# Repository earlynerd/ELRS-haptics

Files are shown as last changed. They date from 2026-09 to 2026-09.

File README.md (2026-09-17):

# Haptic bracelet

Battery-powered attitude feedback for FPV flying, with eight haptic actuators around each wrist. An ESP32-C6 receives telemetry over ESP-NOW and controls eight M2003FC1AE/DRV2625 pods using the music robot's UART ring architecture. Each wrist uses a seven-cell parallel battery group: protected cells in pods 1-7, with no cell in the stacked controller pod. Seven 90 mAh cells give 630 mAh; 301730/160 mAh cells are an alternative candidate pending selection and fit checks.

## Open the two KiCad projects

| PCBA | Editable project | Quantity per wrist |
| --- | --- | --- |
| Controller daughterboard | [hardware/main/main.kicad_pro](hardware/main/main.kicad_pro) | 1 |
| Universal pod | [hardware/satellite/satellite.kicad_pro](hardware/satellite/satellite.kicad_pro) | 8 |

Each project has its own schematic and PCB. Shared custom libraries live under `hardware/`. Use KiCad 10; native files are the editable source of truth.

**JP1 defaults to 1-2 NORMAL. On the last satellite, cut the 1-2 copper bridge and solder 2-3 END.** Its centre pad feeds the upstream return, selecting downstream return or local TX. Never bridge all three. See [project structure and jumper configuration](docs/pcba-projects.md).

The former eight-island project is retained under `hardware/archive/combined-project/`, with the untouched starting snapshot and hashes under `hardware/backups/before-two-projects/`. Close any editor still showing the former root project and open the new projects above for further work.

## Schematics and layout

The main project has five sheets: the user's redrawn controller/power-switch top sheet, stacked universal-pod interface, charger/regulator, USB, and controller support. The satellite has one sheet. Support components are wired around their ICs; labels serve power rails and circuit/sheet interfaces.

[Main schematic PDF](hardware/verification/project-split/main.pdf) · [Satellite schematic PDF](hardware/verification/project-split/satellite.pdf) · [Satellite layers](hardware/verification/project-split/layers.png)

The redraw audit found no deleted components, changed values or changed footprint assignments. The new `+3V3` and `+3V3_POD` power symbols had split the old `3V3` and `POD_3V3` nets; those names are now consistent. An obsolete dangling QOD wire/label was removed. Fresh connectivity checks preserve the verified circuit apart from the documented selector, five-pad harness, reset removal and USB simplification.

Both boards now use the pod's full **20 × 46 mm, R2.5** outside contour. The universal skin-facing board has four M1.6 SMT standoff lands and no actuator cutout; the controller plate has matching 1.8 mm screw-clearance holes. The VLV041235L retains its factory adhesive. Drawing layers mark the TPU contact band and placement margin. See [PCB sandwich construction](docs/pcb-sandwich.md).

All existing electrical positions and routes are preserved, including the user's latest main placement. Both projects have zero ERC and schematic/PCB parity issues. The universal board retains 201 segments, 42 vias, zero DRC violations and zero opens. The controller has 146 opens and 21 DRC findings during placement, including clashes around the new mounts. Both active stackups remain four-layer, 0.8 mm; standoff height and thinner skin-plate trials are open. See [current architecture](docs/pcba-projects.md).

## System decisions

- Five wires run through seven gaps: switched supply, GND, forwarded UART data, protected VBAT and serial return. The compact five-pad banks use pin 4 for VBAT and pin 5 for return. The eighth gap has no conductor; the current housing uses paired planar U-flexures at all eight gaps and closes the flat strip at a seam inside the main shell.
- Each pod contains an M2003FC1AE, DRV2625YFFR and VLV041235L. PF0/PF1 preserve the loader UART/ICE pins. Driver NRST follows VDD; hard recovery cycles pod power.
- USB-C uses two 5.1k CC pull-downs and connects to ESP32-C6 native Serial/JTAG on GPIO12/13. VBUS directly feeds the charger; its internal limit replaces external USB current-switch circuitry. BQ25186 charges the protected pack, TPS63802 supplies 3.3 V, and TPS22918 switches all pod electronics.
- Every pod has local bulk capacitance, removable UART links, ICE pads and an optional cell thermistor interface. Each protected battery feeds VBAT through its local branch fuse; factory PCMs stay fitted.
- Main SW3 is the wake/ship button; D1 is the RGB status LED. Firmware must manage charging and UART pin states around power changes.

See [ring and power sequencing](docs/ring-pods.md), [power architecture](docs/power-architecture.md), [USB implementation](docs/usb-power-implementation.md), and [DECISIONS.md](DECISIONS.md).

## Firmware

The initial [bracelet firmware](firmware/README.md) now includes an ESP32-C6 controller, an M2003 haptic-pod application, the borrowed music-robot LDROM build, and portable protocol tests. The controller decodes MSPv2-wrapped CRSF attitude telemetry from a configured ExpressLRS Backpack sender, requires exactly eight enumerated pods, and drives a configurable absolute-attitude map at 50 Hz. The M2003 application controls one DRV2625 over local I2C and keeps the robot ring framing, enumeration, loader mailbox, image layout, and update packager.

The stacked hardware retains eight nodes but requires cell-temperature supervision on pods 1-7 only; that firmware policy and seven-cell charging limits remain to be implemented.

The first build defaults are deliberately inert until a Backpack source MAC is configured. Charging remains disabled. This code has been compiled, but it has not been flashed or exercised on bracelet hardware; see [firmware interfaces and open qualifications](firmware/protocol.md).

For staged hardware work, the controller now has a native USB [bring-up console](firmware/BRINGUP.md). It supports partial-ring enumeration, per-pod status and bounded single-actuator pulses without relaxing the eight-pod requirement for normal telemetry-driven output.

## Next work and manufacturing

Next establish the stacked daughterboard envelope, contact arrangement and placement before routing. JLCPCB is preferred; a later **derived panel** may combine one controller and eight identical universal pods. [hardware/panel](hardware/panel/README.md) is reserved for that output. No manufacturing panel or fabrication release has been created.

The exact production stack, USB geometry, enclosure supports/links, physical fit, battery sharing, power sequencing and haptic behavior remain to validate. Firmware is implemented as an initial buildable slice but has not been flashed. Loader compatibility is now build-verified against the inspected robot sources, not yet demonstrated on the bracelet ring.

`tools/verify_split_projects.ps1` refreshes both netlists, ERC/DRC reports and preservation checks. Current evidence is in `hardware/verification/project-split/`. Older construction scripts and routing directories document earlier revisions; do not use them to regenerate the active designs.

## References

- [Nuvoton M2003 datasheet](https://www.nuvoton.com/export/resource-files/en-us--DS_M2003_Series_EN_Rev1.00.pdf).
- [TI DRV2625 datasheet](https://www.ti.com/lit/ds/symlink/drv2625.pdf).
- [TI TPS22918 datasheet](https://www.ti.com/lit/ds/symlink/tps22918.pdf).
- [ESP32-C6-MINI-1 datasheet](https://www.espressif.com/sites/default/files/documentation/esp32-c6-mini-1_mini-1u_datasheet_en.pdf).
- [ExpressLRS backpack telemetry](https://www.expresslrs.org/software/backpack-telemetry/).

Power/USB source details and loader provenance are linked from the implementation documents.

The proposed [VLV041235L actuator and draft flex contact footprint](docs/lra-candidate.md) are documented separately; the actuator is assigned to main M1 and satellite M1.

The [dimensional pod study](mechanical/pod-study/README.md) uses the measured 195 mm wrist. Revision D proposes 20 x 38 x 10.5 mm regular shells and a 24 x 64 x 10.5 mm main shell, with one protected 3 x 12 x 32 mm battery bonded inside every lid. The main battery is allocated away from the antenna and USB/button/RGB end. Width around the wrist stays unchanged. These are nominal shell envelopes; revision 0.6 implements PCB outlines and fit coupons but has no physical fit evidence.

The current [Myo-inspired flat housing v0.11](mechanical/myo-flat-v0.11/README.md) supports the main-pod TPU against its sidewalls down to the satellite ends, so all sixteen free U-folds use the same geometry. Its main clamshell is cut from one rounded rectangular envelope, with integrated end walls and recessed M2 x 8 mm screws. Satellite shells, lids and joint geometry are preserved. The approximately 239 x 72 mm strip targets PET-GF15/TPU on the H2D; local support remains necessary under the terminal roof and wall feet. STL/3MF, STEP and main-transition/closure coupons are included. CAD, mesh and preservation checks pass; the user's slicer screenshot is v0.10 evidence, while v0.11 slicing, fit and flexure testing remain open. Earlier releases are preserved.

SW3 is the accessible wake/off button. D1 is a discrete common-anode RGB status LED on GPIO4/5/15, with individual resistors; the placement selects LTST-C19HE1WT and EVQPUJ02K, respectively. See [standby and controls](docs/standby-and-controls.md). Initial firmware uses blue for waiting, green for fresh telemetry/output, and red for a ring fault; final indication and button behavior remain open.

The [YDL301230-class battery baseline](docs/cell-candidate-301230.md) provides 630 mAh and 315 mA continuous aggregate current with seven equally sharing cells. Factory PCMs stay intact. New 22 uF pod capacitors and C42=4.7 nF ramp control are documented in [ring power](docs/ring-pods.md).

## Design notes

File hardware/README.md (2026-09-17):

# Hardware sources

Open `main/main.kicad_pro` and `satellite/satellite.kicad_pro` in KiCad 10.

- `main/`: one controller daughterboard PCBA; its haptic pod is a separate universal board.
- `satellite/`: one universal PCBA, built eight times per wrist. JP1 selects normal or end-of-chain operation.
- `HapticBracelet.kicad_sym`, `HapticBracelet.pretty/`: shared libraries referenced by both projects.
- `panel/`: future derived manufacturing panel, never the source for board edits.
- `verification/project-split/`: current schematic PDFs, previews and check reports.
- `archive/combined-project/`: superseded eight-island project, preserved intact.
- `backups/`: historical snapshots, including the saved user redraw before migration.

Both boards now use the regular pod's full 20 × 46 mm, R2.5 outside contour. Four M1.6 standoff lands on the universal lower board match four 1.8 mm clearance holes on the controller plate. Neither board has an actuator opening. Cmts.User marks the 1.2 mm TPU contact band; Dwgs.User marks a 1.5 mm placement inset. Existing electrical positions and routes are preserved. See [PCB sandwich construction](../docs/pcb-sandwich.md) for mounting height and placement status. Schematics and boards are edited natively; construction scripts are migration provenance.

Current topology and checks: [stacked controller architecture](../docs/pcba-projects.md). Pod 0 has no cell or external NTC; pods 1-7 have both.

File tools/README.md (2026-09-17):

# Hardware scripts

The active designs are native KiCad projects under `hardware/main/` and `hardware/satellite/`.

## Placement measurements

Save the PCB, then run from the project root:

```powershell
./tools/evaluate_placement.ps1
./tools/evaluate_placement.ps1 -ExcludeNet '^GND$'
./tools/evaluate_placement.ps1 -Compare 'hardware/verification/placement-score/PREVIOUS/placement.json'
```

Each invocation creates a timestamped report directory and leaves the PCB untouched. `placement.md` is the readable report; `placement.json` contains every measured connection, per-net and incident-component totals, source hash and KiCad version. `drc.json` and `drc.log` retain the native checks. `-Board` selects another PCB; `-Out` selects an explicit output directory. Comparison requires matching pad/net topology and filters. Unsaved editor placement is not visible to this tool.

Two distinct measures are reported: fresh KiCad DRC unconnected endpoint spans (remaining airwires), and a Euclidean minimum spanning tree over each net's copper pad centres (routing-independent placement proxy). Reported statistics are count, total, mean, median, nearest-rank P95 and maximum, in mm. Every copper pad is included, including same-footprint/duplicate-number pads; coincident pads contribute zero-length edges. The latter can change the mean relative to KiCad's ratsnest even when totals agree. No nets are excluded by default. Ground-only filtering is useful but does not imply all other nets are signals.

The remaining-airwire measurement is an estimate reconstructed from native unconnected item pairs and nearest pad-centre/track-end/via anchors, rather than direct access to the editor's displayed ratsnest. DRC track positions identify a track's start, so the tool resolves the nearer endpoint. Unsupported endpoints such as zone objects cause an explicit error rather than an invented distance. This is tested on unrouted, partially routed and fully routed fixtures.

Use total length to compare placements of the same circuit. Existing routing, planes, layer transitions, obstacles, trace width and electrical priority are not modeled by the placement tree. Native DRC uses saved zone fills without modifying/refilling them. Short circuits can also affect native connectivity, so inspect DRC alongside the metrics. A lower score is not a fabrication or placement acceptance gate. Critical power loops, decoupling, RF/USB, enclosure constraints and courtyard clearance remain separate checks.

Tests (KiCad Python):

```powershell
& 'C:/Program Files/KiCad/10.0/bin/python.exe' tools/test_evaluate_placement.py
```

Run `verify_split_projects.ps1` to export current netlists, run ERC/DRC and verify preservation of the accepted circuit/placement. It does not regenerate schematics or PCBs. The comparison baseline must be deliberately updated when future circuit or placement changes are accepted.

`redraw_projects.py`, `readable_schematic.py`, `split_pcb_projects.py`, `route_satellite_selector.py` and `render_split_projects.cjs` record the two-project migration. Mutation entry points require explicit migration flags and are not incremental editors. In particular, repeating the selector router would duplicate tracks.

Earlier scripts target the archived eight-island architecture. Their reports remain in historical verification directories; they are not the active validation or generation workflow. Do not run an old generator against the new project structure.

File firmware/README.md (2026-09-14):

# Bracelet firmware

This directory contains the first firmware slice for one wrist:

- `common/` is portable C for ring framing, MSPv2/CRSF attitude decoding, and the configurable eight-pod attitude map.
- `controller/` is the ESP32-C6 ESP-IDF application. It receives ExpressLRS Backpack CRSF telemetry over ESP-NOW and masters the 250 kbaud pod ring.
- `pod/` is the M2003FC1AE application plus a build wrapper around the proven music-robot LDROM and support sources.
- `tests/` exercises the portable protocol core without hardware.

The checked-in defaults are intentionally safe. The charger enable remains low. Pod power starts off. Haptics are sent only after exactly eight applications enumerate and a configured Backpack sender supplies a fresh, valid attitude frame. Loss of telemetry or ring echo requests an all-stop.

The ESP32-C6 also exposes a native USB Serial/JTAG bring-up console. It can enumerate a partial ring, inspect DRV2625 calibration/status, exercise one actuator with a bounded pulse, display the most recent attitude frame, stop output, and power-cycle the pod rail. Bus and actuator diagnostics latch manual mode; normal telemetry control resumes only after an explicit `hb flight` command and only with eight enumerated pods. See [BRINGUP.md](BRINGUP.md).

This is build evidence, not flashed-hardware evidence. Rail timing, UART signal integrity, loader interception, DRV2625/LRA tuning, temperature conversion, charging policy, and the final wrist-direction map remain bench work.

## Build

Controller (PlatformIO, ESP-IDF):

```powershell
pio run --project-dir firmware/controller
```

Portable tests (CMake plus any desktop C compiler):

```powershell
cmake -S firmware/tests -B firmware/tests/build
cmake --build firmware/tests/build
ctest --test-dir firmware/tests/build --output-on-failure
```

Pod application and unchanged borrowed LDROM:

```powershell
make -C firmware/pod ROBOT_ROOT=C:/Users/mmsyl/Documents/bl4818-servo-M23_2 images
```

The M2003 build fails early if `ROBOT_ROOT` does not contain the expected support tree. This makes the current provenance visible rather than silently copying a second vendor BSP. Pin and image-layout details are in [protocol.md](protocol.md).

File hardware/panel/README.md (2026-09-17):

# Future manufacturing panel

Panelization is deferred until both individual PCB designs are complete.

The intended starting quantity is one controller daughterboard plus eight identical universal pods per wrist. Both designs are four-layer, nominally 0.8 mm. All satellites use the same Gerbers and assembly configuration; the final satellite's JP1 is changed by cutting 1–2 and soldering 2–3.

Create a future panel here as a derived output from `../main/main.kicad_pcb` and `../satellite/satellite.kicad_pcb`, recording source hashes and the selected JLCPCB stack and panel rules. Keep BOM/reference namespaces unambiguous between PCBAs. Rails, tabs, breakaways, fiducials, tooling and assembly outputs will be chosen at that stage.

Do not edit individual circuits in the panel. No panel PCB or fabrication exports have been created here.

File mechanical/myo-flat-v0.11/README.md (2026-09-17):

# Main-pod refinement — v0.11

This revision addresses the user's v0.10 slicer screenshot. The long TPU sections beside the main pod now contact its outside walls down to the satellite end positions (local Y=±22 mm). All sixteen free U-folds use the same geometry, with a 1.2 × 9.5 mm ribbon cross-section. Matching free geometry removes the deliberately longer main free legs; actual joint stiffness still needs a printed trial.

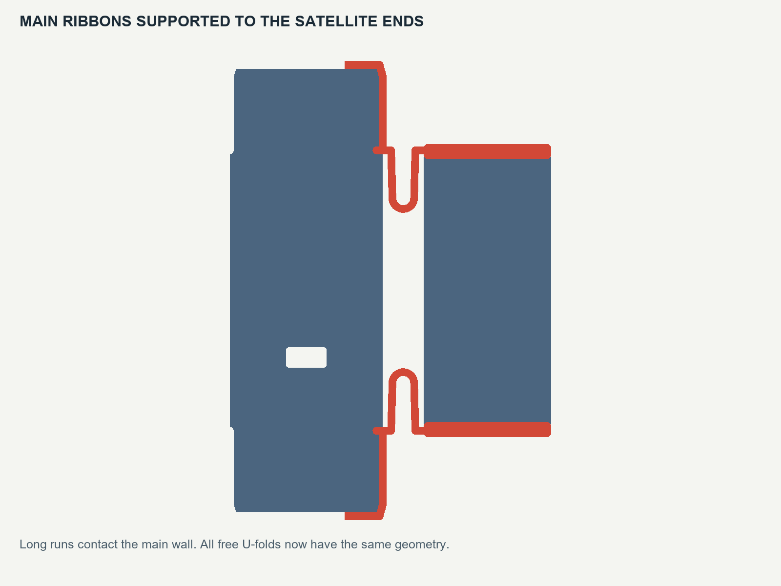
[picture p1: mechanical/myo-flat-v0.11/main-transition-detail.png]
Supported main transition


The main case is rebuilt by subtracting the cavity, access openings and mating cuts from one **24 × 72 × 11.5 mm rectangular envelope with rounded corners**. It closes into a continuous box exterior, with the service openings retained. Continuous internal end walls replace the isolated standoffs. Two cavity depths leave the PCB bearing ledges in the original solid. The wrist-facing floor and outward-facing roof still print at opposite strip ends.

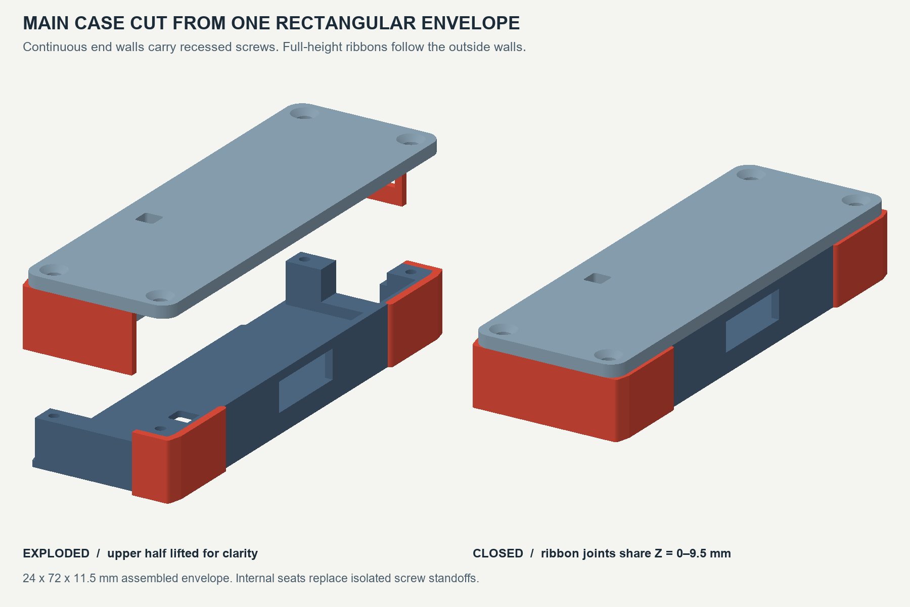
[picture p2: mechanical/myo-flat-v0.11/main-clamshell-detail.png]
Main case assembly

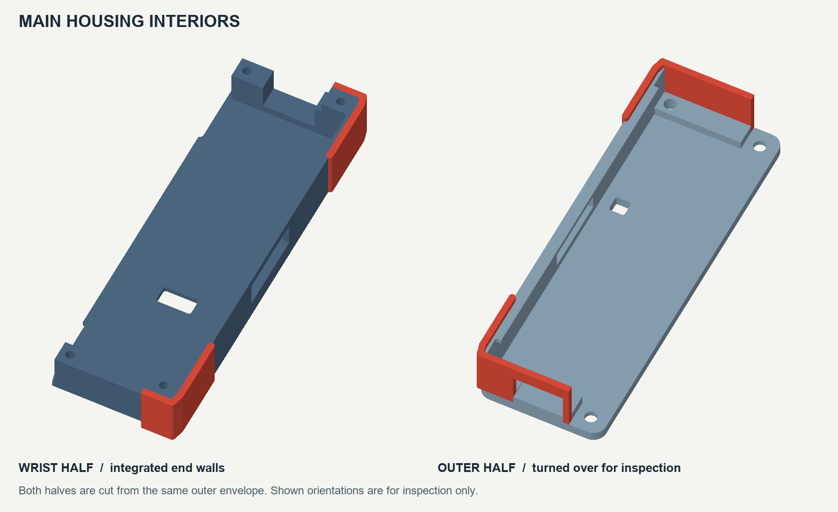
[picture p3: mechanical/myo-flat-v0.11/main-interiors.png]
Both interiors


The stepped seam keeps the ribbon ends at a common Z=0–9.5 mm. They butt together at the wall handoff when the case closes. Pockets in the lower half receive the upper half's TPU inlays. Main end ribbons are 1.2 mm wide; satellite embedded end rails remain 2.4 mm wide. The narrower main inlay leaves 1.2 mm of nominal rigid material between each end-wall pilot and the adjacent cavity/inlay boundary. A local USB cutout remains in the embedded rail, clear of the butt joints and free folds.

## Files and printing

| File | Purpose |
|---|---|
| [Full strip 3MF](print/myo-flat-band.3mf) | One dual-material strip, nine rigid pieces forming eight assembled pods |
| [Satellite lid](print/satellite-lid.stl) | Print seven; main roof is already in the strip |
| [Main transition coupon](print/main-transition-coupon.3mf) | New supported main-to-satellite joint |
| [Main fit parts](print/main-clamshell-fit-parts.stl) | Both main halves for a small fit trial |
| [Terminal closure coupon](print/closure-transition-coupon.3mf) | Upper main half and last satellite |
| [Satellite coupon](print/end-flexure-coupon.3mf) | Retained two-satellite joint |
| [Flat STEP](cad/flat-strip.step) | Full strip with separate rigid and soft bodies |
| [Assembled main STEP](cad/main-clamshell-assembled.step) | Both main halves at their closed datums |
| [CAD source](../../tools/build_myo_flat_v011.py) | Editable generator |
| [Overview](design-overview.png) | Actual flat meshes and illustrative oval pose |

The **239.2 × 72 × 11.5 mm** strip retains the H2D layout. Assign PET-GF15 and TPU to the aligned rigid/soft parts and retain their common coordinates. The generic 3MF contains material labels, not a printer process preset; bonding remains slicer-managed as requested. Support is still needed under the terminal main roof and wall feet. Do not independently drop the upper rigid half to the bed: its wall feet start at Z=1 mm while its attached TPU starts at Z=0. Satellite shells, lids and free joint geometry are retained.

**Main fasteners change to four M2 × 8 mm countersunk screws.** Modeled engagement is 4 mm in the two internal end walls and 6 mm on the opposite side, with 1 mm tip-to-pilot-bottom clearance. Satellite fasteners remain fourteen M2 × 5 mm countersunk screws. Seats assume 90-degree heads, 4.1 mm diameter, and 1.6 mm pilots. Check pilot fit and torque using the main fit parts in the chosen PET-GF15.

Print the new main transition coupon and clamshell fit parts first. Check sidewall bonding, equal/unequal fold motion, support removal, case closure and screw fit before the complete band. Keep the seven wired gaps and one unwired gap; populated component fit, board retention and harness strain relief remain physical development work.

## Evidence

`cad-checks.json` records valid CAD and STEP reimports, board/cell/USB clearance, all sixteen neighbor contacts, four main sidewall-contact gauges, full-height butt-joint gauges, and sampled closing motion including attached TPU. `revision-checks.json` compares retained satellite geometry against the frozen v0.10 STEP. `mesh-checks.json` checks the raw exported STLs, and `delivery-checks.json` verifies archive structure and previous-release/source preservation.

The user supplied a **v0.10 slicer view**. **v0.11 is CAD/mesh checked, but has not been sliced, printed or fit-confirmed.** Joint stiffness, fatigue, comfort and operating performance are not established by these checks. The oval pose is illustrative rather than a mechanics simulation.

Regenerate with build123d: `python tools/build_myo_flat_v011.py --wrist-mm 195 --wall-mm 1.2`. Rendering uses NumPy/trimesh/Pillow and `tools/render_myo_flat_v011.py`. The ZIP includes the generator, earlier helper modules, and read-only PCB/dimension inputs. Earlier revisions are preserved.

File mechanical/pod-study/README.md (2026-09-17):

# Historical packaging study D

The dimensions below established the envelopes. [Revision 0.6 placement](../../docs/pcb-placement.md) and [fit coupons](../fit-mockup/README.md) now implement the next step. The native cutout is shifted 1 mm left and its flex lands are near an end, so the centred actuator and mid-side flex drawings here are superseded. USB/button/RGB footprints are now selected. These study images remain historical references rather than the latest component placement.

# Pod packaging study D

User wrist circumference: **195 mm**, supplied on 2026-09-12. Axial width has not been specified; all other dimensions below are design proposals. View `pod-dimensions.svg` or `pod-dimensions.png`. Regenerate the SVG and parameter record with `python tools/sketch_pods.py` from the project root.

| Envelope | Around wrist | Along arm | Radial thickness |
| --- | ---: | ---: | ---: |
| Regular pod shell | 20 | 38 | 10.5 |
| ESP32/USB pod shell | 24 | 64 | 10.5 |
| Regular PCB | 17 | 35 | 0.8 |
| Main PCB before antenna relief | 21 | 61 | 0.8 |
| Central PCB opening | 7 | 15 | through |
| Battery body, each of eight pods | 12 | 32 | 3.0 |
| Lid battery allocation, excluding adhesive | 14 | 34 | 3.5 |

All dimensions are mm. These are nominal flat packaging envelopes, not fabrication geometry or a demonstrated component placement. The main pod grows primarily along the arm to retain circumferential room for eight actuators. Both drawings center the actuator and link positions on the same axial datum. Rounded end contours and link symbols are illustrative; exact retention details are open.

## Actuator and cell stack

The opening leaves nominal 0.8 mm clearance per side around a proposed 5.4 x 13.4 mm housing mounting seat. The actuator's 4 x 12 mm metal body leaves another 0.7 mm per side on the seat. Allowance for the flex tail, its bend and solder access is still to be resolved using a sample. The flex is drawn symbolically rather than as a production contour.

Radial coordinates start at the flat inner skin-contact datum: inner wall z=0..1, actuator adhesive z=1..1.5, LRA body z=1.5..5, and a conservative separate 0.35 mm foam allowance up to z=5.35. The battery allocation occupies z=5.8..9.3, leaving 0.45 mm nominal clearance above the actuator foam allowance. A proposed 0.2 mm adhesive layer occupies z=9.3..9.5 and bonds the cell directly to the lid, which ends at z=10.5. There is no shelf or separate cell compartment. The PCB occupies z=2..2.8 with regular-pod component tops allocated below z=4.8. Local component and solder heights must be checked during placement.

The [Vybronics A/2 drawing, page 10](https://www.vybronics.com/wp-content/uploads/datasheet-files/Vybronics-VLV041235L-datasheet.pdf) gives the body, 0.5 mm adhesive and a separate 0.35 mm foam callout. The study reserves these additively until the actual assembled sample resolves their installed stack. The 10.5 mm thickness does not yet include changes needed for a curved contact surface, closure details or shell deflection.

Bond one protected 3 x 12 x 32 mm battery inside every lid; keep its factory PCM. The 14 x 34 x 3.5 mm allocation gives 1 mm around the body in plan and 0.5 mm additional radial allowance, plus 0.2 mm lid adhesive. These are provisional clearances, not supplier-qualified expansion or wire-bend allowances. Plan soldered protected-output leads, with the external connector removed; no pocket is allocated for the stock PH2.0 plug. Leave lead slack to open the lid, and keep PCM/tabs insulated and strain relieved. There is no separate compartment or shelf.

## Controller pod

Revision D retains provisional side access for the existing SW3 wake/off button and a lid window for D1 RGB status. Both sit near the USB end, away from the antenna. Symbols indicate packaging allocations, not selected component outlines. BOOT and RESET remain internal recovery controls. The LED is discrete common-anode RGB; its package and the button actuator still need selection.

The ESP32-C6-MINI-1 body is 13.2 x 16.6 x 2.4 mm per the [Espressif module datasheet](https://www.espressif.com/sites/default/files/documentation/esp32-c6-mini-1_mini-1u_datasheet_en.pdf). Its antenna faces an axial end of the shell. The sketched relief indicates intent only; final copper, PCB and component clearances must follow the [ESP32-C6 layout guidance](https://docs.espressif.com/projects/esp-hardware-design-guidelines/en/latest/esp32c6/pcb-layout-design.html). Keep the antenna region clear of cells and metal covers. Body-loaded RF performance remains untested.

USB occupies a proposed 9 x 7 mm plan allocation at the opposite axial end, with opening and plug insertion room still dependent on the selected receptacle. MCU, driver and power blocks show area allocation only, not all 269 schematic components placed. Two-sided placement may be needed. No PCB outline has been changed.

## Circumference and flexible links

Seven regular widths plus one main width total 164 mm. Subtracting from the measured 195 mm leaves 31 mm, or 3.875 mm per gap. **That is a first flat-length budget, not a relaxed link dimension or a circular fit solution.** Wrist shape, chord/arc geometry, radial location of link anchors, tension and clearance change it. A circular equivalent of the measured circumference has radius about 31.0 mm, but a wrist is not circular and that radius is not specified as the final shell curvature.

Use paired Myo-inspired TPU U-flexures at all eight mechanical gaps and co-print them with the rigid pod shells as one claspless band. The electrical chain remains open: only seven gaps carry the current five-conductor harness, and no conductor crosses the eighth TPU seam. The old 31 mm remainder and 3.875 mm equal-gap value are flat-length estimates only. Revision 0.7 instead places the retained pod widths as tangent chords on a 195 mm circular skin reference and divides the remaining skin arc equally; wrist ovality, preload, wire slack, material stiffness and flexure fatigue remain physical checks.

## Verification scope

Checked the manufacturer actuator drawing and module body dimensions. Rendered the generated SVG and visually inspected it for dimension-label overlap and readable section details. This study has no assembled CAD, boolean fit checks, routing validation, antenna validation or printed fit evidence. Its purpose is to choose packaging envelopes before PCB outlines and cells are fixed.

## Revision D battery placement

Each regular shell grows 4 mm along the arm. The main shell grows 12 mm along the arm so its lid can carry the eighth battery between the antenna end and USB end. Circumferential widths stay 20/24 mm; radial height grows 0.5 mm for additional battery allowance.

Coordinates below use the shell's left/antenna-side end as x/y=0 in the plan drawing. Regular battery allocation: x=3..17, y=2..36; main allocation: x=5..19, y=22..56. The body fits centered inside each allocation. The main USB block starts at y=57; the antenna body ends at approximately y=6.6, leaving over 15 mm to the battery allocation. This is a conservative packaging separation, not an RF qualification. Module height outside the battery region is not constrained by the regular-pod 4.8 mm component ceiling. The eight LRAs/link anchors retain a common axial centerline when the pods are worn.

Dashed overlays in the plan show the lid-mounted batteries above the board, not PCB cutouts. The capacitor 0805 footprint fits the component height allocation in principle; full board placement, capacitor MPN, lid closure, lead exit and wrist curvature remain unresolved. `dimensions.json` records these allocations and eight-cell intent; no fabrication PCB outlines have been generated.

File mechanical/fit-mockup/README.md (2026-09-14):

# First fit mockup — revision 0.6

Print **seven satellite shells/lids and one main shell/lid** from `print/`, in millimetres. These are simple flat fit coupons: 20 × 38 × 10.5 mm regular, 24 × 64 × 10.5 mm main when closed. Shells print floor down; lids print flat. The 14 mm wire mouths have a 2.4 mm-high opening and need a short bridge in an upright shell print; inspect the sliced bridge. Use temporary tape to retain the lids and an external elastic wrap for a wrist size trial. There are no clips, final TPU links or clasp yet.

The `reference-only/` meshes are rigid **nonfunctional gauges**, kept separate from printable housing parts. The cell gauge represents only the nominal 12 × 32 × 3 mm protected battery body, not leads, expansion or tolerance. The LRA gauge excludes its adhesive, foam and flex tail. PCB gauges simplify the native board chamfers into square corners; use native PCB outlines for the eventual manufactured boards.

Cells bond to the lid inner surface; there is no compartment or shelf. The flat 1 mm shell floor is the LRA bonding surface. The PCB datum is 2 mm above the shell's wrist face. These first coupons do not include PCB retention/support ledges: use removable 1 mm spacers above the 1 mm floor for a bench fit trial. Do not populate cells during an unsupported PCB fit test. Final supports must avoid components and wire terminations.

Main shell openings follow the current USB and side-button placement; the LED has a 2.4 mm square lid window. No light pipe/button extender is modeled. The main cell allocation remains x=5..19, y=22..56 mm; regular allocation x=3..17, y=2..36 mm. Battery allocation z=5.8..9.3 mm, adhesive z=9.3..9.5 mm. Check a physical sample with its factory PCM and lead bend. LRA lands are 1 mm offset from the old centred-opening study to accommodate the tail.

`mesh-checks.json` records successful post-export watertightness, winding, single connected mesh, positive volume and dimensions for each STL. These checks establish mesh integrity only. The 195 mm wrist fit, curved contact pressure, material flexibility, cable strain, actual component heights, tail folding, lid removal, and RF performance remain physical design work.

Regenerate with the bundled dependency Python and `tools/build_fit_mockup.py`. Source geometry is the editable Python plus the native placement JSON. These STL coupons are not a finished wearable enclosure or STEP solids.

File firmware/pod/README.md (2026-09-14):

# M2003 haptic pod

This application preserves the music robot's M2003 startup, UART ring transport conventions, application-to-loader mailbox, flash layout, image packager, and LDROM sources. The local application replaces all motor behavior with one local DRV2625 and an LRA.

`ROBOT_ROOT` is an explicit build input. The default points at the adjacent `bl4818-servo-M23_2` checkout used during development. A reproducible release should pin or vendor a reviewed revision before manufacturing.

The current DRV2625 values are conservative first-pass settings for the proposed VLV041235L (240 Hz, 1.8 Vrms rated, 1.85 Vrms operating maximum). Every actuator is auto-calibrated after power-up. The calibration values, thermal behavior, perceived mapping, and drive limit need bench validation before wear testing.

PB2 temperature conversion is not claimed in this first slice. Status reports mark temperature unavailable, and the ESP32 controller never enables charging.

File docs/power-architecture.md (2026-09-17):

> **2026-09-14 architecture:** one controller daughterboard, eight universal haptic pods, seven protected cells and required cell NTCs on pods 1-7. Pod 0 has neither external connection. The 301730/160 mAh suggestion is a candidate pending exact part and protected-pack fit/rating checks; seven would give 1,120 mAh. Firmware charge/load settings must follow the selected seven-cell pack.

# Bracelet power architecture

> Project update (2026-09-13): active sources are `hardware/main/` and `hardware/satellite/`. Main references are unchanged; historical satellite references map to the one universal design in [PCBA projects](pcba-projects.md). Any combined-board placement/count or verification statements below describe the earlier checkpoint; [current routing status](pcb-routing.md) supersedes them.

Status: seven protected 90 mAh batteries, one in each of pods 1-7, connected as **1S7P per wrist**. Native revision 0.5 removes the central protector and adds local bulk capacitance. The YDL301230 protected assembly establishes a 3 x 12 x 32 mm body envelope. Capacity is 630 mAh nominal; runtime and physical load qualification remain open.

## Electrical arrangement

Use one permanently assembled group of seven identical protected pouch batteries per wrist. Keep the factory PCM intact on every battery. Connect PACK+ through its local positive-branch fuse to VBAT; connect PACK- to system GND. Raw cell terminals do not connect directly to the bracelet PCB. There is no central ABLIC protector, shunt or protection FET pair.

```text
Battery 1 (factory PCM) PACK+ -- fuse --+
Battery 2 (factory PCM) PACK+ -- fuse --+-- VBAT <--> BQ25186 BAT
...                                    |
Battery 7 (factory PCM) PACK+ -- fuse --+
All protected PACK- leads ---------------- GND

USB-C --> power-path charger SYS --> buck-boost --> 3V3 (ESP32/control)
                                                   +-- TPS22918 --> POD_3V3
                                                       eight MCU/driver pods
                                                       +22 uF bulk per pod
```

VBAT is harness pin 4, the combined protected battery-output bus. It connects directly to U11 BAT and C36. It remains live when POD_3V3 is off or the charger is in ship mode. J4/F1 on pods 1-7 carry their protected battery outputs. Pod 0 J4 is unwired. The daughterboard has no battery branch; its J101 pin 4 receives VBAT. See [protection implementation](pack-protection-implementation.md).

Each factory PCM monitors its own cell and can disconnect independently. The remaining branches then share the load and charging current. Individual PCMs are not equivalent to the removed aggregate current cutoff; final fuse ratings and charge/load policy must account for branch loss, unequal sharing and actual PCM recovery behavior. PCB connectivity checks cannot verify those external protection functions.

While their PCMs conduct, cells in the permanently connected group share approximately the same voltage, so series-cell balancing is not required. Use the same cell model/chemistry and suitably matched condition; equalize voltage with controlled current before assembling the permanent parallel connections. Do not make independently removable/hot-swappable cells part of this baseline: reconnection would need an additional controlled-current/isolation design.

Plan for 4.20 V-charge, nominal 3.7 V batteries matching the YDL example. Its ratings give 45 mA maximum continuous discharge per cell, **315 mA total with seven equally sharing branches**, or 1.1655 W at nominal voltage. Standard charge is 18 mA per cell (126 mA aggregate), maximum 45 mA (315 mA aggregate). These aggregate values are not safe defaults when branches have disconnected; final charger settings and recovery policy remain firmware work.

## Charger: BQ25186

The TI BQ25186 provides 1S CC/CV charging, power-path load sharing, 5 mA to 1 A programmable fast-charge current, thermistor monitoring, ship mode and button wake. It can sit on the main-board I2C bus at 0x6A with the former TUSB320 CC controller removed. Each pod controls its own DRV2625 at 0x5A on local I2C.

USB supplies SYS when connected, and the battery supplies SYS when unplugged. The power path separates system load from battery charging so continued device operation does not inherently prevent proper charge termination. Available input current is shared with the load; charging can slow or pause when the load consumes the source budget.

For this design retain a 4.5 V SYS regulation setting while externally powered (the register default); battery-only SYS follows the battery through the battery FET. Do not select 5.5 V or pass-through modes with a TPS63802 downstream without rechecking its maximum input voltage, tolerance and transients.

Use a charge-disable hardware state until the cell-specific settings and temperature conditions are valid. Check cold start, watchdog/register reset and depleted-pack recovery as part of implementation. BQ25186 is a linear charger: the first-order charging loss is (Vin - Vbat) * Icharge, with additional loss from the system power path. As an illustration, 5 V input, 3.7 V battery and 200 mA charging dissipate about 0.26 W from charging alone; 200 mA is not a selected charge setting.

USB-C 5 V is the selected charging interface, with D-/D+ also connected to native ESP32-C6 Serial/JTAG. Two 5.1k CC pull-downs provide sink termination; no CC controller is fitted. USB Power Delivery is not required for this 5 V design. Do not infer permission to draw 1 A from the charger IC rating alone.

## Regulator: TPS63802 at 3.3 V

A buck-boost supplies 3.3 V as the source moves above and below that voltage. It also accepts the charger's higher SYS voltage when externally powered. TI specifies 2 A output at 3.3 V for input >= 2.3 V. This is component capability, not a proven bracelet current budget; inductor, effective capacitance, layout, temperature, battery impedance and protection must all support the intended load.

The regulated 3V3 rail supplies the ESP32 and main-board control. A TPS22918 switches all eight pod MCUs and drivers onto POD_3V3, with local decoupling. Firmware prevents UART back-powering by driving TX low and disabling the RX pull-up before shutdown. See [ring pods](ring-pods.md) for the reset circuit, interconnect and power sequence. Actuator headroom and simultaneous-current budget remain to be checked after LRA selection.

The charger/regulator and supporting circuit are in the native schematic. The former protection child sheet is archived under `hardware/backups/before-protected-cells/`; the active main project has five sheets and the satellite project one. The former charger thermistor connector is removed; controller J3 now denotes ESP recovery pads. Universal pod J5 connects each cell thermistor to its local M2003 ADC; it is unwired on pod 0. R62 (10k) terminates charger TS/MR to GND, with SW3 in parallel; temperature supervision is performed by firmware. Universal J4/F1 provide the protected battery branches on pods 1-7 only. Five-pad harness interfaces and Littelfuse 0467.250NR 250 mA branch fuses are assigned.

## Distributed mechanics and temperature

Treat each pouch location as a supported segment, with flex occurring in the strap/interconnect between segments. Preserve the cell supplier's clearance/expansion allowances, insulate tabs, and provide strain relief so strap motion does not load the cell tabs. Keep actuator forces and sharp PCB edges away from pouch faces. Use short, low-resistance branch wiring; account for branch resistance when evaluating current sharing.

Plan temperature sensing at each separated pouch location. There is no independent charger thermistor. All eight universal pod boards retain their M2003 ADC/NTC input circuitry; pod 0 has no external NTC connected. Firmware must inhibit charging if any required cell reading is missing, stale or outside its specified temperature range. Sensor selection, required-cell configuration and firmware remain open. Charging must be disabled before ring power-off or loader entry when it relies on those readings.

## Sizing method

For N identical cells, nominal pack capacity is N * Ccell; voltage remains one-cell voltage. First estimate runtime from energy:

    runtime_hours ~= N * Ccell_Ah * Vnom * conversion_efficiency / average_load_W

Eight 90 mAh, 3.7 V cells contain 2.664 Wh nominally. With an illustrative 85% usable-energy/conversion factor, this gives about 2.26 hours at 1 W or 4.53 hours at 0.5 W. These are energy scenarios, not runtime predictions; continuous-current limits also apply. Cutoff, aging, rate and temperature affect usable energy.

Check peak current separately: the pack must support coincident ESP32 radio activity and the allowed simultaneous haptic outputs, including at low state of charge. Firmware mapping duty cycle determines average actuator energy. Charge settings and allowed haptic load should follow those measurements and the battery ratings; the planned cell count is seven.

## Sources inspected

- [TI BQ25186 datasheet](https://www.ti.com/lit/ds/symlink/bq25186.pdf): power path, charging, thermistor, modes, address and SYS register.
- [TI TPS63802](https://www.ti.com/product/TPS63802) and [datasheet](https://www.ti.com/lit/ds/symlink/tps63802.pdf): input/output range and specified current capability.
- [TI DRV2625 datasheet](https://www.ti.com/lit/ds/symlink/drv2625.pdf): supply range and I2C pin voltage constraint.
- [TI battery protector overview](https://www.ti.com/product-category/battery-management-ics/battery-protectors/overview.html): voltage, current and short-circuit protection functions.

Pack/interconnect arrangements above are engineering proposals for this device. None of these IC datasheets qualifies the as-yet-unselected distributed pouch pack.

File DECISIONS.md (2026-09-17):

# Decision Log

Forward-facing, append-only record of architectural and behavioral decisions for this project. Search this file when structural history can affect the task; newer applicable decisions supersede conflicting older statements.

When a decision is reversed or superseded, append a new entry rather than rewriting the old one.

## 2026-09-11 - Eight-channel attitude-feedback wrist unit

- **Decision:** Start one reusable KiCad design for each wrist: ESP32-C6, an eight-channel I2C mux, and eight DRV2625-controlled actuators; receive craft telemetry through the ELRS ESP-NOW backpack path.
- **Why:** The user wants a spatial mechanosensory attitude cue and has selected the mux architecture. Assembly difficulty is not a design constraint. Do not substitute thrust or angular-rate feedback for the user's attitude-feedback goal.
- **Supersedes:** (initial)
- **Affects:** hardware/haptic-bracelet.kicad_sch, hardware/haptics.kicad_sch, README.md.

## 2026-09-11 - Initial schematic implementation choices

- **Decision:** Provisionally use an ESP32-C6-MINI-1, TCA9548APWR at 0x70, and DRV2625 YFF pin maps with no driver footprint assigned. GPIO6/7 provide SDA/SCL; GPIO18 resets the mux; GPIO19 releases the shared driver reset. A common 3V3 rail is assumed pending actuator/power selection.
- **Why:** Establish an editable, connected schematic while keeping package, supply, actuator and mechanical decisions explicit. Module choice and GPIO assignments are starting proposals. TI sources currently inspected identify the YFF pinout only.
- **Supersedes:** (initial implementation)
- **Affects:** hardware/, README.md. The battery/power sheet is reserved; the PCB is initialized without layout.

## 2026-09-11 - Distributed 1S parallel battery pack

- **Decision:** Each wrist uses one series cell group with an open number of parallel pouch cells (1S-NP). Leave capacity, cell dimensions and runtime target open. Cells may occupy separate bracelet segments.
- **Why:** The user explicitly capped the series count at 1S and requested flexibility in the number of parallel cells.
- **Supersedes:** Previously unspecified series/parallel battery topology.
- **Affects:** README.md and docs/power-architecture.md. The proposed charger, buck-boost regulator and protection implementation remain design candidates pending circuit work and cell selection.

## 2026-09-11 - USB-C power and native ESP32-C6 Serial/JTAG

- **Decision:** Use USB-C 5 V input and route USB2 D-/D+ to GPIO12/GPIO13. Implement BQ25186 charging and TPS63802 regulation. TUSB320LAI provides sink-only CC/current detection at 0x47. Add hardware startup current limiting and default-disabled charging; higher input current requires source permission.
- **Why:** The user accepted the power plan and requested native USB data on the charging connector. BQ25186's 500 mA input-limit default alone does not address preconfiguration USB operation. The native C6 interface supplies flashing, console and JTAG.
- **Supersedes:** Candidate-only power implementation and UART-only wired programming.
- **Affects:** hardware/usb.kicad_sch, hardware/power.kicad_sch, controller GPIOs, docs/usb-power-implementation.md. Protected 1S pack construction, cell limits, final footprints, firmware and physical validation remain open.

## 2026-09-11 - M2003 UART ring pods with shared reset

- **Decision:** Use eight M2003FC1AE/DRV2625/LRA pods per wrist, with the ESP32 as master of the music robot's 250 kbaud UART ring. Retain its enumeration, LDROM update protocol, and flash layout. Add a shared active-low M2003 reset; keep each driver's I2C local to its pod. One pod also houses the ESP32 and power electronics. Design pin assignments around the loader's existing startup outputs to minimize loader changes.
- **Why:** The user has these MCUs on hand and reports excellent ring operation and fast, reliable updates on the music robot. Reuse removes interface ICs and reduces each ordinary inter-pod link to power, ground, forwarded data, and reset; battery wiring is additional.
- **Supersedes:** Central I2C fanout in the first two entries; subsequent local-mux, translator, and I2C-loader proposals.
- **Affects:** Pod hardware, ESP32 host, pod application, and update tooling. Native schematics and README still describe the earlier mux circuit; migration and bracelet validation remain pending.

## 2026-09-12 - Switched pod power with firmware-managed UART states

- **Decision:** Switch all eight M2003/DRV2625 pods from 3V3 through TPS22918; leave ESP32 and charging control powered. GPIO3 enables power with a default-off pulldown. GPIO18 asserts shared reset through an NMOS with its reset pull-up on POD_3V3. Use GPIO19 TX and GPIO2 RX directly: assert pod reset, detach UART, drive TX low and disable the RX pull-up before power-off. Preserve PF0/PF1 loader UART pins and use PB13 for local driver reset. Disable charging before losing required pod temperature reports.
- **Why:** The user requested ring power shutdown and proposed GPIO states to avoid unnecessary signal isolators. The loader already drives PB13 low.
- **Supersedes:** Always-powered pod assumption; proposed UART isolation buffers. Implements the earlier M2003 UART ring decision in native schematics.
- **Affects:** Controller and pod schematics, ring firmware contract, docs/ring-pods.md. Firmware and bench validation remain open.

## 2026-09-12 - Fifth conductor for distributed parallel cells

- **Decision:** Add VBAT_RAW as pin 5 on every IN/OUT interface, alongside switched 3V3, GND, DATA and shared reset. Each populated cell branch joins VBAT_RAW through a local positive fuse. Define a high-side bidirectional pack protector interface at the main power board, keeping raw and protected positive rails separate with common GND.
- **Why:** The user explicitly requested the battery conductor needed to parallel distributed cells. Positive-path protection permits one common ground without bypassing a low-side disconnect.
- **Supersedes:** Four-conductor descriptions that excluded battery wiring. The ordinary inter-pod harness now has five conductors.
- **Affects:** Pod interfaces, power sheet J4, docs/ring-pods.md and power architecture. Cell/fuse selection and the actual pack protection circuit remain open.

## 2026-09-12 - VLV041235L flex contact candidate

- **Decision:** Evaluate the user-proposed VLV041235L with direct flex-to-PCB solder pads. Add a contact-only draft footprint with 1.8 mm pitch and separate body retention; leave schematic actuator placeholders until selection and fit are confirmed.
- **Why:** Vybronics explicitly supports direct PCB attachment of the double-sided flex contacts. Body placement remains a mechanical choice.
- **Supersedes:** No actuator candidate or contact geometry.
- **Affects:** hardware/HapticBracelet.pretty and docs/lra-candidate.md. S-821AAAI protector sourcing remains unresolved; other suffixes are not threshold-equivalent substitutes.

## 2026-09-12 - Central actuator opening and flexible pod links

- **Decision:** Use the user's proposed central LRA and housing mounting seat projecting through an opening in each pod PCB as the working packaging concept. Reserve surrounding volume for electronics and optional thin pouch cells; use Myo-inspired flexible links between rigid pods. Dimensions and exact link construction remain open.
- **Why:** Nesting the actuator within the PCB plane can reduce stack height and keeps its mechanical attachment to the wrist-facing housing independent of the board. Cell selection must fit the remaining usable volume, including tabs and clearance.
- **Supersedes:** Previously unspecified PCB/body arrangement; does not select a compliant actuator suspension.
- **Affects:** Pod mechanical layout and eventual PCB outlines. No dimensional CAD or PCB cutout is implemented yet.

## 2026-09-12 - First pod dimensions for a 195 mm wrist

- **Decision:** Record the user's measured wrist circumference as 195 mm. Sketch provisional regular shells at 20 x 34 x 10.5 mm and a main shell at 24 x 52 x 10.5 mm (circumferential x axial x radial), with 7 x 15 mm central board openings. Explore an outer cell compartment supported above the actuator in regular pods; reserve the main pod for electronics.
- **Why:** Establish a concrete packaging study while leaving actual cells and link fit open. Grow the main pod mainly along the arm to preserve circumferential space for all eight actuators.
- **Supersedes:** Unspecified dimensions in the central actuator opening concept; these dimensions remain proposals, not user-approved fabrication geometry.
- **Affects:** mechanical/pod-study, docs/lra-candidate.md and future PCB outlines. No physical fit or component layout qualification is claimed.

## 2026-09-12 - Bond cells directly to pod lids

- **Decision:** Follow the user's direction to bond each optional pouch cell to the lid's inner surface, with no separate cell compartment or supporting shelf. Revise the provisional shell thickness to 10 mm, retaining clearance above the actuator and electronics.
- **Why:** The lid provides the required support without another printed structure. The revised sketch allocates 16 x 28 x 3 mm for the cell envelope plus 0.2 mm lid adhesive; actual cell, adhesive and tolerance allowances remain open.
- **Supersedes:** The supported cell compartment and 10.5 mm thickness in the first dimensional study.
- **Affects:** mechanical/pod-study, docs/lra-candidate.md and README.md. PCB outlines remain unchanged.

## 2026-09-12 - Release reset driver during steady pod power-off

- **Decision:** Assert Q5 during pod power-down, then drive RING_RESET_ASSERT low after POD_3V3 and the reset capacitor discharge. Keep it low throughout steady off and assert it again before enabling the pod rail. Preserve TX-low/RX-no-pull-up states.
- **Why:** The user rejected holding the reset driver high while pods are off. Releasing its gate eliminates about 33 uA through R7; the reset net's pull-up references the discharged pod rail.
- **Supersedes:** Holding reset asserted throughout the off interval in the switched pod power sequencing.
- **Affects:** docs/ring-pods.md and docs/standby-and-controls.md. No circuit change is required; firmware and discharge timing remain unimplemented/unqualified.

## 2026-09-12 - Accessible wake button and RGB status

- **Decision:** Expose existing SW3 as the user wake/off button and add a discrete common-anode RGB D1 on GPIO4/5/15 with separate 2.2k resistors and 100k default-off pullups. Add provisional main-shell side-button and lid-window positions. Keep BOOT/RESET internal.
- **Why:** The user wants a button and RGB indication including charge state. Direct GPIO drive adds no LED-controller standby load. GPIO15 is biased high for native USB JTAG; GPIO4/5 only affect unused SDIO timing straps.
- **Supersedes:** Unallocated user controls and the interim single-color LED addition. GPIO4/5 are no longer spare wake inputs.
- **Affects:** Native controller/support schematics, packaging study C and standby documentation. LED/button MPNs, footprints, brightness and firmware are pending; indication colors are an initial proposal.

## 2026-09-12 - Six-wire chain with passive serial return

- **Decision:** Add pin 6 RING_RETURN to both wiring interfaces on all eight pods. Join only the last pod's TX, after its existing 33-ohm resistor, to this return through R53 (0 ohm). Return runs passively through the intermediate boards to ESP GPIO2. Use seven wired links and a purely mechanical clasp between the end and main pods.
- **Why:** The user wants to open the bracelet without an electrical disconnect. This folds the logical UART ring into a physical chain while retaining its enumeration and loader protocol.
- **Supersedes:** Five-conductor wiring and a serial closing connection across the clasp.
- **Affects:** Pod interfaces, main RX, ring overview, connectivity checks and mechanical link planning. Pad footprints, harness signal quality and current capacity remain to be validated physically.

## 2026-09-12 - Select stocked S-821AAAC high-side protector

- **Decision:** Select ABLIC S-821AAAC-H8T7S, with nominal 4.590 V overcharge and 2.500 V overdischarge thresholds, as directed by the user. Preserve the six-wire harness and common ground.
- **Why:** It has the lowest overcharge threshold among the stocked high-side variants in the supplied DigiKey export. The user accepts this threshold while relying on the charger for normal regulation. This does not establish protection within a conventional 4.20 V cell's permitted voltage under charger failure; cell compatibility remains unverified.
- **Supersedes:** The unresolved S-821AAAI sourcing choice and rejection of stocked high-side variants solely on overcharge threshold.
- **Affects:** docs/protection-sourcing.md and subsequent central protection circuit implementation. FETs, sense resistor and native schematic implementation remain pending.

## 2026-09-12 - Implement central pack protector and prototype current cutoff

- **Decision:** Replace J4's placeholder with a protection child sheet: U27 S-821AAAC-H8T7S, common-drain CSD17318Q2 FETs Q6/Q7, a 3 mOhm shunt R54, and the ABLIC reference filter/input network. Keep the six-wire chain and common ground.
- **Why:** Complete the selected prototype circuit using stocked supporting parts. R54 establishes a nominal 1.93 A discharge cutoff; its rating remains adjustable once cells, wire and load are known. The fixed charge-overcurrent threshold is 6.67 A; normal charge current remains the charger's responsibility.
- **Supersedes:** J4's unimplemented protection boundary and pending circuit status in the preceding selection entry.
- **Affects:** Native power/protection sheets, ABLIC footprint, protection/connectivity checks and standby budget. U27 adds 6 uA typical during normal operation and charger ship mode; layout and physical fault/recovery tests remain pending.

## 2026-09-12 - Mark unused DRV2625 trigger pins no-connect

- **Decision:** Per user request, remove the eight A1 TRIG/INTZ ground stubs and place no-connect flags at U3 through U10. No ERC rule suppression.
- **Why:** These pins are unused in the I2C-controlled design; they have internal pull-downs. This is a prototype departure from TI's unused-pin grounding recommendation.
- **Supersedes:** Grounded TRIG/INTZ pins and eight unresolved ERC warnings introduced during this thread.
- **Affects:** Eight pod schematics, connectivity checks and firmware I2C-only control assumptions. ERC now reports zero violations.

## 2026-09-12 - Eight protected batteries and distributed bulk capacitance

- **Decision:** Use eight protected 90 mAh batteries, one per pod, with a 3 x 12 x 32 mm YDL301230-class body. Keep factory PCMs intact; remove U27/Q6/Q7/R54-R56/C44 and connect the fused protected outputs directly to VBAT/U11 BAT. Add 22 uF 10 V X5R 0805 per pod; increase TPS22918 C42 to 4.7 nF.
- **Why:** User chooses off-the-shelf battery protection and additional local energy storage. Slower startup accommodates the added capacitance. Retain branch fuses and six-wire interconnect.
- **Supersedes:** Central S-821AAAC selection/implementation and open battery count. Study D supersedes study C allocations with 20 x 38 x 10.5 regular and 24 x 64 x 10.5 main shells, batteries bonded inside every lid.
- **Affects:** Schematics, checks, power/standby documentation and packaging study. Exact fuse/capacitor parts, PCM behavior, current sharing, firmware and physical fit remain unqualified.

## 2026-09-12 - First native placement and fit coupons

- **Decision:** Populate the PCB with all 269 components on eight unrouted islands, 0.8 mm board thickness. Use 17 x 35 mm satellite boards and a 21 x 61 mm main envelope recessed 5.1 mm under the antenna. Offset each 7 x 15 mm actuator cutout 1 mm left for the flex tail. Keep existing shell and eight-cell allocations.
- **Parts:** DRV2625YFFR and VLV041235L; USB4105-GF-A, EVQPUJ02K, LTST-C19HE1WT, TL3305AF160QG service switches. Assign TI power-package footprints and a DFE201612E-R47M=P2 body/land proposal. Move C3's 10 uF allocation to 0805.
- **Why:** Establish actual board space and hand-wired pod interfaces before routing. New footprints use source drawings; fuse selection and inductor land sign-off remain open.
- **Affects:** Native schematics/PCB, local footprints, net checks and mechanical fit coupons. Prototype copper-edge allowance is 0.25 mm and DRV local copper clearance 0.15 mm; BGA escape/stackup is not yet solved. Coupons use temporary lid retention, with no final PCB supports, TPU links or clasp. No routing/fabrication or physical qualification is claimed.

## 2026-09-12 - Four-layer JLCPCB boards and supply-reset drivers

- **Decision:** Use four copper layers at 0.8 mm nominal thickness, with ordinary 0.20 mm drill / 0.45 mm diameter through vias. JLCPCB is the preferred fabricator. Reserve In1.Cu for ground; satellite In2.Cu carries POD_3V3. Exact production dielectric stack remains to confirm.
- **Reset:** Tie each DRV2625 B2 NRST directly to C2 VDD, remove the eight reset pull-downs, and mark M2003 PB13 no-connect. The ESP32 controls hard recovery through the existing switched pod supply. Stop playback before loader entry; MCU-only reset no longer resets the driver. Power cycling resets all eight pods together.
- **Parts:** Select Littelfuse 0467.250NR 250 mA 0603 branch fuses (DigiKey F1389CT-ND), and replace the proposed Murata inductor lands with the DFE201612E manufacturer land pattern. Factory battery PCMs remain fitted.
- **Why:** User explicitly chooses four layers and existing power control for recovery. Direct B2-C2 routing avoids centre-ball via-in-pad fabrication.
- **Affects:** Revision 0.7 schematics/PCB, reset firmware contract, local footprints and connectivity checks. The count becomes 261 components. Fuse coordination, discharge/restart timing and physical manufacture remain unqualified.

## 2026-09-12 - Satellite routing checkpoint

- **Decision:** Merge locally closed routing for pods 1-7 into the eight-island PCB. Keep In1.Cu free of signal tracks; use In2.Cu primarily for POD_3V3 with reset and end-bridge signal exceptions. A short B.Cu link reconnects pod 7's isolated pull-up supply section.
- **Evidence:** All seven isolated boards have zero native DRC violations and zero opens. After merging, no satellite-local opens reappear; schematic parity is zero, all 947 electrical pads match the netlist, and all 416 vias are ordinary 0.45/0.20 mm through vias without drilled holes overlapping SMD lands.
- **Remaining:** Main pod 0 has 277 local opens and six warnings; 42 additional combined-board ratsnest items cross externally wired islands. Main power/USB/RF routing, final stack selection and fabrication preparation remain pending.
- **Affects:** Native PCB, docs/pcb-routing.md and hardware/verification/routing/. Historical placement evidence remains under verification/placement; the old placement generator is guarded against overwriting revision 0.7.

## 2026-09-13 - User placement repeated across seven satellites

- **Decision:** Use the user's pod-6 functional placement and aligned wire pads for pods 1–7. Complete signals on F.Cu/B.Cu only; retain In1 ground and In2 POD_3V3 with a VBAT perimeter strip. This supersedes the revision-0.7 inner signal exceptions. Place pod 7's R53 bridge in the lower bay.
- **Rules:** Retain the user's current project constraints, including 0.1016 mm minimum track width and 0.50/0.20 mm minimum via diameter/drill. Use 0.60/0.30 mm ordinary through vias and 0.50/0.20 mm constrained escapes. New BGA tracks are 0.11 mm. Eight vias are in hand-soldered wire pads; none overlap component solder lands.
- **Evidence:** All seven isolated satellites pass DRC with zero violations/opens. Combined parity is zero, all 947 pads match the schematic, and no satellite-local opens remain. There are 325 satellite vias. The main-board footprints/tracks and project rules are preserved from the user's starting files.
- **Remaining:** Main routing has 277 local opens, six warnings and a 0.1000 mm driver tie below the current minimum width; 42 other connectivity items cross externally wired islands. Final production stack, fabrication and physical qualification remain pending.
- **Affects:** Native PCB, README, docs/pcb-routing.md and verification/routing-v08/. The user's saved starting files are backed up under hardware/backups/user-placement-20260913/.

## 2026-09-13 - Six-mil satellite template

- **Decision:** Clone the user's cleaned second pod-6 layout to all seven satellites. Require at least 6 mil track width, no drilled vias in solder pads, and horizontal/vertical/45-degree traces. Preserve the pod-7-only return bridge and the inner ground/power planes.
- **Why:** The user's placement and routing remove the need for the narrower escapes, wire-pad vias and arbitrary angles in the earlier automated pass.
- **Supersedes:** Revision-0.8 satellite routing geometry and its via-in-wire-pad allowance. Circuit architecture is unchanged.
- **Affects:** Native PCB, docs/pcb-routing.md and verification/routing-v09/. Main-board placement remains unchanged; docs/main-board-placement.md is a proposed functional allocation rather than an accepted placement.

## 2026-09-13 - Separate PCBA masters and wired schematics

- **Decision:** Maintain `hardware/main/` and `hardware/satellite/` as independent KiCad projects, each with one PCB. One wrist uses one main and seven copies of the same satellite. Any later JLCPCB panel is a derived output under `hardware/panel/`.
- **Selector:** Replace the end-only R53 variant with universal JP1: pad 2 feeds upstream return, pad 1 is downstream return, and pad 3 is local TX after its series resistor. Factory 1–2 is NORMAL; cut 1–2 and solder 2–3 on the last satellite. Never bridge all three. The six-wire chain and mechanical clasp remain unchanged.
- **Drawing convention:** Preserve the user's redrawn top sheet. Redraw child sheets with support parts wired in functional groups, using labels for power and circuit/sheet boundaries. Use canonical `+3V3` and `+3V3_POD` names.
- **Preservation:** No missing components, changed values or changed footprint assignments were found in the user's redraw. Repair its split power aliases and remove the obsolete dangling QOD wire/label. Archive the original combined project intact; retain its starting hashes. Main references and placement are preserved; satellite references are renumbered locally from the user's pod-6 template.
- **Evidence:** Both projects have zero ERC violations and zero schematic/PCB parity issues. The satellite has 223 segments, 45 through vias, zero DRC violations/opens, 6 mil minimum tracks, no via-in-pad and no inner-layer signals. Main retains 277 opens and six silk/library warnings; its existing narrow driver tie is widened to 6 mil. Native files are the editable sources; migration scripts are provenance.
- **Remaining:** Main placement/routing, final production stack and derived panel are pending. This does not establish physical fit, firmware operation or manufacturing qualification.

## 2026-09-13 - Five-wire harness and power-cycle recovery

- **Decision:** Remove the shared MCU reset conductor and ESP32 Q5/R6/R7/R44/C40 reset circuit. GPIO18 becomes spare. Each MCU retains local ICE reset with its internal pull-up; whole-chain recovery uses U26 power cycling. Retain harness numbering 1/2/3/5/6, marking pad 4 NC to preserve existing placement/routing.
- **Why:** The user wants every hand-soldered wire to earn its keep; power control already provides recovery. This removes fourteen solder joints per wrist. Remove redundant main J100 as discussed.
- **Supersedes:** Shared reset and six-wire harness provisions in earlier entries. Host sequencing must now accommodate individual POR timing and full rail discharge.
- **Affects:** Both PCBA schematics/PCBs, ring-pods.md, pinout and preservation checks. Placement is user-owned; the exploratory main placement candidate was not applied. Local internal-pull-up operation and loader timing remain bench checks.

## 2026-09-13 - Compact five-pad harness interfaces

- **Decision:** Use WirePads_5_P2mm for main J101 and satellite J1/J2, with pins 1 switched 3V3, 2 GND, 3 forward UART, 4 VBAT, 5 serial return. Keep 2 mm pitch, 1.4 x 1.6 mm lands and no paste.
- **Why:** User requests removal of the unused physical pad as well as the reset wire. Each bank becomes 2 mm shorter; the first three lands stay fixed. Adjust only VBAT/return connections and legends; other placement stays unchanged.
- **Supersedes:** Five-wire harness on six-position banks with NC pad 4. Old harness VBAT/return pins 5/6 are now 4/5; local ICE pad numbering is unchanged.
- **Affects:** Both schematics/PCBs, shared footprint, harness documentation and checks. Satellite remains fully routed with no new vias.

## 2026-09-13 - Passive USB-C sink and direct charger input

- **Decision:** Replace U13 with independent R60/R61 5.1k CC pull-downs. Remove U16/U17, Q2/Q3, R26-R33 and C31/C33; connect USB_VBUS directly to BQ25186 IN. Retain data/CC ESD, VBUS sensing, bypass capacitors and native USB data.
- **Why:** User accepts ordinary 5 V source compatibility tradeoffs for this prototype; external current-mode selection and CC detection do not justify their size/complexity. Charger input limiting replaces the external current selector, including its former low-current startup clamp.
- **Supersedes:** TUSB320 attachment/current-advertisement handling and the TPS2553/TS5A3159 current-limit architecture. GPIO0/14/22/23 are spare. Firmware uses charger registers and VBUS sensing; startup defaults remain part of the chosen source policy.
- **Affects:** Main schematics/PCB, USB and standby docs, circuit checks. Retained component placement and satellite files are unchanged.

## 2026-09-13 - Symmetric pod cell and thermistor interfaces

- **Decision:** Retain main J200/F100 and J103 as equivalents of satellite J4/F1 and J5. Remove main J3; fit R62 (10k) from charger TS/MR to ground, retaining SW3 in parallel. All eight cell thermistors feed their local M2003 ADCs.
- **Why:** One cell and temperature interface per pod preserves symmetry and removes duplicate main-pod connections. Firmware must gate charging on valid, fresh, in-range readings for every required cell, and disable charging before pod power-off or loader entry. The charger no longer has independent cell-temperature sensing.
- **Also:** Remove R48/R50/R52 LED pull-ups. GPIO4/5 SDIO straps are unused; GPIO15 JTAG selection is ignored with default JTAG_SEL_ENABLE, which we will not burn.
- **Supersedes:** Main J3 charger-thermistor provision and RGB default-off pull-ups.
- **Affects:** Main schematic/PCB, power and standby docs, circuit checks. Retained placement and satellite source files are preserved.

## 2026-09-13 - USB-only ESP service and charger input-status sensing

- **Decision:** Remove main J1 UART service bank without replacement test points. Remove Q4/R34/R35/R36 VBUS detector; leave GPIO1 and UART0 RX/TX NC. Native USB Serial/JTAG handles programming/debug, with SW1/SW2 retained for reset/ROM download.
- **Why:** The small main board benefits from fewer footprints and connections; existing USB and charger I2C cover these functions. Firmware reads charger VIN_PGOOD_STAT for usable input power, rather than a discrete VBUS GPIO.
- **Supersedes:** Main UART service connector and VBUS_nPRESENT firmware interface.
- **Affects:** Main schematic/PCB, USB and standby notes, connectivity checks. Retained placements, satellite design, and charge-enable gating are preserved.

## 2026-09-13 - First controller and pod firmware contract

- **Decision:** Start firmware as portable protocol code, an ESP32-C6 ESP-IDF controller, and an M2003 pod application. Borrow the music robot's 250 kbaud framing, store-forward enumeration, boot mailbox, flash geometry, packager, and unchanged LDROM sources by explicit path. Reserve new bracelet opcodes `0x11`/`0x12` for RTP/all-stop; do not reuse motor duty semantics.
- **Safety:** Require exactly eight pods and valid MSPv2-wrapped CRSF attitude from one configured ESP-NOW source. Send at 50 Hz, stop locally after 100 ms without haptic commands, and reject controller attitude older than 250 ms. Keep charging disabled. Use a provisional, documented absolute-attitude matrix.
- **Driver:** Auto-calibrate each DRV2625 for the proposed 240 Hz LRA, limit the first-pass clamp to its stated 1.85 Vrms operating ceiling, and require successful status before RTP.
- **Affects:** `firmware/`, README status, ring behavior, telemetry provisioning, and bench qualification. Builds do not establish flashing, timing, thermal, perceptual, or loader-ring evidence.

## 2026-09-13 - Latched manual USB bring-up console

- **Decision:** Add a native USB `hb` console that accepts partial-ring enumeration and addressed status checks, but latches manual mode before bus or actuator diagnostics. Limit single-pod RTP tests to amplitude 64 and 10-250 ms, refresh every 20 ms, then issue addressed stop and broadcast all-stop. Only explicit `hb flight` releases manual mode, and it still requires exactly eight pods and fresh telemetry for output.
- **Why:** First hardware should be testable one pod at a time without weakening normal-flight interlocks or requiring a complete bracelet to diagnose a single driver.
- **Supersedes:** The first firmware contract's exact-eight restriction for diagnostic enumeration only; its flight-output requirement remains unchanged.
- **Affects:** ESP32-C6 console selection, ring receive/locking, controller modes, `firmware/protocol.md`, and `firmware/BRINGUP.md`.

## 2026-09-13 - Main Tag-Connect and compact placement checkpoint

- **Decision:** Apply the requested placement pass to the main master, preserving U1/J2/J101/J200/J103/M1 positions. Use the user's TC2030 J1 in place of J102 and remove C29/C30 as requested. All 70 footprints remain on F.Cu; functional groups fit around the actuator opening. D1 is beside the ESP32 and SW3 is on the left edge.
- **Schematic:** Preserve the user's latest redraw, ground and C1 junction repairs. Retain the new VBUS/VSYS power names; restore three external-supply PWR_FLAG directives. The Tag-Connect reset output is open drain; keep the selected M2003 internal pull-up and document its one ERC input-driver item rather than adding components.
- **Evidence:** Both PCBA preservation checks pass. Main: zero parity errors, three silk/library warnings, 196 opens. Satellite: zero ERC/DRC/opens, unchanged source. Accepted positions and before-apply backups are documented in docs/main-board-placement.md. Routing and enclosure access remain to be completed.

## 2026-09-13 - One fitted switch and underside ESP recovery pads

- **Decision:** Remove SW1/SW2 and use bare J3 EN/GND/BOOT pads on B.Cu, accessible through an underside service opening clear of the lid-mounted cell. Keep R3/C1 reset bias, R5 boot pull-up and SW3 as the sole side-actuated user button.
- **Why:** Native USB handles normal flashing/JTAG; manual GPIO9-low/reset access remains for firmware recovery without two tall switches. Hold BOOT low, pulse EN low, release EN then BOOT.
- **Placement:** Reorder USB, I2C and boot passives beneath their ESP pins, move R42 to TX, and move D1 into the freed lower-left space. Preserve other functional groups and edge anchors. Enclosure service opening and LED window still need corresponding mechanical updates.

## 2026-09-13 - Routing clearances, drills and direct plane connections

- **Decision:** Use 6 mil copper/zone clearance and minimum track width, via drills at least 0.25 mm, and 0.20 mm copper-edge clearance on both PCBA masters. Use direct plane connections, with solid footprint/pad overrides and solid existing zones.
- **Implementation:** Remove undersized routing presets; increase seven satellite via drills from 0.20 to 0.25 mm. Preserve positions and copper diameters; refill the satellite planes. Default track width remains 0.20 mm, with 6 mil available for tighter routes.
- **Evidence:** Satellite remains DRC-clean and fully connected; main has no new errors. These constraints supersede the earlier 0.20 mm drill and 0.15 mm driver-clearance settings.

## 2026-09-13 - Claspless co-printed Myo-style band

- **Decision:** Join all eight rigid pod shells with paired TPU U-flexures and co-print the aligned rigid and soft volumes as one permanently closed band. Use the same flexure at the unwired end-to-main gap; do not add a clasp, separate strap, pin, screw or modeled TPU interlock. Let the slicer resolve the shared material interface.
- **Why:** The supplied Myo reference and user direction establish the intended mechanism directly: rigid modules connected by integral soft U-loops, with no opening hardware.
- **Supersedes:** The mechanical clasp portion of “Six-wire chain with passive serial return.” The current five-wire electrical chain remains unchanged: seven wired gaps and one unwired TPU seam.
- **Affects:** `mechanical/myo-band-v0.7/`, `tools/build_myo_band.py`, bracelet overview and ring-pod mechanical documentation. Fit, preload, TPU fatigue, slicing, printing and body testing remain open.

## 2026-09-14 - Flat co-printed housing assembled into a ring

- **Decision:** Print the eight shells as an open flat strip with paired bed-level TPU hinges, then close the unwired joint using flexible tabs over main-lid retaining buttons. Target the user's H2D and proposed PET-GF15/TPU combination. Leave material bonding to the slicer. Retain the 195 mm wrist reference and existing pod body footprints.
- **Why:** The user requests flat printing followed by ring assembly. The TPU grade remains open; 1 mm hinges and tab fit are provisional parameters. The tab/button closure is the first implementation choice, not a user-qualified permanent joint.
- **Also:** Add native-outline-referenced PCB support ledges, external lid screw bosses and 1.2 mm lids (10.7 mm closed body depth). Refresh main service openings from current native footprint positions. Preserve board and battery sources; check bare-board/battery allocations, USB opening and lid clearance in CAD.
- **Supersedes:** The upright-print, permanently closed mechanical architecture in "Claspless co-printed Myo-style band" for the new v0.8 prototype. Keep v0.7 files intact. The five-wire, seven-gap electrical chain is unchanged.
- **Affects:** `mechanical/flat-band-v0.8/`, `tools/build_flat_band.py`, `tools/render_flat_band.py`, project overview and ring-pod mechanical description. CAD/mesh checks do not establish slicing, printed fit, populated-board retention, wire strain relief, closure fatigue or operating qualification.

## 2026-09-14 - Planar Myo end rails and a main-shell assembly seam

- **Decision:** Follow the user's red/blue sketch: two continuous TPU rails along the axial pod ends, turning inward in the flat XY plane as paired U-folds at all eight inter-pod gaps. The upper and lower folds can change shape independently; the taller main pod has longer end transitions. Keep PET-GF15/TPU, H2D flat printing and slicer-managed material bonding.
- **Assembly:** Split the main shell at local X=7 mm so its portions print at the two strip ends. Two floor keys locate them; one 2 mm main lid and four screws close the housing. This preserves eight compliant joints and removes inter-pod closure straps/buttons. Satellite bodies, lids and the electrical chain are retained.
- **Why:** The user wants stretch and angular compliance to follow noncylindrical wrists/forearms. Their sketch explicitly establishes planar end folds; neither straight bed-level links nor radial upright U-loops satisfy that geometry.
- **Supersedes:** The straight hinges and tab closure in "Flat co-printed housing assembled into a ring" for the new v0.9 prototype. Earlier revisions remain intact.
- **Evidence:** Sixteen spring-to-neighbor contact checks, valid STEP reimports, bare-board/battery allocations, sampled main seam/lid assembly motion, USB aperture and exported mesh checks pass. The 195 mm circular reference and illustrated oval/taper pose are layout aids, not force/strain or physical fit qualification.
- **Affects:** `mechanical/myo-flat-v0.9/`, `tools/build_myo_flat_v09.py`, `tools/render_myo_flat_v09.py`, README and ring-pod description. TPU selection, usable travel, stiffness, seam strength, populated-board retention and harness motion remain physical design work.

## 2026-09-14 - Full-height ribbons and stepped main clamshell

- **Decision:** Implement the user's tape-like TPU ribbons at the full 9.5 mm shell-wall height. Retain paired inward plan-view folds at every gap. Replace projecting screw ears with rounded full-width shoulders and recessed countersunk heads.
- **Closure:** Place the whole wrist-facing main floor at one strip end and the whole outer face at the other. Complementary full-height wall portions form the stepped seam shown in the user's latest drawing. Ribbon ends stop at their wall edges and butt together when the clamshell closes. Neither free ribbons nor closure joints taper or change Z datum. The local X=18 mm wall handoff avoids the USB opening; a service relief in the embedded rail preserves USB access.
- **Why:** The user explicitly requires constant ribbon height and joining ribbon ends through housing assembly. This supersedes v0.9's left/right division through the main floor and its 1.2 mm-tall TPU geometry. The stepped seam follows the latest drawing rather than a uniform horizontal half-height wall split.
- **Printing:** The 239.2 x 72 x 11.5 mm strip includes the main roof; seven satellite lids remain separate. Local support is required beneath the terminal roof. Four recessed main screws retain the halves using lower-floor posts. Material bonding remains slicer-managed.
- **Evidence:** Valid CAD/STEP, electronics/USB clearance, full-height ribbon-joint gauges and sampled clamshell closing checks pass. Exported mesh and package evidence are in `mechanical/myo-flat-v0.10/`. These checks do not establish printing, fatigue, comfort, seam strength or harness qualification.
- **Affects:** `tools/build_myo_flat_v010.py`, `tools/render_myo_flat_v010.py`, v0.10 delivery files and project mechanical descriptions. Previous releases and native hardware sources remain unchanged.

## 2026-09-14 - Supported main ribbons and subtractive main case

- **Decision:** Bond the long main TPU runs to the outside walls down to the satellite end positions. Use identical free U-fold geometry at all eight gaps. Preserve satellite geometry.
- **Main case:** Cut the cavity, ports and mating seats from one rounded rectangular envelope. Retain whole wrist/outer faces, stepped closure and constant-height ribbon butt joints. Replace isolated posts with integrated end walls, using recessed M2 x 8 mm main screws. Main end inlays narrow to 1.2 mm to retain material around the pilots.
- **Why:** The user's slicer screenshot identified extra free main-leg length and requested a coherent rectangular housing with two hollow mating halves.
- **Supersedes:** Main transition and standoff details in “Full-height ribbons and stepped main clamshell.”
- **Affects:** v0.11 CAD, coupons and mechanical descriptions. The v0.10 screenshot is slice evidence; v0.11 physical fit and stiffness remain unverified.

## 2026-09-14 - Universal haptic pods with a stacked controller

- **Decision:** Build eight identical universal pod PCBAs and one controller daughterboard. Pod 0 sits beneath the controller without a battery or external NTC; pods 1-7 each carry both. Retain all universal-board components, local ICE and the existing JP1 selector.
- **Interface:** Controller J101 connects pin-for-pin to pod 0 J1: switched 3V3, GND, ESP TX, protected VBAT and UART return. Pods 0-6 use NORMAL; pod 7 uses END. Eight-node loader topology and power-cycle reset remain unchanged.
- **Why:** Additional main-pod height is preferable to the larger integrated board footprint. Seven 160 mAh 301730 cells are a candidate for 1,120 mAh; exact part, protected dimensions and ratings remain unverified.
- **Supersedes:** The integrated main haptic/battery circuit and eight-cell packaging baseline. Previous routing and mechanical files remain historical references.
- **Affects:** Main schematic/PCB inventory, assembly instructions, panel quantities and pending seven-sensor firmware policy. Daughterboard mechanics and placement remain open.

## 2026-09-14 - Matching board outlines and diagonal locating holes

- **Decision:** Match the controller to the universal pod's 17 × 35 mm, R1 outer contour, with no actuator cutout on the controller. Add matching 2 mm NPTH H1/H2 holes at local (15, 1.8) and (2.5, 32.5) mm on both PCBAs.
- **Why:** The user prefers the smaller stacked footprint and explicitly requires mounting positions on opposite sides. Printed locating pins with lid/ledge retention are provisional; VHB remains an option.
- **Placement:** Preserve all existing electrical parts and routes. The user will reshuffle them around the holes and smaller controller perimeter; clearance conflicts remain visible rather than excluded.
- **Affects:** Both native schematics/PCBs, library tables and geometry checks. The pre-edit sources are in `hardware/backups/pre-matched-outlines-20260914/`. Enclosure and stack-height work remain open.

## 2026-09-15 - PCB faces clamp a TPU spacer using four corner fasteners

- **Decision:** Expand both active boards to the regular pod's 20 × 46 mm, R2.5 outside contour. Use the universal board as the skin-facing plate and the controller as pod 0's outer plate. Retain VLV041235L with its supplied adhesive; remove the lower-board actuator cutout.
- **Mounting:** Four shared corners at local (3.5, 3.5), (16.5, 3.5), (3.5, 42.5), (16.5, 42.5) mm. Lower: M1.6 closed-base SMT standoff family, Ø3.3 body/Ø4 land. Upper: Ø1.8 screw clearance. Final standoff height and screw length remain open.
- **TPU:** Draw a 1.2 mm contact band and a 1.5 mm placement inset, with Ø4.6 corner relief. Preserve user electrical placement/routing for rearrangement.
- **Supersedes:** Two locating holes, 17 × 35 mm internal-board outlines and the separate rigid skin-contact shell. Blank upper-plate fabrication files, spacer CAD and thinner-board trials remain future work; active stackups stay 0.8 mm/four layers.

## 2026-09-15 - Move corner mounts into the TPU contact band

- **Decision:** Move all four mounting centres outward by 0.75 mm on both axes: local (2.75, 2.75), (17.25, 2.75), (2.75, 43.25), (17.25, 43.25) mm. Matching upper screw holes and lower standoff lands retain the same shared pattern.
- **TPU:** Move the matching diameter 4.6 mm relief circles with the mounts. Intentional overlap with the contact band allows the standoffs to pass through the TPU frame; spacer CAD must account for the corner reliefs.
- **Validation:** Electrical placements, pads, routes and project settings preserved. Satellite DRC/open count remains zero; controller has 20 DRC findings and 146 opens during placement. Sources before this move are in `hardware/backups/pre-outward-mounts-20260915/`.

## 2026-09-17 - Outward top-push user switch

- **Decision:** Replace SW3's EVQPUJ02K side switch with Panasonic EVPAWBD4A, 1.6 N and 0.6 mm high, on outward B.Cu at its saved centre. Preserve TS/MR/GND connectivity and other placement/routing.
- **Why:** The controller PCB is also the outer shell, so the button must press through its outer face.
- **Supersedes:** Side-actuated SW3 in the one-fitted-switch decision of 2026-09-13.
- **Affects:** Main power schematic, PCB and project footprint. Attach a clearly labeled datasheet-derived nominal STEP body because a downloadable exact model was not found. Protective cover and physical feel remain pending; see `docs/pcb-sandwich.md`.

## 2026-09-17 - Functional-group placement refinement

- **Decision:** Place R4/R5, R24/R25, C2 and R42/R43 on B.Cu beside their U1 pins. Consolidate U26 control passives and LED resistor R51 on F.Cu, move U14 toward USB data pads, and clear C41 from the connector courtyard.
- **Why:** Prefer short local same-layer terminations within functional groups, while preserving fixed mechanical anchors and the coherent charger/regulator groups.
- **Preservation:** Circuit, connectors, module, switch, recovery pads, mounting pattern and project rules remain unchanged. Keep the U1 antenna courtyard and its mounting warnings; RF/fastener resolution is still open.
- **Affects:** Main PCB placement; details and before/after evidence in `hardware/verification/main-group-refinement/README.md`. Routing remains pending.

## 2026-09-17 - Restore user's main-board placement

- **Decision:** Revert the entire assistant functional-group placement pass to the exact pre-pass PCB backup, retaining the accepted SW3 replacement.
- **Why:** The PCB is the housing: internal components belong on F.Cu; B.Cu is for deliberately exposed parts. The assistant's support-passive layer changes violated this constraint.
- **Supersedes:** Functional-group placement refinement above. Candidate reports remain historical only.

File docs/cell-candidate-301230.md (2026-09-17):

> **Current baseline, 2026-09-14:** seven protected battery assemblies in pods 1-7; no cell in pod 0 beneath the controller daughterboard. Seven 90 mAh cells give 630 mAh. The eight-cell examples below describe the superseded integrated-main packaging.

## Alternative candidate: 301730 / 160 mAh

The user identified 301730 batteries advertised at 160 mAh. Seven would provide 1,120 mAh nominal, 55.6% above the former eight-by-90 mAh arrangement. This is a candidate, not a selected manufacturer part. The nominal size designation suggests a wider cell; an actual drawing must establish the complete protected assembly, tolerances and lead exit before revising the lid allocation. Charge/discharge limits and protection specifications cannot be inferred from capacity or the size code. Keep factory protection as required by the current architecture.

# 301230 cell packaging candidate

2026-09-12: the user proposes one approximately 90 mAh cell in each of eight pods, with YDL301230 as an example, and is open to other bare-cell part numbers. The exact purchase remains open, but protected assemblies of this size are the adopted baseline; the numeric size code does not identify a unique electrical specification.

## Exact YDL example and bare-cell sourcing

[YDL's product](https://ydlbattery.com/products/ydl-301230-90mah-3-7v-lithium-polymer-battery-3x12x32mm-with-ph2-0-connector) is a protected 3 x 12 x 32 mm finished assembly, with leads and a PH2.0 connector outside that body envelope. Its [manufacturer datasheet](https://ydlbattery.com/cdn/shop/files/YDL-301230-90mAh-specification.pdf?v=17344537468879431347), cached at `hardware/datasheets/YDL301230.pdf`, specifies 90 mAh rated capacity, 18 mA standard charge, 45 mA maximum charge, and 45 mA maximum continuous discharge. The bare-cell drawing specifies 12 x 30 mm maximum body dimensions, initially 2.7 mm maximum thickness and 3.0 mm after 300 cycles; tabs need additional accommodation.

Eight cells in parallel therefore provide **720 mAh and 360 mA maximum continuous discharge in aggregate**, assuming equal sharing. At 3.7 V this is 1.332 W battery power, approximately 1.20 W after an illustrative 90% conversion efficiency. This is a plausible candidate, not a rejection on current capability: actual haptic/radio load remains to be established. Standard aggregate charge is 144 mA; maximum aggregate charge is 360 mA under the same sharing assumption. Some datasheet test/PCM values conflict with other sections; they do not establish a higher cell discharge rating.

Sources checked 2026-09-12:

| Source and model | Catalog cell body, T x W x L | Capacity | Purchase route / qualification remaining |
| --- | --- | --- | --- |
| [YDL301230, factory direct](https://ydlbattery.com/pages/custom-3-7v-lipo-battery) | Bare body up to 3 x 12 x 30 mm after cycling | 90 mAh | Preferred first inquiry. YDL explicitly offers bare cells for OEM integration and stock-model samples from five pieces. Confirm whether a small bare-cell order qualifies; custom configurations can have a 500-piece minimum. Request attached leads or solderable tabs, no PCM and no connector. |
| [PowerStream GM301030, without -PCB suffix](https://www.powerstream.com/li-pol.htm) | 3 x 10 x 30 mm nominal | Catalog 62 mAh; linked datasheet rated 60 mAh | Catalog offers sample ordering at $10.80 each. Linked protected-assembly datasheet specifies 1C maximum discharge; confirm supplied bare-cell drawing and rating. Lower capacity than YDL. |
| [PowerStream PGEB-A331030, without -PCB suffix](https://www.powerstream.com/li-pol.htm) | 3.3 x 10 x 30 mm nominal | 70 mAh | Catalog offers sample ordering at $4.25 each. Slightly thicker; exact current specification still needed. |
| [PowerStream GM251534 / GM261534, without -PCB suffix](https://www.powerstream.com/li-pol.htm) | 2.5 / 2.6 x 15 x 34 mm nominal | 100 mAh | Catalog offers samples at $10 each. Longer pod required. Linked protected-assembly datasheet specifies 2C maximum discharge but larger finished dimensions; confirm exact bare-cell drawing before layout. |
| [Akyga LP301230 / Ropla AKY0836](https://elektronik.ropla.eu/es/magazyn/magazyn/?ic=AKY0836) | 3 x 12 x 30 mm | 60 mAh | Explicitly unprotected, electrode tabs, 1C maximum discharge. Product page showed zero stock; not an immediate prototype purchase recommendation. |

PowerStream explicitly makes protection optional and uses the -PCB suffix for protected variants. Its catalog says an Add to Cart entry indicates sample stock; this was checked in the retrieved HTML, not through a completed order. Its dimensional tolerances and termination details still need to be included in any revised lid allocation. No supplier has been contacted and no order placed.

## Fit against study C

- The reserved regular-pod envelope is 16 x 28 x 3 mm (width x length x thickness), excluding 0.2 mm lid adhesive. A nominal 12 x 30 x 3 mm cell is 4 mm narrower and 2 mm longer; it does not fit the existing envelope unchanged.
- The regular shell is 20 x 34 x 10 mm, with a 17 x 31 mm PCB envelope. The proposed cell length is plausible if the lid allocation is revised, but end-wall, tab/lead exit, tolerance and closure clearances have not been resolved. The existing 3 mm thickness allocation leaves no additional thickness allowance for a nominal 3 mm cell.
- Keep the accepted mounting method: bond the cell to the inner lid surface, with no separate cell compartment. Leave the LRA mounted to the inner housing and independently clear of the pouch.
- The 24 x 52 mm main pod currently has no cell allocation. An eighth cell requires a new lid allocation clear of the ESP32 antenna, USB receptacle, button and RGB window. Do not assume a cell can cover the antenna because it is on a different Z plane.

No dimensional drawing or PCB outline has been changed by this assessment.

## Capacity and energy per wrist

Assume 90 mAh per cell at 3.7 V nominal, all parallel:

| Populated cells | Capacity | Nominal energy |
| --- | ---: | ---: |
| Seven regular pods | 630 mAh | 2.331 Wh |
| All eight pods | 720 mAh | 2.664 Wh |

The main-pod cell adds 14.3% capacity over seven cells. For eight cells, using a purely illustrative 85% factor for conversion and usable energy gives 2.264 Wh at the electronics: approximately 4.5 hours at 0.5 W average or 2.3 hours at 1 W. These are energy-only scenarios, not measured runtime predictions; actual radio and haptic duty cycles are unknown. A continuous 2 W electronics load exceeds the YDL eight-cell continuous-current rating, so the previous generic 2 W scenario does not apply to this candidate.

Use the YDL-specific 0.5C aggregate ratings above for this candidate, rather than a hypothetical 1C rating. The retired central prototype protector's 1.93 A nominal discharge trip corresponds to roughly 241 mA per cell with eight equally sharing cells (2.68C), so it is not a continuous-current rating for this pack. Final shunt and branch-fuse choices follow actual ratings, current sharing and pulse/load measurements. Normal charge-current settings likewise remain open.

## Source distinction

The proposed 90 mAh rating and nominal dimensions come from the user. Manufacturer listings demonstrate that the same size code has different implementations: [LithoTop](https://lithotop.com/wearable-devices/animal-tracker-battery-solutions) lists a 90 mAh 3 x 12 x 30 mm model, while [LP Power's 301230 datasheet](https://www.fpbattery.com/wp-content/uploads/2023/10/301230-3.7V-75mAh-Specification.pdf) describes a 75 mAh assembly measuring 32 x 12 x 3 mm including its protection arrangement. Neither is assumed to be the user's exact cell.

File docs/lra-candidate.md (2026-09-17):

# VLV041235L prototype selection and flex contacts

> **2026-09-15: retain VLV041235L and its factory peel-and-stick tape.** The universal board is now an unbroken skin-facing plate; the actuator bonds to its inward face. The older cutout/housing-seat concept below is superseded. Existing electrical flex-contact lands are retained for rearrangement. See [PCB sandwich construction](pcb-sandwich.md).

> Project update (2026-09-13): active sources are `hardware/main/` and `hardware/satellite/`. Main references are unchanged; historical satellite references map to the one universal design in [PCBA projects](pcba-projects.md). Any combined-board placement/count or verification statements below describe the earlier checkpoint; [current routing status](pcb-routing.md) supersedes them.

Revision 0.6 assigns VLV041235L and the draft contact footprint to the eight actuators (currently main M1 and seven satellite M1 instances). Native cutouts are 7 x 15 mm and offset 1 mm left, with the contact lands near the lower-right corner. [Current placement](pcb-placement.md) supersedes the earlier pending-selection and no-PCB statements below; the following records the source drawing and initial concept. Physical tail folding and solder attachment remain untested.

2026-09-12: User proposed Vybronics VLV041235L with matching board solder pads. It remains a candidate; M1–M8 have not been changed from placeholders.

[DigiKey listing](https://www.digikey.com/en/products/detail/vybronics-inc/VLV041235L/12323578): 1670-VLV041235L-ND, 569 listed in stock when checked, USD 3.90 at quantity one and USD 3.458 at quantity ten. These are a dated web snapshot, not reserved inventory.

[Vybronics product page](https://www.vybronics.com/linear-lra-vibration-motors/v-lv041235l) explicitly supports direct PCB attachment through double-sided solder contacts on the flex tail, using hot-bar soldering. Its body is 12 x 4 x 3.5 mm, with Z-axis motion, 240 Hz resonance, 1.8 Vrms rating and 60 mArms maximum rated current. The supplied 3M 4905 adhesive is shown separately in the drawing; allow its thickness in the installed assembly. Secure the body to the pod/PCB mechanically rather than supporting it by the electrical joints.

The [A/2 datasheet](https://www.vybronics.com/wp-content/uploads/datasheet-files/Vybronics-VLV041235L-datasheet.pdf) is cached as `hardware/datasheets/VLV041235L.pdf`. Drawing page 10 shows 0.8 x 1.8 mm contacts with a 1.0 mm gap, giving 1.8 mm center pitch. The solder contacts are on a projecting flex tail, not underneath the metal body.

`HapticBracelet:Vybronics_VLV041235L_FPC_Contact_Draft` provides proposed 1.0 x 2.2 mm PCB lands on that pitch. The extra land area is an engineering allowance for local soldering, not a manufacturer recommended land pattern. F.Fab depicts the nominal contact rectangles. There are no paste apertures: this draft assumes local attachment after ordinary PCB assembly, and does not imply whole-actuator reflow qualification. Pad numbering is project-assigned for the two driver outputs; it is not a manufacturer polarity designation.

The footprint deliberately covers only the two contact lands. It has no body courtyard or fixed actuator location because flex routing and housing mounting remain to be chosen. Check a sample's contact alignment, adhesive stack, solder access and flex strain before assigning the footprint for manufacture. A hot-bar connection is manufacturer-described; a hand-iron attachment using accessible upper contacts is a prototype assembly proposal that still needs a trial.

## Working pod packaging concept

The user proposed a central actuator with a surrounding PCB opening, allowing the LRA and its housing mounting seat to project through the board plane. Use this as the working concept, with the actuator bonded to the wrist-facing housing and its flex contacts landing on the adjacent PCB edge. Size the opening around the actuator, adhesive, seat, assembly tolerances and flex routing rather than the bare metal body alone. This is a packaging proposal; no dimensioned PCB outline or mechanical CAD is implemented yet.

The [dimensioned packaging study B](../mechanical/pod-study/README.md) sketches a 7 x 15 mm opening within provisional regular and main pod envelopes, using the user's 195 mm wrist circumference. Per the user's correction, cells bond directly to the lid's inner face with open clearance below; there is no supporting shelf or separate cell compartment. All dimensions other than wrist circumference remain proposals. Native PCB outlines are still unchanged.

Leave the surrounding volume available for circuitry and optional thin pouch cells. Cell envelopes must include sealed edges, tabs and manufacturer-required clearance; the lid supports each bonded cell, keeping it clear of the actuator and PCB cutout edge. A rigid actuator mounting seat is the initial concept; a compliant contact plate remains an optional experiment.

Use Myo-inspired flexible links between rigid pods. The exact link geometry and material are open. A proposed printed implementation uses replaceable TPU links with mechanical capture in the rigid shells, and slack, strain-relieved wiring through the links. Provide both bending and circumference expansion; wire slack must accommodate the full extension. Adafruit's [firsthand Myo teardown](https://learn.adafruit.com/myo-armband-teardown/inside-myo) documents the rubber connection and elaborate flex PCB, not a print-ready link geometry for this project.

## Protector sourcing result

Revision 0.5 removes the central protector in favor of eight batteries with intact factory PCMs. See [current battery protection](pack-protection-implementation.md); the earlier ABLIC selection remains in the [sourcing history](protection-sourcing.md).

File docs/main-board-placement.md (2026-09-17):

> **2026-09-17: user's placement restored.** The assistant's functional-group refinement was reverted at the user's request. The active PCB exactly matches the pre-refinement backup, including the accepted SW3 replacement. The older report below remains historical.

# Main board placement checkpoint

The 69-footprint placement is applied to `hardware/main/main.kicad_pcb` (2026-09-13). It starts from the user's functional groups, incorporates J1 Tag-Connect and omits the intentionally removed C29/C30. The older `verification/main-placement/` proposal is historical.

Main placement

U1, J2, J101, J200, J103 and M1 retain their exact saved positions and rotations. The outline, antenna overhang and actuator opening are unchanged. Fitted components remain on the front; bare J3 recovery pads are on the underside. J1 sits beside the right side of the opening; its three locating holes clear copper and board edges. D1 now sits below the left side of the ESP32, in the space freed by the two removed switches. SW3 sits on the left; enclosure access must follow these control positions.

The charger and IN/SYS/BAT capacitors form a group below the left side of the opening. The buck-boost stage sits below that, with L1 beside its switching pins and feedback on the opposite side. The MCU occupies the lower middle; the driver sits beside the LRA contacts. USB protection stays near J2 and series resistors near the ESP32 USB pins.

## ESP recovery and local placement revision

SW1/SW2 are removed. J3 is a bare three-pad bank on B.Cu at (45.5, 55.0) mm: pin 1 EN, pin 2 GND, pin 3 BOOT/GPIO9. Pads are 1 mm diameter on 1.5 mm pitch, without paste; no connector is fitted. The roughly 4.5 x 3.9 mm courtyard includes readable underside legends. The preview shows this underside bank with dashed outlines, viewed through the board from above. Reserve an underside service opening here; the enclosure opening itself has not yet been modeled.

SW3 retains its left-facing side actuator. R3/C1 reset bias and R5 boot pull-up are retained. The USB resistors are now ordered D-/D+ below their matching pins, with I2C pull-ups to the left and boot pull-ups to the right. R42 is beside the ESP TX pin, instead of across the module. C1 and supply bulk C3 are repositioned along the left edge. D1 and its resistors occupy the former switch area. All footprints outside these 15 ESP-support parts remain at their prior locations.

Pad-centre distances: USB series resistors 1.74/1.70 mm; I2C pull-ups 2.02/1.85 mm; boot pull-ups 1.69/1.76 mm; UART series resistor 1.69 mm; reset C1 1.60 mm. These are placement distances, not routed lengths.

## Placement evidence

The repeatable search uses native pad positions, courtyard bounds, fixed anchors, orthogonal rotations and weighted critical connections. It is a constrained placement pass, not proof of a global optimum. The preview shows pads and courtyard bounds.

| Connection | Straight-line pad-centre distance |
| --- | ---: |
| TPS63802 to L1, each switching pin | 2.02 mm |
| TPS63802 input to C37 | 1.75 mm |
| TPS63802 output to C38 / C39 | 2.14 / 4.32 mm |
| BQ25186 IN / SYS / BAT capacitors | 1.51 / 1.90 / 2.70 mm |
| M2003 supply to C100 | 1.74 mm |
| DRV2625 supply to C5 / REG to C6 | 1.86 / 1.30 mm |
| ESP32 supply to C2 | 1.60 mm |

These are geometric distances, not routed lengths or loop inductance. Routing must keep local capacitor grounds short, join regulator control ground appropriately, separate feedback from switching nodes and maintain a continuous ground reference. Secondary bulk capacitors are less tightly constrained than primary bypass capacitors.

Native checks report zero schematic/PCB mismatches and no copper, courtyard, hole or edge-clearance errors. Three warnings remain: two ESP32 silkscreen/edge warnings and the existing ESP32 footprint/library difference. Main has 191 open connections, one existing driver NRST/VDD segment and no vias. One ERC item remains for the Tag-Connect open-drain reset output and M2003 input with its internal pull-up; it is recorded explicitly. Satellite validation remains clean and its source is unchanged.

## Files and next step

- Accepted positions: `hardware/main/placement-reference.json`.
- Preview and measurements: `hardware/verification/main-recovery-pads/`.
- Latest before-apply backup: `hardware/backups/pre-esp-recovery-pads-20260913/`.
- Initial user board: `hardware/backups/user-main-groups-20260913/`.
- Current native reports: `hardware/verification/project-split/`.

Routing remains pending. Start with regulator power loops and local decoupling, then USB; use F.Cu/B.Cu for signals, In1 GND and In2 power. Retain the 6 mil minimum and avoid via-in-pad. Local placement adjustments may be needed during routing.

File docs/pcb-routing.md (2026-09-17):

> **2026-09-15: historical layout report.** Current PCB faces are 20 × 46 mm with four M1.6 corner mounts and TPU contact-band guides. User electrical placement and satellite routes are preserved; the actuator cutout is removed. See [current construction and checks](pcb-sandwich.md).

# Routing status: two PCBA masters

Current editable sources are `hardware/main/main.kicad_pcb` and `hardware/satellite/satellite.kicad_pcb`. Each has one board outline and one actuator opening. One wrist uses one main and seven identical satellites. See [project structure](pcba-projects.md).

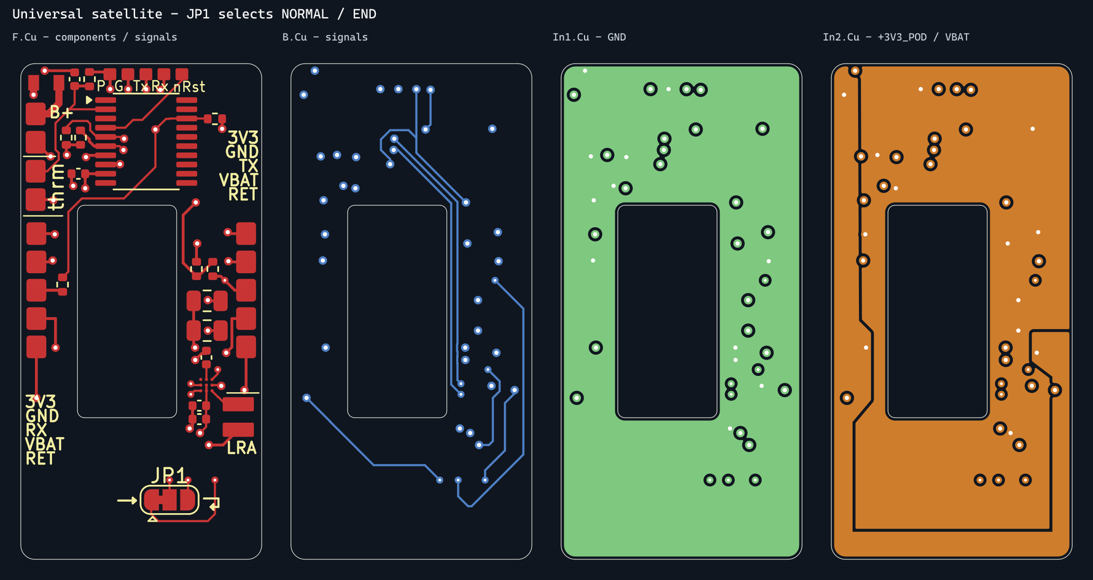
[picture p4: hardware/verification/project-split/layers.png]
Universal satellite layers


All four images are viewed from the top, including B.Cu. [Main placement](../hardware/verification/main-recovery-pads/placement.png) is separate.

## Satellite

The user's cleaned pod-6 placement and routing are retained, with local reference renumbering and JP1 in the lower bay. Both harness banks are shortened to five pads at 2 mm pitch. VBAT and return are now pins 4 and 5; their short local routes are adjusted without moving other components or adding vias. Harness reset branches and three reset vias are removed; the direct local MCU-to-ICE reset trace remains. Two existing silk guide lines were trimmed 0.2 mm from the edge, and the obsolete harness reset legends are removed. The former direct return path is split into RETURN_UP and RETURN_DOWN. JP1 selects downstream return or local TX; its new connections stay on outer copper.

| Layer | Use |
| --- | --- |
| F.Cu | Components and local signals |
| In1.Cu | GND plane |
| In2.Cu | +3V3_POD interior and VBAT perimeter strip |
| B.Cu | Signals and serial return routing |

The board remains 17 x 35 mm, four-layer, 0.8 mm nominal. It has 201 trace segments and 42 ordinary through vias. Its project now enforces a 0.1524 mm (6 mil) track minimum. Copper clearance is 0.1524 mm (6 mil), minimum track width is 0.1524 mm, default track width remains 0.20 mm, minimum via diameter/drill is 0.50/0.25 mm, and copper-edge clearance is 0.20 mm. DRV local clearance is also 0.1524 mm. No microvias are used.

Fresh native DRC after refill reports **zero violations, zero opens and zero schematic parity issues**. The independent check confirms every electrical pad net, no via holes in solder pads, no inner signal tracks, aligned IN/OUT pads, and horizontal/vertical/45-degree traces.

JP1 has a factory copper net tie between 1-2. Satellites 1-6 retain it; the last board is converted to 2-3 by cutting the factory bridge and soldering the other side. Only one satellite design is maintained.
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

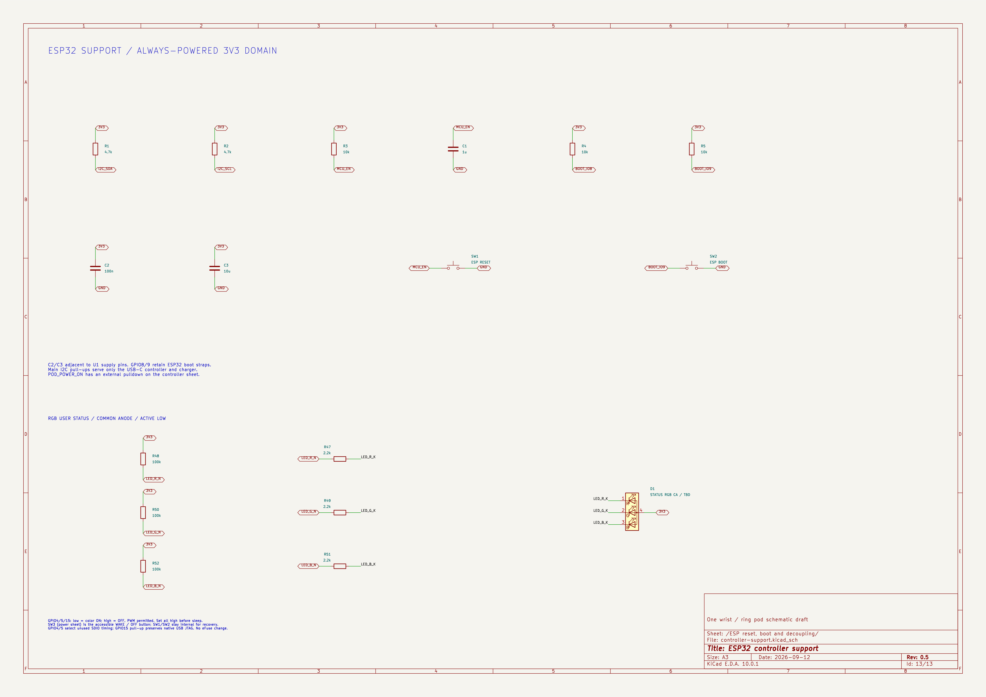
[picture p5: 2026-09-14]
hardware/preview/protected-cells/haptic-bracelet-ESP reset, boot and decoupling.png

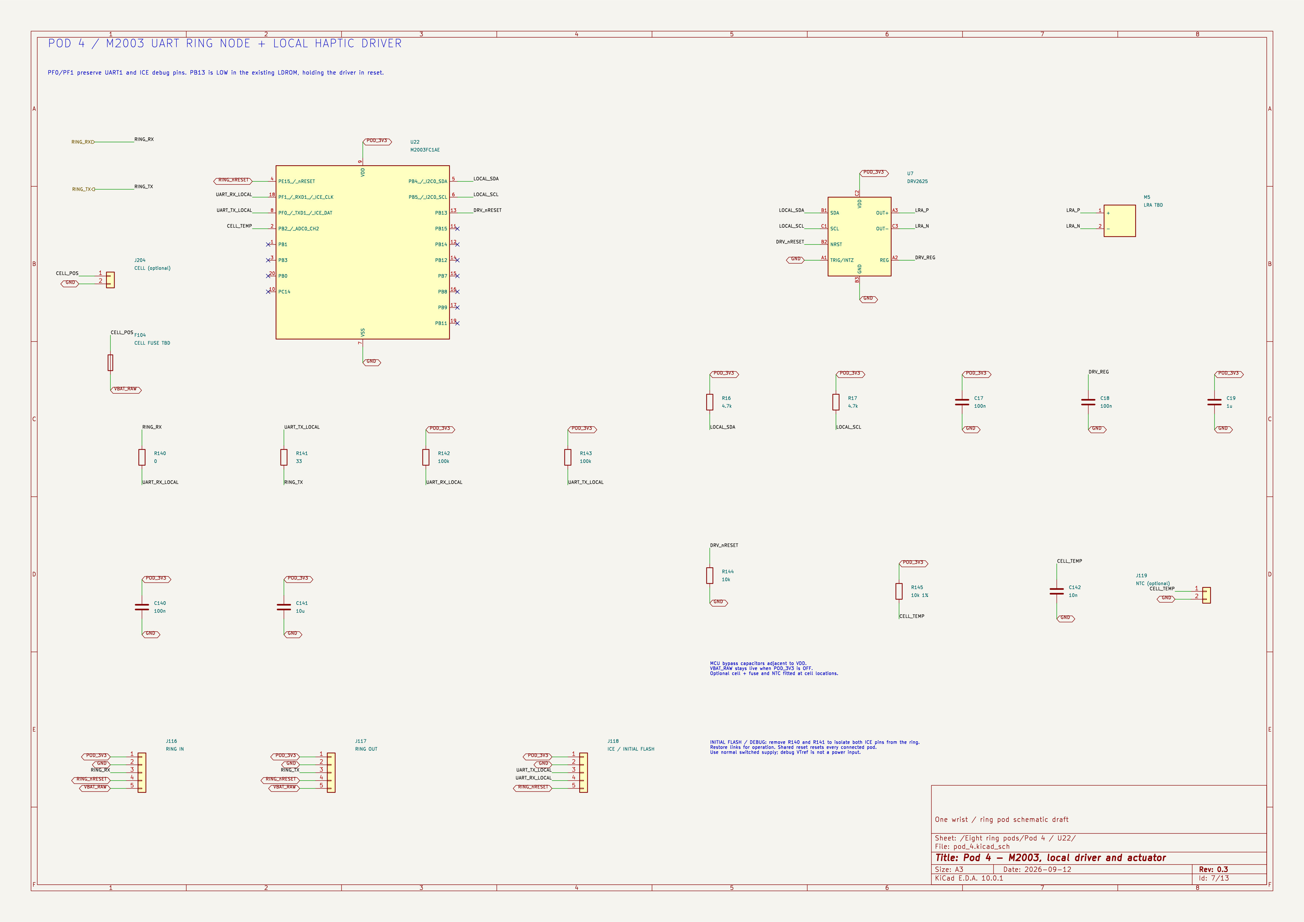
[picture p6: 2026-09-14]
hardware/preview/ring-revision/haptic-bracelet-Eight ring pods-Pod 4 _ U22.png

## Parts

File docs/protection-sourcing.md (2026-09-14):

> **Superseded in revision 0.5:** the user chose protected batteries with intact factory PCMs. No central ABLIC stage is populated. This document retains the earlier sourcing history; see [current implementation](pack-protection-implementation.md).

# 1S protector sourcing — 2026-09-12

Historical revision 0.4: S-821AAAC-H8T7S was selected by user direction and implemented as U27; revision 0.5 removes that circuit. No harness change is required. See [implementation and validation](pack-protection-implementation.md). Historical screening below predates the user's prototype selection.

## Selected part: S-821AAAC-H8T7S

Select ABLIC S-821AAAC-H8T7S, DigiKey cut-tape code `1662-S-821AAAC-H8T7SCT-ND`. The user's export shows 6,000 in stock, minimum quantity 1. [DigiKey product](https://www.digikey.com/en/products/detail/ablic-inc/S-821AAAC-H8T7S/25649783).

- High-side switching and sensing preserve the common ground and six-conductor harness.
- WLP-8V package, 1.08 x 1.52 mm.
- Nominal overcharge detection/release: 4.590 / 4.390 V.
- Nominal overdischarge detection/release: 2.500 / 2.800 V.
- Discharge overcurrent, short-circuit and charge overcurrent sense thresholds: -5.8 mV, -20.5 mV and +20 mV respectively. Current limits require subsequent resistor and FET selection.
- Zero-volt charging inhibited; power-down, power-saving and overheat detection unavailable for this suffix.

The user explicitly chose the lowest overcharge threshold among the stocked high-side variants, accepting reliance on the charger for normal 4.20 V regulation. This supersedes the earlier sourcing rejection below. A 4.590 V fault cutoff does not establish adequate overcharge protection for a conventional 4.20 V cell: a failed charger could hold the cell above its permitted voltage without reaching the protector threshold. Actual cell compatibility remains unverified. Keep the charger set to the selected cell's charging voltage; this IC choice does not authorize increasing it.

Evidence: S821AA Rev.1.3 pp.5-6, cached in `hardware/datasheets/S821AA.pdf`. The native circuit uses two CSD17318Q2 FETs and a 3 mOhm D1MPC0805 shunt, with final current rating subject to cell and load selection.

## Stocked TI candidate requiring a wiring change: BQ298217RUGR

DigiKey's public US product page reports 3,912 available, USD 0.76 at quantity 1 and USD 0.543 at quantity 10. Cut-tape order code: `296-BQ298217RUGRCT-ND`. This is a dated public-page observation, not a reservation or authenticated inventory query.

- Manufacturer: Texas Instruments; active; 8-X2QFN, 1.5 × 1.5 mm.
- Fixed overcharge threshold: 4.250 V, nominal 1.25 s delay.
- Fixed undervoltage threshold: 2.600 V, nominal 125 ms delay.
- Charge/discharge overcurrent thresholds: -36 mV / +60 mV; short-circuit threshold: +200 mV.
- Illustrative 30 milliohm shunt gives nominal 1.2 A charge, 2 A discharge, 6.67 A short-circuit detection. These are examples, not selected pack ratings; tolerances, cell limits, wiring and branch-loss cases remain to assess.
- Normal IC supply current: 4 microamps typical below 3.9 V and 5 microamps typical above 4.0 V under TI's specified test conditions. External leakage is additional.
- Zero-volt charging disabled. This suffix has internal overtemperature protection disabled; distributed cell-temperature charging control remains necessary.
- Requires external back-to-back N-channel MOSFETs, a shunt and support passives.

Evidence: TI BQ2980/BQ2982 datasheet SLUSCS3L, March 2025, page 3 variant table; pages 4–8 pins/electrical characteristics; page 18 reference circuit. Cached as `hardware/datasheets/BQ2980.pdf`, with hash in the manifest.

## Wiring consequence

The FETs switch the positive path, but the current shunt is in the negative path. TI's CS pin senses PACK- relative to the cell-side VSS. It is not a drop-in fit for our existing three-terminal J4 interface.

The revision 0.4 netlist connected raw cell-negative terminals directly to system GND. A single central BQ298217 would require a separate `BAT_NEG_RAW` conductor connecting every cell negative, with only the central shunt connecting that conductor to system GND. That changes the interpod harness from six to seven conductors. Retaining any direct cell-negative-to-GND connection would bypass current sensing.

The return-data conductor and purely mechanical clasp can otherwise remain as designed. The recommendation is conditional on accepting this extra conductor. No such change has been made or treated as approved.

## Other candidates screened

- ABLIC S-821AAAI-I8T1U: positive-path switching and current sensing fit our original architecture; nominal 4.275 V overcharge threshold. Exact DigiKey availability could not be verified.
- Stocked S-821AAAA-I8T1U and S-821AAAB-I8T1U: 4.590 V and 4.620 V overcharge thresholds, respectively. Rejected for the assumed conventional 4.20 V cells.
- DigiKey-listed S-821BAAC-H8T7S and S-821BAAD-H8T7S: also 4.590 V / 4.620 V thresholds; rejected for the same reason.
- Nisshinbo NB7120/NB7123: high-side candidates, but the found DigiKey listings showed zero stock and 5,000-piece ordering quantities. Not prototype-stock solutions.
- BQ298000RUGR: stocked but 4.475 V overcharge threshold; do not substitute for BQ298217.

If six conductors are mandatory, alternatives are sourcing an appropriate true high-side-sensing protector elsewhere or putting local protection at each populated cell. Neither topology change is selected here.

## Broader ABLIC review following user correction

The user reports 75 stocked ABLIC 1S parts on DigiKey. The earlier search did not exhaustively inspect that filtered list; it must not be represented as ruling out every stocked ABLIC part. Public catalog access exposes some rows, but direct automated catalog retrieval was blocked by DigiKey's browser challenge. The filtered-list URL has been requested to reconcile the exact list.

Several stocked ABLIC parts have plausible conventional 4.20 V cell thresholds:

| Exact MPN | Overcharge / overdischarge thresholds | Native protection topology | Evidence |
| --- | --- | --- | --- |
| S-8240ADQ-M6T1U | 4.280 / 2.800 V | Low-side FETs, FET resistance sensing | S8240A Rev.3.3, p.4 variant table; DigiKey product 16187176 |
| S-82N1AAA-I6T1U7 | 4.280 / 2.900 V | Low-side FETs, FET resistance sensing | S82N1A Rev.1.2, p.3 variant table, p.24 Figure 14; DigiKey product 14664151 |
| S-82D1AAD-A8T2U7 | 4.280 / 3.000 V | Low-side protection with separate sense resistor | S82D1A variant table; DigiKey product 13183030 |

S-82N1AAA is an attractive low-power alternative: 600 nA typical / 990 nA maximum IC operating current at 25 C, SNT-6A package. Its public DigiKey product page reports 3,669 in stock and USD 1.54 each, while the more recently crawled catalog reports 3,653 and USD 1.85. Treat availability as supported but exact price/quantity as unconfirmed until ordering. Datasheet saved to `hardware/datasheets/S82N1A.pdf`; reference circuit rendered in `hardware/verification/S82N1A-application.png` and visually checked.

These parts cannot be inserted as one central protector while retaining direct connections between every cell negative and system GND: that would bypass their disconnect path. They could be used with a separate raw battery-negative bus, or locally at each populated cell before joining the shared rails. Local protection preserves the six-conductor harness, but changes the previously chosen single-protector architecture. Threshold/current/FET selection and parallel-branch behavior would still need checking against the selected cells.

ABLIC's [current 1-cell product-lineup table](https://www.ablic.com/en/semicon/products/power-management-ic/lithium-ion-battery-protection-ic/intro-1cell/) explicitly distinguishes ordinary FET-resistance/sense-resistor protectors from the S-821A/B high-side families. A 1-cell filter alone does not impose high-side switching and sensing. No topology change or final IC commitment is recorded by this review.

## Sources

### User-supplied S-821 export: all 18 rows reconciled

Read-only source: `C:/Users/mmsyl/Downloads/battery_management.csv`, received 2026-09-12. SHA256: `ab5aa471e1afcff4904a20d6f38fe28612f71e806f0ab0181eb43aefbeda045a`. The source contains 18 distinct MPNs: eleven S-8215A variants explicitly marked 3–5 cells, one S-8211CAA-I6T1U low-side 1-cell protector, and six S-821AA/BA high-side 1-cell protectors. This resolves the supplied 18-row list, not the previously mentioned 75-row 1S list.

| High-side MPN in supplied export | Stock in supplied export | Overcharge threshold |
| --- | ---: | ---: |
| S-821AAAC-H8T7S | 6000 | 4.590 V |
| S-821AAAB-I8T1U | 95 | 4.620 V |
| S-821AAAD-H8T7S | 75 | 4.620 V |
| S-821AAAA-I8T1U | 67 | 4.590 V |
| S-821BAAD-H8T7S | 90 | 4.620 V |
| S-821BAAC-H8T7S | 88 | 4.590 V |

Threshold evidence: cached S821AA Rev.1.3 pp.4–5 and manufacturer S821BA Rev.1.3 p.4. S-8211C low-side topology: manufacturer S8211C Rev.7.7_03 p.28, Figure 14, https://www.ablic.com/en/doc/material/old_product/S8211C_E_NRND.pdf. The suitable-threshold high-side candidate S-821AAAI-I8T1U is absent from this export. None of the supplied six high-side variants is selected as the primary overcharge protector for the assumed conventional 4.20 V cells.

- [DigiKey BQ298217RUGR](https://www.digikey.com/en/products/detail/texas-instruments/BQ298217RUGR/18111336)
- [TI BQ2980/BQ2982 datasheet](https://www.ti.com/lit/ds/symlink/bq2980.pdf)
- [ABLIC S-821AA datasheet](https://www.ablic.com/en/doc/datasheet/battery_protection/S821AA_E.pdf)
- [ABLIC S-821BA datasheet](https://www.ablic.com/en/doc/datasheet/battery_protection/S821BA_E.pdf)
- [DigiKey S-821AAAA-I8T1U](https://www.digikey.com/en/products/detail/ablic-inc/S-821AAAA-I8T1U/25649782)

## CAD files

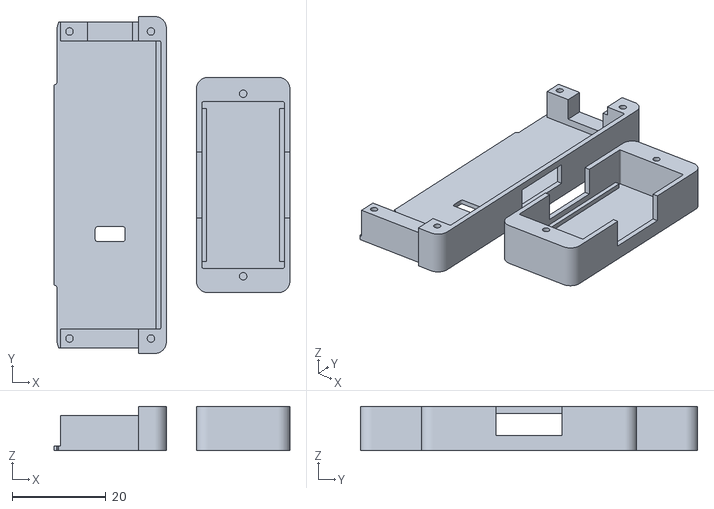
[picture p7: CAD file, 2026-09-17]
mechanical/myo-flat-v0.11/print/main-transition-rigid.stl
50.4 x 72.0 x 9.50

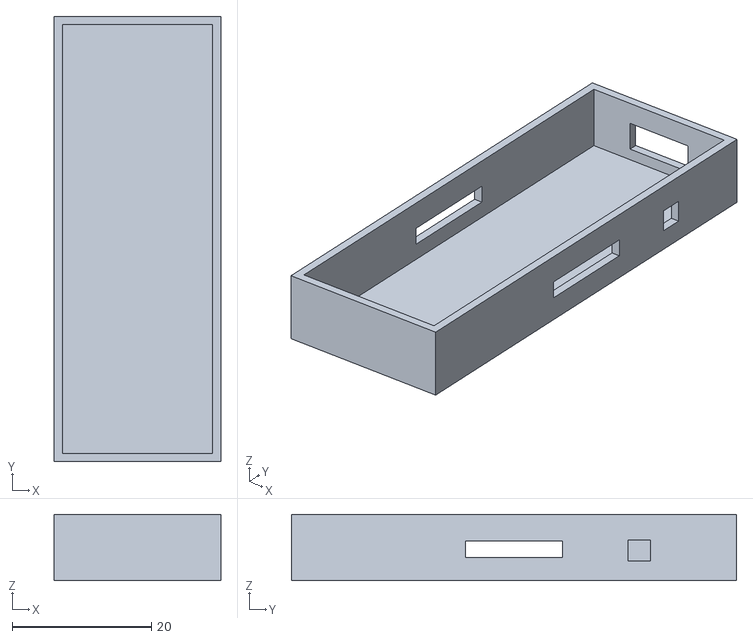
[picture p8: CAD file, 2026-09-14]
mechanical/fit-mockup/print/main-shell.stl
24.0 x 64.0 x 9.50

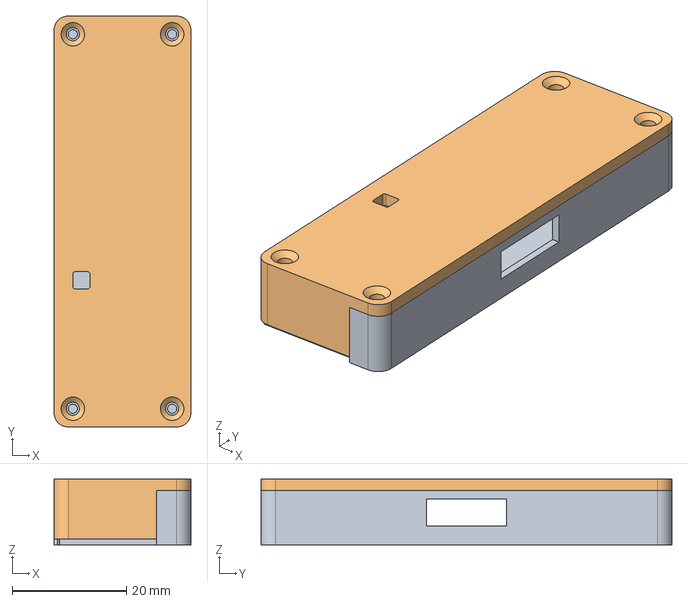
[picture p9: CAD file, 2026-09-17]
mechanical/myo-flat-v0.11/cad/main-clamshell-assembled.step
24.0 x 72.0 x 11.5 mm

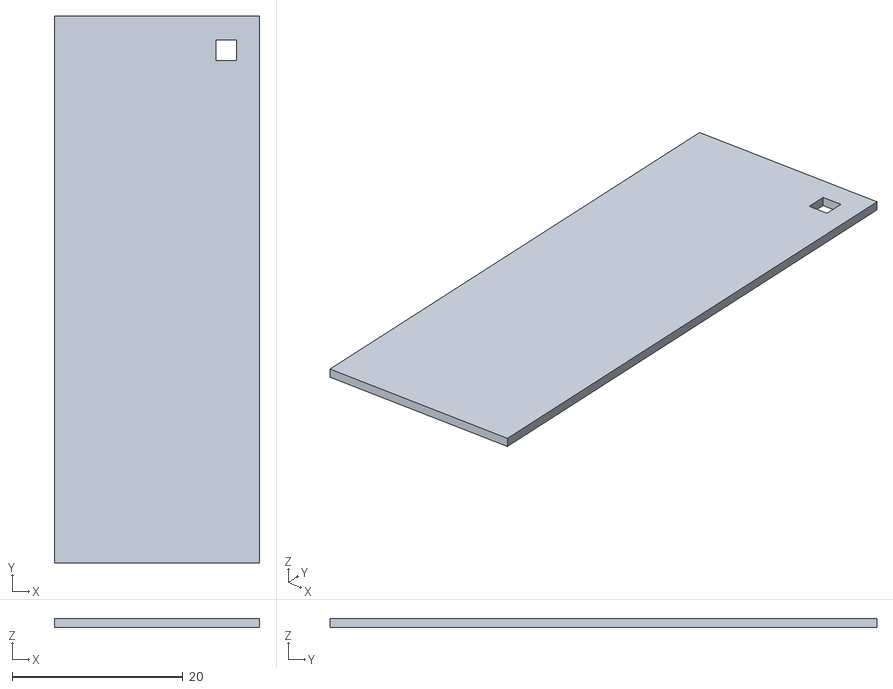
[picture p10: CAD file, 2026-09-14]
mechanical/fit-mockup/print/main-lid.stl
24.0 x 64.0 x 1.00

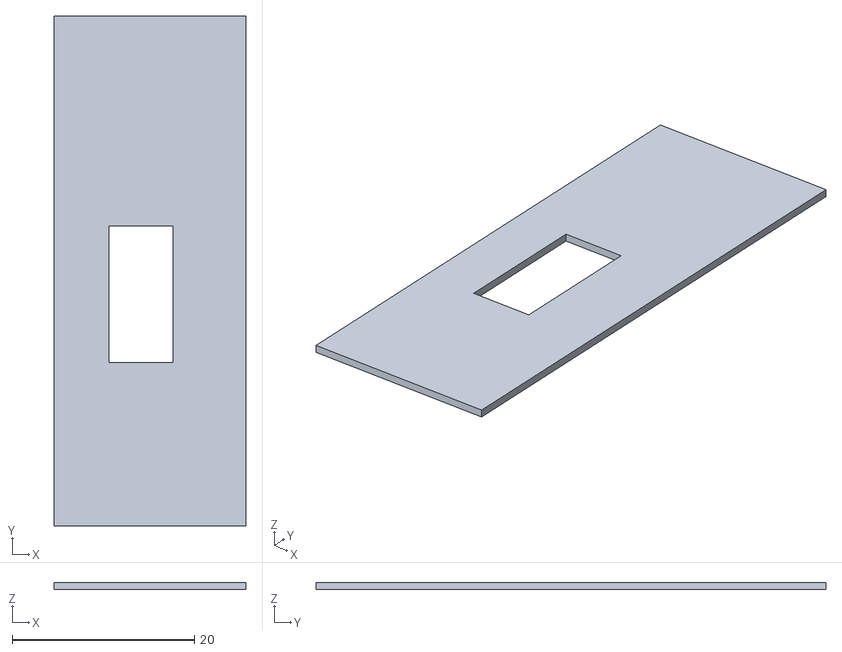
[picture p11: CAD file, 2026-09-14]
mechanical/fit-mockup/reference-only/main-pcb-gauge.stl
21.0 x 55.9 x 0.8

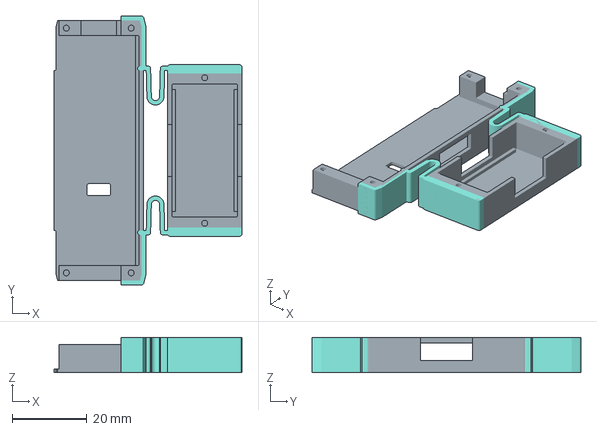
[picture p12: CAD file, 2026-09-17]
mechanical/myo-flat-v0.11/print/main-transition-coupon.3mf
50.4 x 72.0 x 9.50 mm

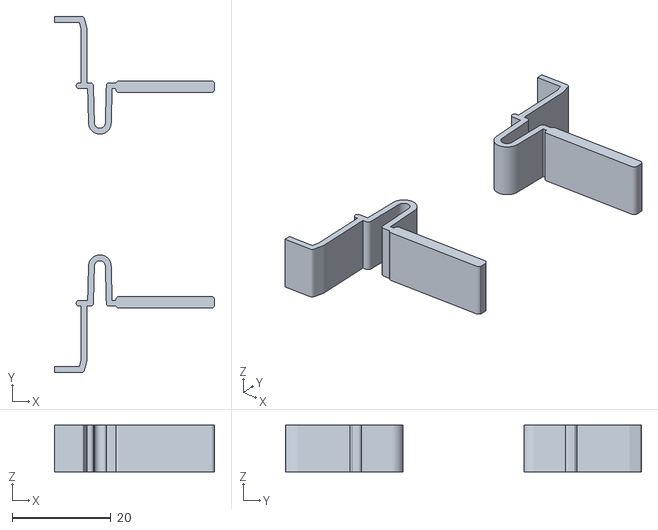
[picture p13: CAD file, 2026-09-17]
mechanical/myo-flat-v0.11/print/main-transition-tpu.stl
32.4 x 72.0 x 9.50

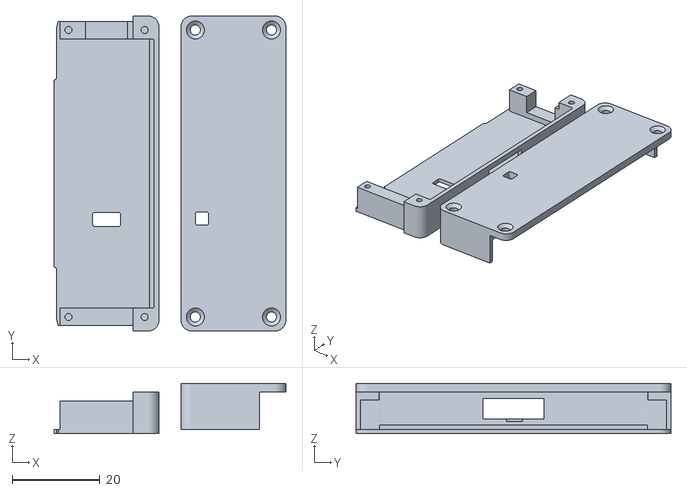
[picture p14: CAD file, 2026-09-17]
mechanical/myo-flat-v0.11/print/main-clamshell-fit-parts.stl
53.0 x 72.0 x 11.5

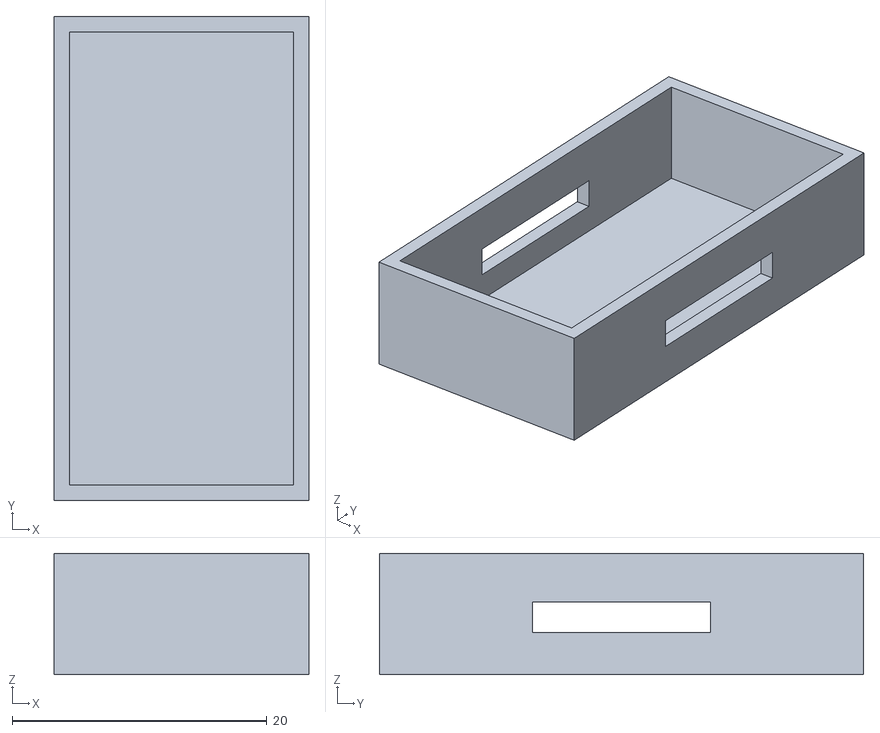
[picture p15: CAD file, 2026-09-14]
mechanical/fit-mockup/print/satellite-shell.stl
20.0 x 38.0 x 9.50

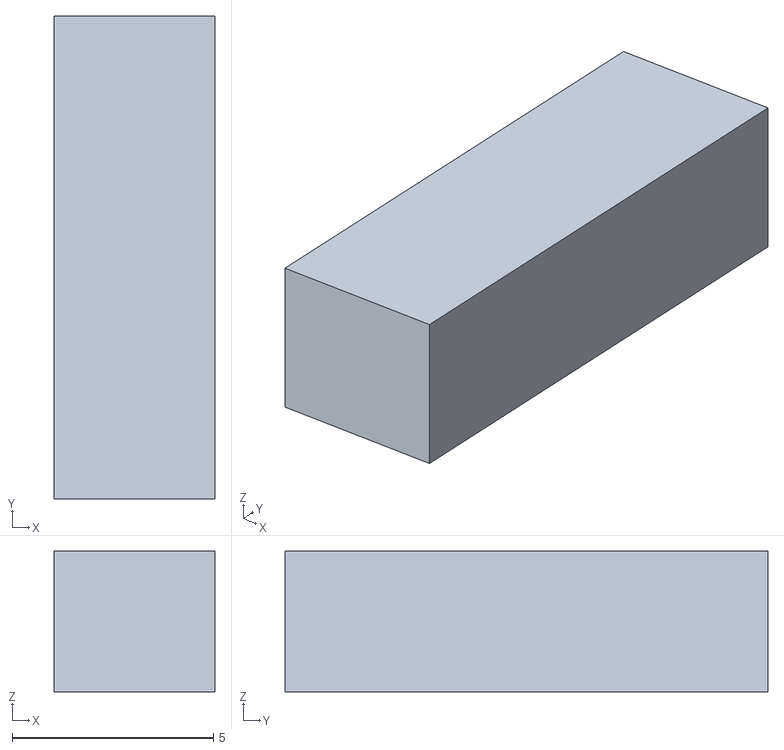
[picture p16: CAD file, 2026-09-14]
mechanical/fit-mockup/reference-only/LRA-body-4x12x3p5.stl
4.00 x 12.0 x 3.50

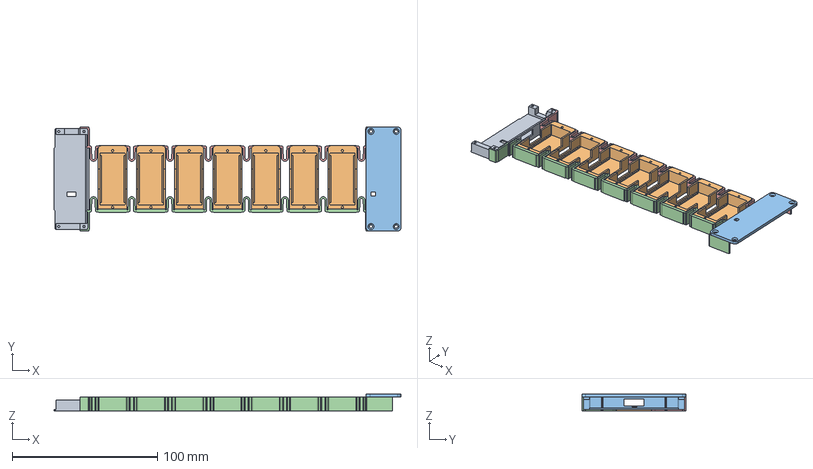
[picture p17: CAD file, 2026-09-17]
mechanical/myo-flat-v0.11/cad/flat-strip.step
239.2 x 72.0 x 11.5 mm

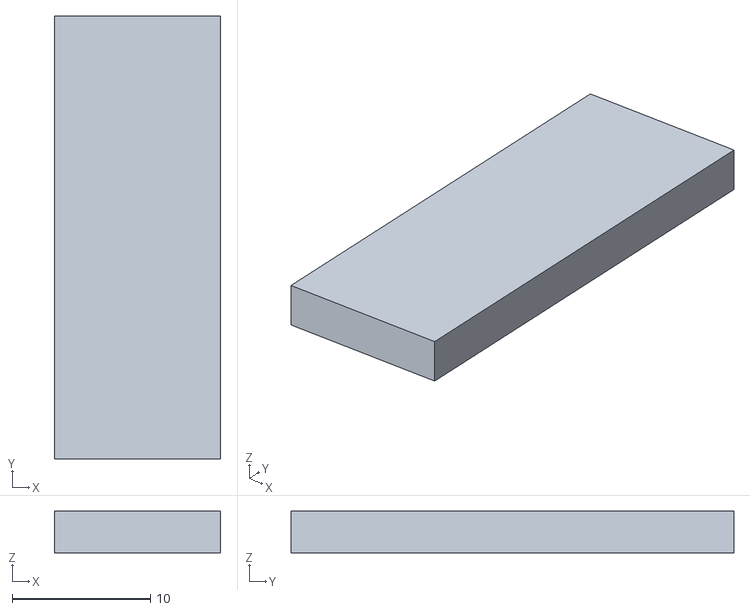
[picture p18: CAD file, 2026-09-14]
mechanical/fit-mockup/reference-only/protected-cell-body-12x32x3.stl
12.0 x 32.0 x 3.00

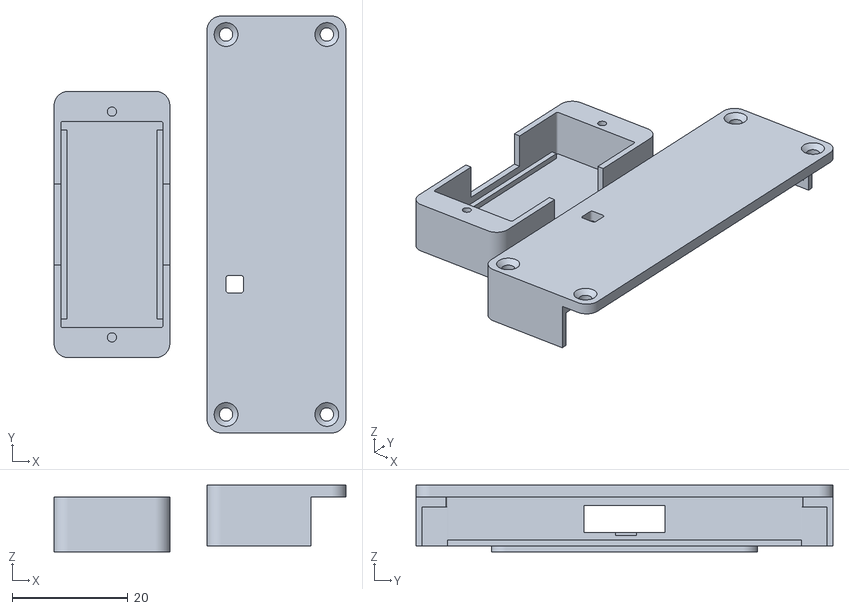
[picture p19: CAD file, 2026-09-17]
mechanical/myo-flat-v0.11/print/closure-coupon-rigid.stl
50.4 x 72.0 x 11.5

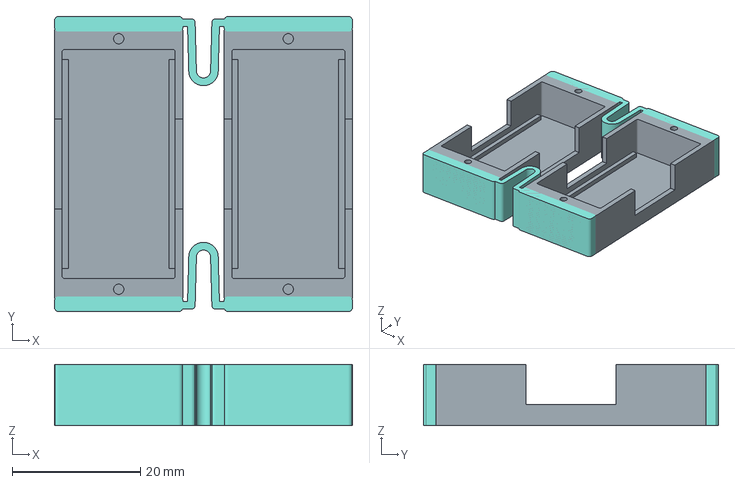
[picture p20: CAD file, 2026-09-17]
mechanical/myo-flat-v0.11/print/end-flexure-coupon.3mf
46.4 x 46.0 x 9.50 mm

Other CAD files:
mechanical/fit-mockup/print/satellite-lid.stl
mechanical/fit-mockup/reference-only/satellite-pcb-gauge.stl
mechanical/myo-flat-v0.11/print/coupon-rigid.stl
mechanical/myo-flat-v0.11/print/coupon-tpu.stl
mechanical/myo-flat-v0.11/print/closure-coupon-tpu.stl
mechanical/myo-flat-v0.11/print/closure-transition-coupon.3mf
mechanical/myo-flat-v0.11/print/myo-flat-band.3mf
mechanical/myo-flat-v0.11/print/rigid-strip.stl
mechanical/myo-flat-v0.11/print/satellite-lid.stl
mechanical/myo-flat-v0.11/print/tpu-end-flexures.stl

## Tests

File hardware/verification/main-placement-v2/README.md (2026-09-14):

# Applied main placement, 2026-09-13

See ../../../docs/main-board-placement.md for constraints and distances. main.kicad_pcb is the applied 70-part checkpoint; placement.png/svg show native pads and courtyard bounds. The active sources are ../../main/. Current acceptance reports are ../project-split/.

input.kicad_pcb is the user placement with the new Tag-Connect footprint synchronized before optimization. previous.xml and active-latest* capture intermediate redraw checks; they are historical. metrics.json is an earlier candidate measurement and is superseded by critical-distances.json and the final native reports. apply-input-hashes.json documents a guarded apply attempt that correctly refused an intervening user save.

Latest original files are backed up under ../../backups/pre-main-placement-v2-latest-20260913/. Final placement has fixed user edge anchors, one existing NRST/VDD segment, no vias and 196 opens. This is placement evidence, not routing or fabrication qualification. One M2003 reset-input ERC item and three ESP32 silk/library DRC warnings remain.

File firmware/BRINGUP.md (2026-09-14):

# Firmware bring-up console

The ESP32-C6 controller provides a native USB Serial/JTAG console for incremental pod and telemetry checks. This is a diagnostic interface, not evidence that the bracelet has been flashed or qualified.

## Safety boundary

- Use a current-limited bench supply for first power and keep the bracelet off-body.
- Charging remains disabled in this firmware.
- Bus and actuator commands latch manual mode and request all-stop before proceeding.
- A diagnostic pulse is limited to amplitude 64 and 250 ms. It is refreshed every 20 ms, followed by addressed stop and broadcast all-stop. The M2003 retains its independent 100 ms command watchdog.
- `hb flight` is the only command that releases manual mode. It is refused unless exactly eight pods are enumerated; fresh valid Backpack telemetry is still required before output.

## Connect

Build and flash the controller, then open its native USB serial port at 115200 baud. Run `help` for the ESP-IDF command list or `hb help` for the bracelet commands.

| Command | Result |
| --- | --- |
| `hb status` | Show manual/flight mode, ring state, enumerated count and telemetry age. |
| `hb telemetry` | Print the latest decoded pitch, roll and yaw in radians times 10000. |
| `hb manual` | Latch manual mode and request all-stop. |
| `hb flight` | Release manual mode only when eight pods are enumerated. |
| `hb stop` | Latch manual mode and request broadcast all-stop. |
| `hb ring restart` | Power-cycle the pod rail, wait through the LDROM window and enumerate one through eight pods. |
| `hb ring off` | Stop output, detach the UART and switch the pod rail off. |
| `hb pod status all` | Stop automatic output and read every enumerated driver's identity, state, status and calibration values. |
| `hb pod status 0` | Read one enumerated pod. |
| `hb pod pulse 0 24 80` | Drive pod 0 at RTP amplitude 24 for 80 ms, then stop. |

## Staged procedure

1. Flash one M2003 with the bracelet application and LDROM through ICE. Restore its UART links after programming.
2. Connect that pod as a complete one-pod ring return. Power the controller from a current-limited supply and run `hb ring restart`.
3. Confirm `hb status` reports one pod. Run `hb pod status 0`; require the expected DRV2625 chip ID, `ready` state, and no fault bits before applying RTP.
4. Begin with `hb pod pulse 0 8 40`. Increase amplitude and duration deliberately while observing rail current, LRA behavior and driver status. Do not increase the checked-in limits from perception alone.
5. Add pods one at a time, repeating enumeration and status checks. On the last satellite, verify JP1 is cut from 1-2 and bridged 2-3 before expecting the full return path.
6. With eight healthy pods, configure the Backpack MAC and Wi-Fi channel, verify `hb telemetry`, then use `hb flight` to allow the provisional mapping.
7. Exercise telemetry loss, ring interruption and pod-power restart while measuring the farthest-pod rail and UART return. Record actual startup and discharge timing before changing the hard-coded delays.

## Expected status fields

`chip_id`, `status`, `state`, `cal_comp`, `cal_bemf`, and `feedback` come directly from the pod's DRV2625 snapshot. Temperature is deliberately reported as unavailable until PB2 conversion and the selected thermistor curve are implemented.

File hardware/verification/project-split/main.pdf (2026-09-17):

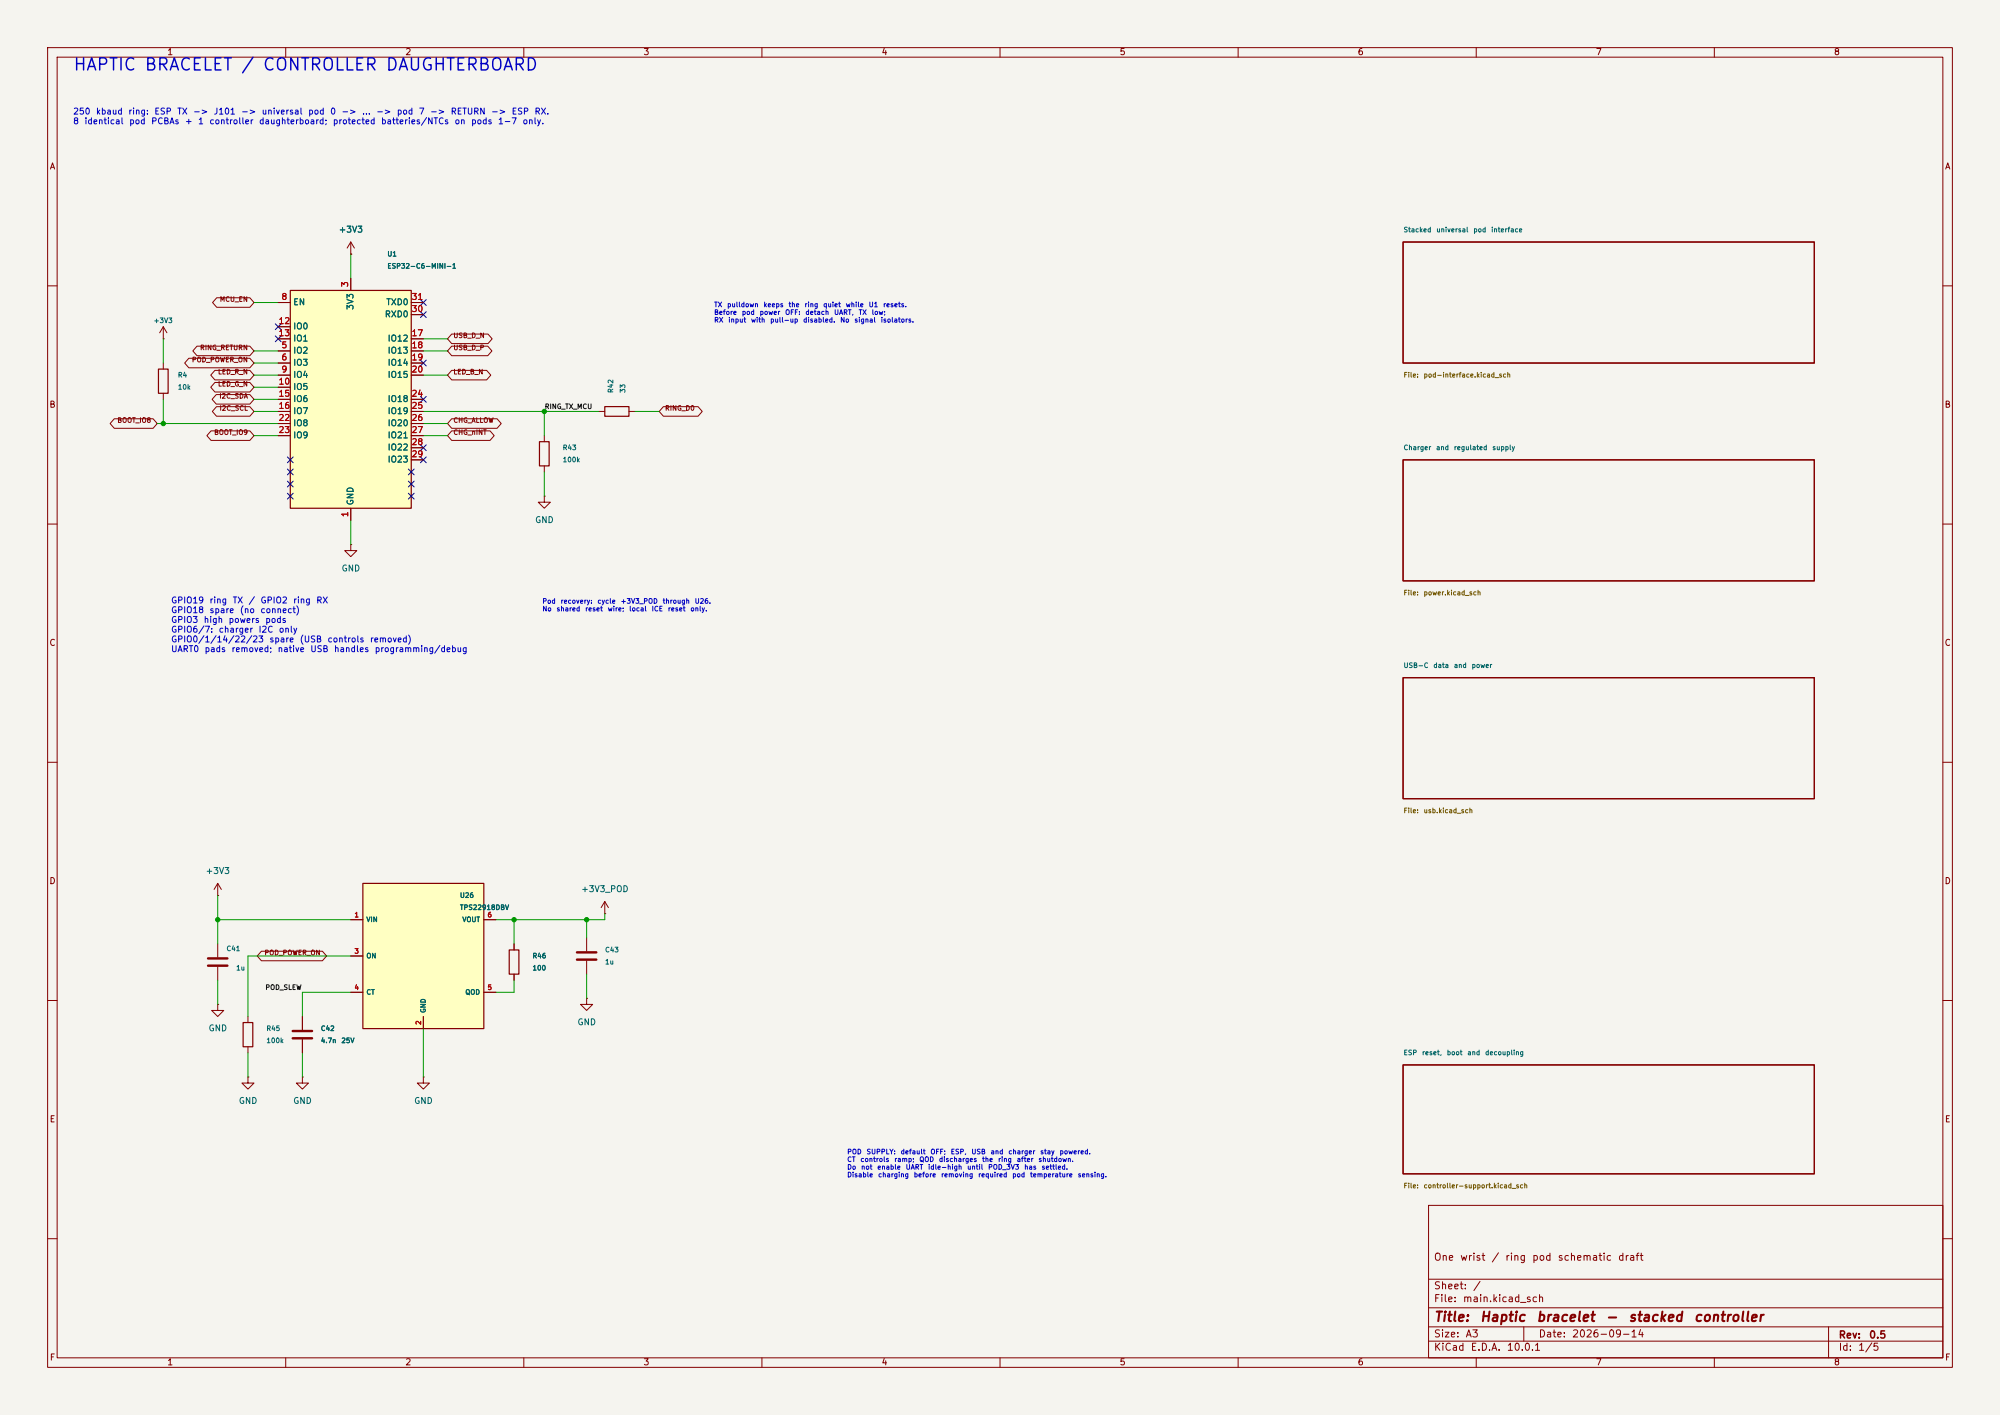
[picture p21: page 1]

HAPTIC BRACELET / CONTROLLER DAUGHTERBOARD

250 kbaud ring: ESP TX -> J101 -> universal pod 0 -> ... -> pod 7 -> RETURN -> ESP RX. 8 identical pod PCBAs + 1 controller daughterboard; protected batteries/NTCs on pods 1-7 only. GPIO19 ring TX / GPIO2 ring RX GPIO18 spare (no connect) GPIO3 high powers pods

Stacked universal pod interface
File: pod-interface.kicad_sch USB-C data and power File: usb.kicad_sch

TX pulldown keeps the ring quiet while U1 resets. Before pod power OFF: detach UART, TX low; RX input with pull-up disabled. No signal isolators.

Charger and regulated supply File: power.kicad_sch

Pod recovery: cycle +3V3_POD through U26. No shared reset wire; local ICE reset only.

GPIO6/7: charger I2C only
GPIO0/1/14/22/23 spare (USB controls removed) UART0 pads removed; native USB handles programming/debug

ESP reset, boot and decoupling

POD SUPPLY: default OFF; ESP, USB and charger stay powered. CT controls ramp; QOD discharges the ring after shutdown. Do not enable UART idle-high until POD_3V3 has settled. Disable charging before removing required pod temperature sensing.

One wrist / ring pod schematic draft

Sheet: /
File: main.kicad_sch
Title: Haptic bracelet - stacked controller

Size: A3 | Rev: 0.5 | F Date: 2026-09-14
KiCad E.D.A. 10.0.1 | Id: 1/5

1 | 2 | 3 | 4 | 5 | 6
1 | 2 | 3 | 4 | 5 | 6

AB

C

D

AB

C

## D Date: 2026-09-14

Size: A4 | Rev: 1.0

# Title: Controller to universal pod stack

### File: pod-interface.kicad_sch

### Sheet: /Stacked universal pod interface/

### One wrist / ring pod schematic draft

1
2
3
4
5

J101
STACK TO POD 0 | H1M1.6 CLEARANCE | H2M1.6 CLEARANCE H3M1.6 CLEARANCE | H4M1.6 CLEARANCE
VBAT | RING_RETURN +3V3_POD
GND
RING_D0
VBAT GND | 1 Switched 3.3 V: daughterboard -> all eight pods 2 Common ground 3 ESP TX through R42 -> pod 0 RX

4 Protected VBAT bus: seven cells <-> charger 5 Last pod TX return -> ESP RX

External supply entry

# through J101: GND and VBAT CHAIN AND RETURN

Daughterboard J101 -> pod 0 J1. Each pod J2 -> next pod J1. Pods 0-6: JP1 NORMAL (1-2). Pod 7: cut 1-2, bridge 2-3 END. Pod 7 J2 is uncabled. The clasp gap remains unwired. SYSTEM ASSEMBLY One controller daughterboard; eight copies of satellite/satellite.kicad_pro. Pod 0 sits beneath this board: no battery and no external NTC fitted. Pods 1-7 each carry one protected pouch cell and its external NTC. The pod PCBA and component population are identical in all positions.

J101 connects pin-for-pin to J1 on universal pod 0. The existing five-pad footprint is retained until the mechanical stack is set. POWER AND TEMPERATURE

All eight M2003/DRV2625 nodes share switched +3V3_POD. Only pod 0 battery/NTC sockets are unused; keep its sensing/fuse circuitry. Firmware expects seven required cell sensors on pods 1-7. Disable charging if a required sensor is missing, stale or out of range. Seven-cell charge/load limits still require firmware configuration.

# CONTROLLER DAUGHTERBOARD / FIVE-CONTACT STACK INTERFACE

H1-H4: four corner M1.6 mounts. 20 x 46 mm PCB faces / TPU spacer. Standoff height and screw length TBD.

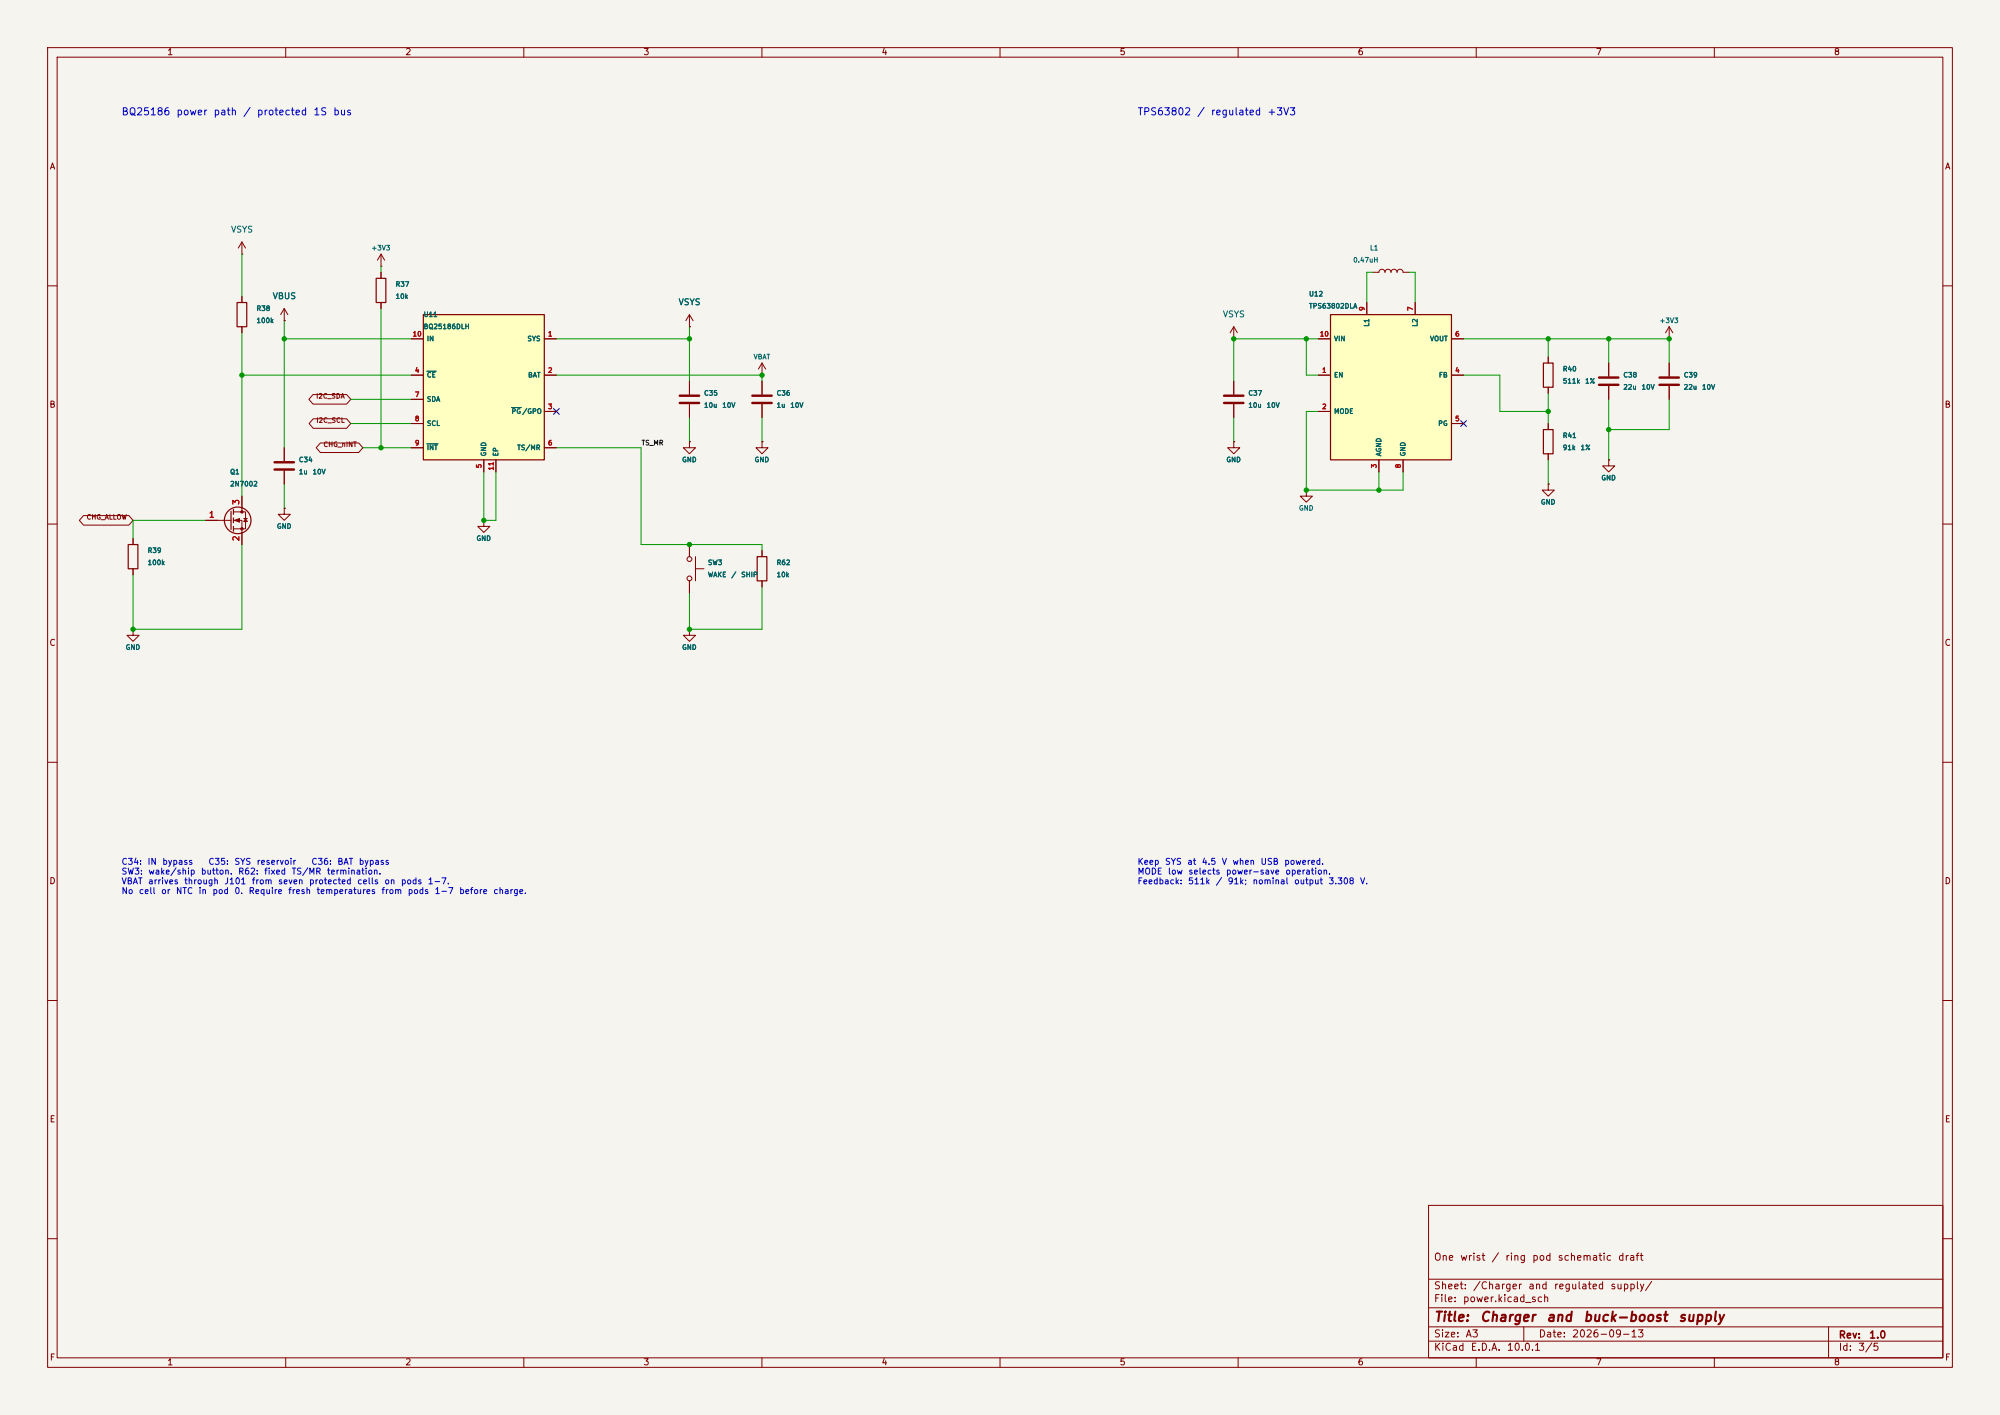
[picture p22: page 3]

BQ25186 power path / protected 1S bus

Keep SYS at 4.5 V when USB powered. MODE low selects power-save operation. Feedback: 511k / 91k; nominal output 3.308 V.

One wrist / ring pod schematic draft

Sheet: /Charger and regulated supply/
File: power.kicad_sch
Title: Charger and buck-boost supply

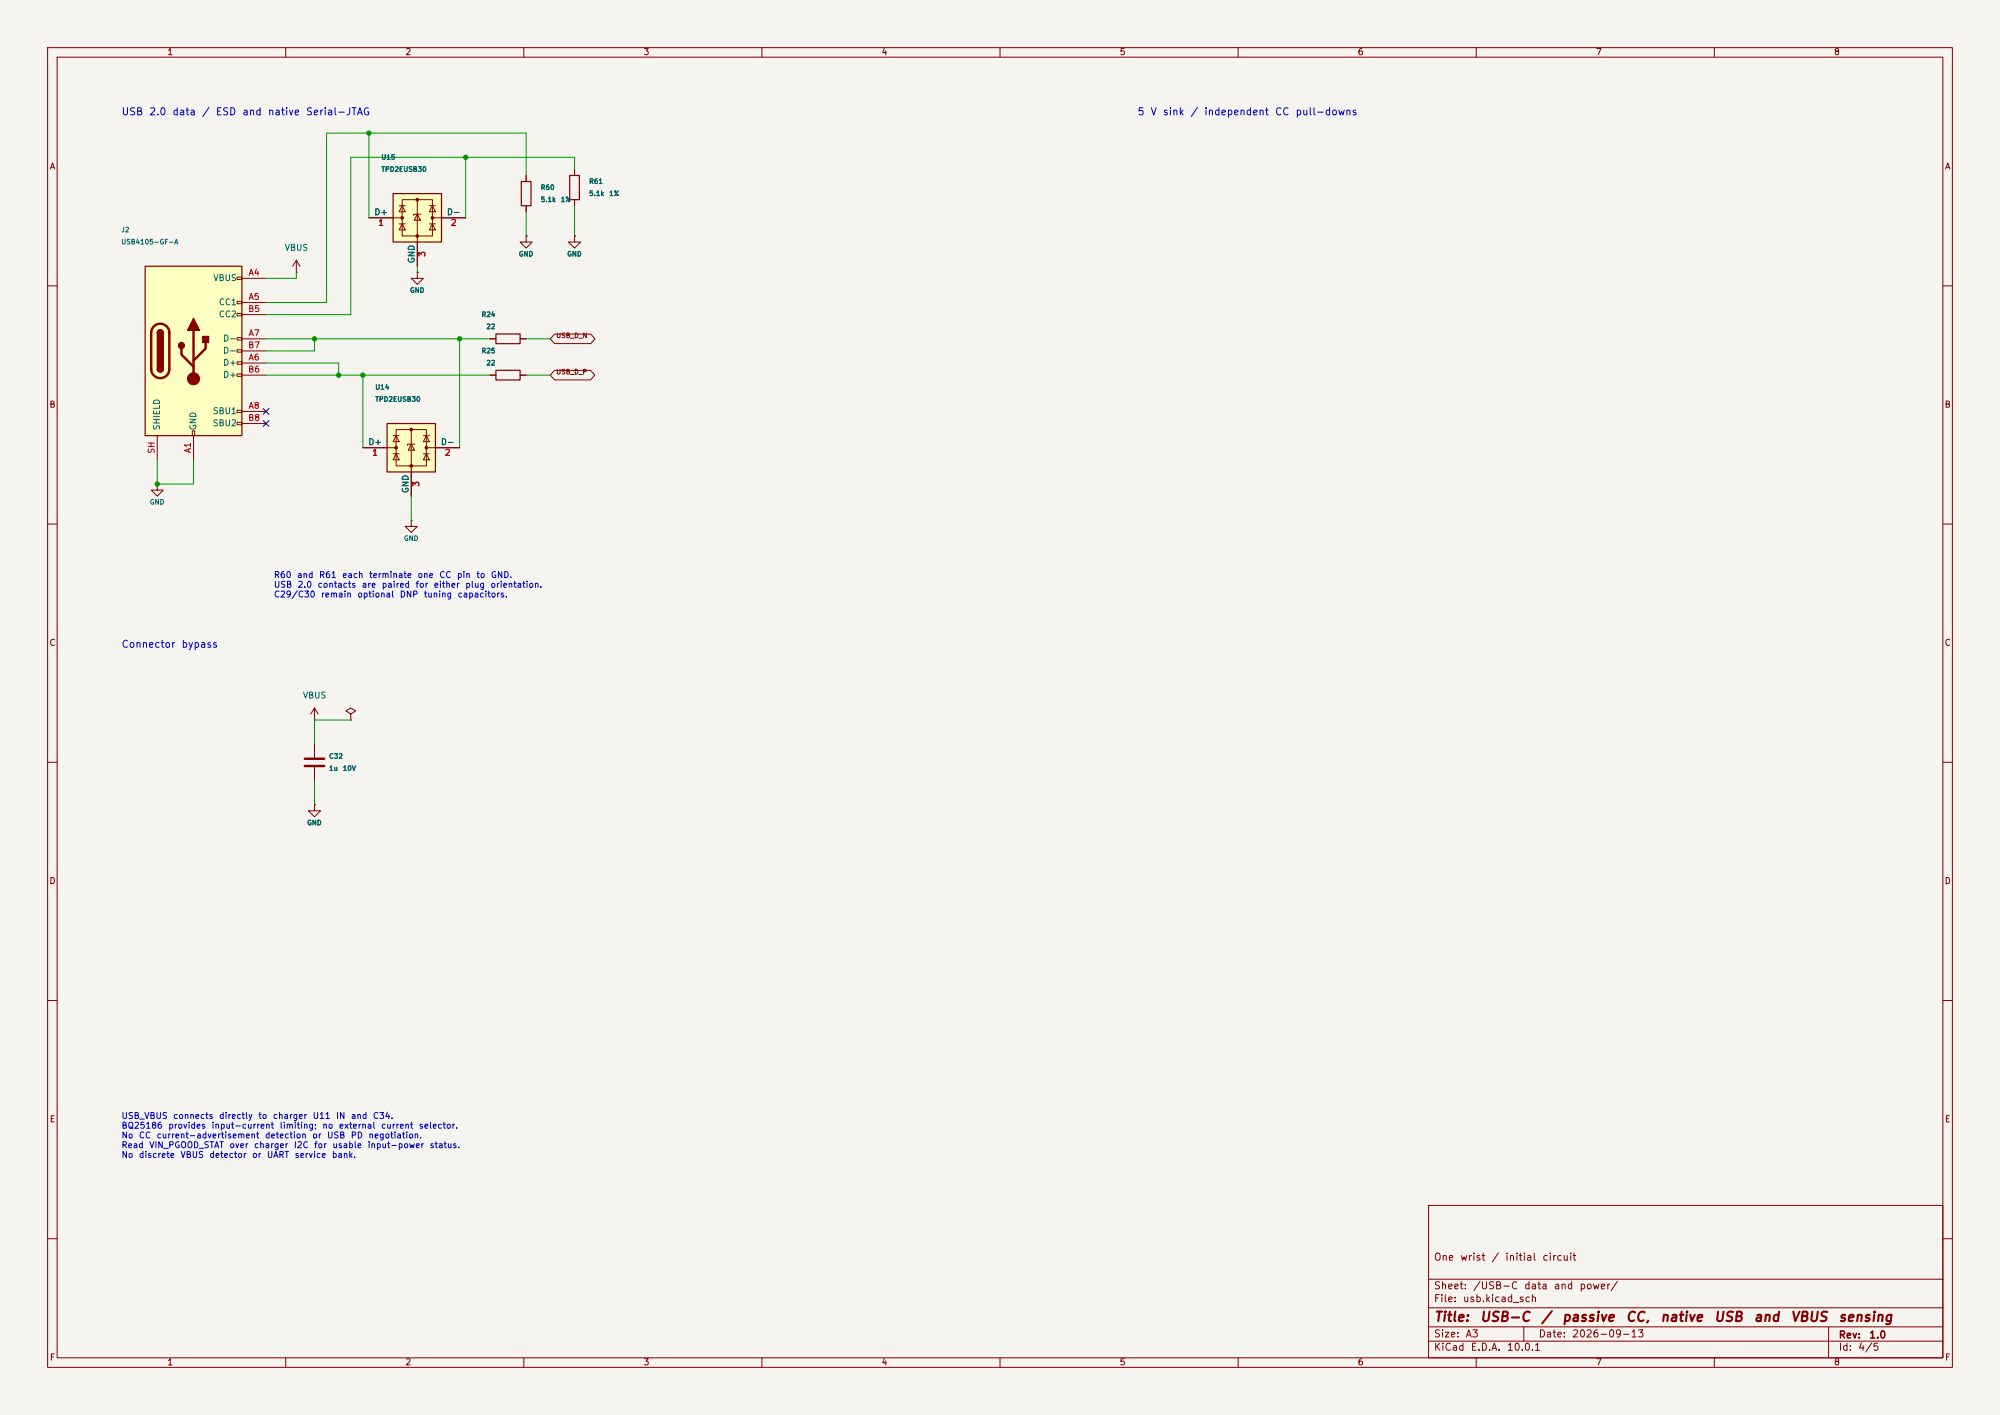
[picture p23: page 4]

USB 2.0 data / ESD and native Serial-JTAG

R60 and R61 each terminate one CC pin to GND. USB 2.0 contacts are paired for either plug orientation. C29/C30 remain optional DNP tuning capacitors.

USB_VBUS connects directly to charger U11 IN and C34. BQ25186 provides input-current limiting; no external current selector. No CC current-advertisement detection or USB PD negotiation. Read VIN_PGOOD_STAT over charger I2C for usable input-power status. No discrete VBUS detector or UART service bank.

One wrist / initial circuit

Sheet: /USB-C data and power/
File: usb.kicad_sch
Title: USB-C / passive CC, native USB and VBUS sensing

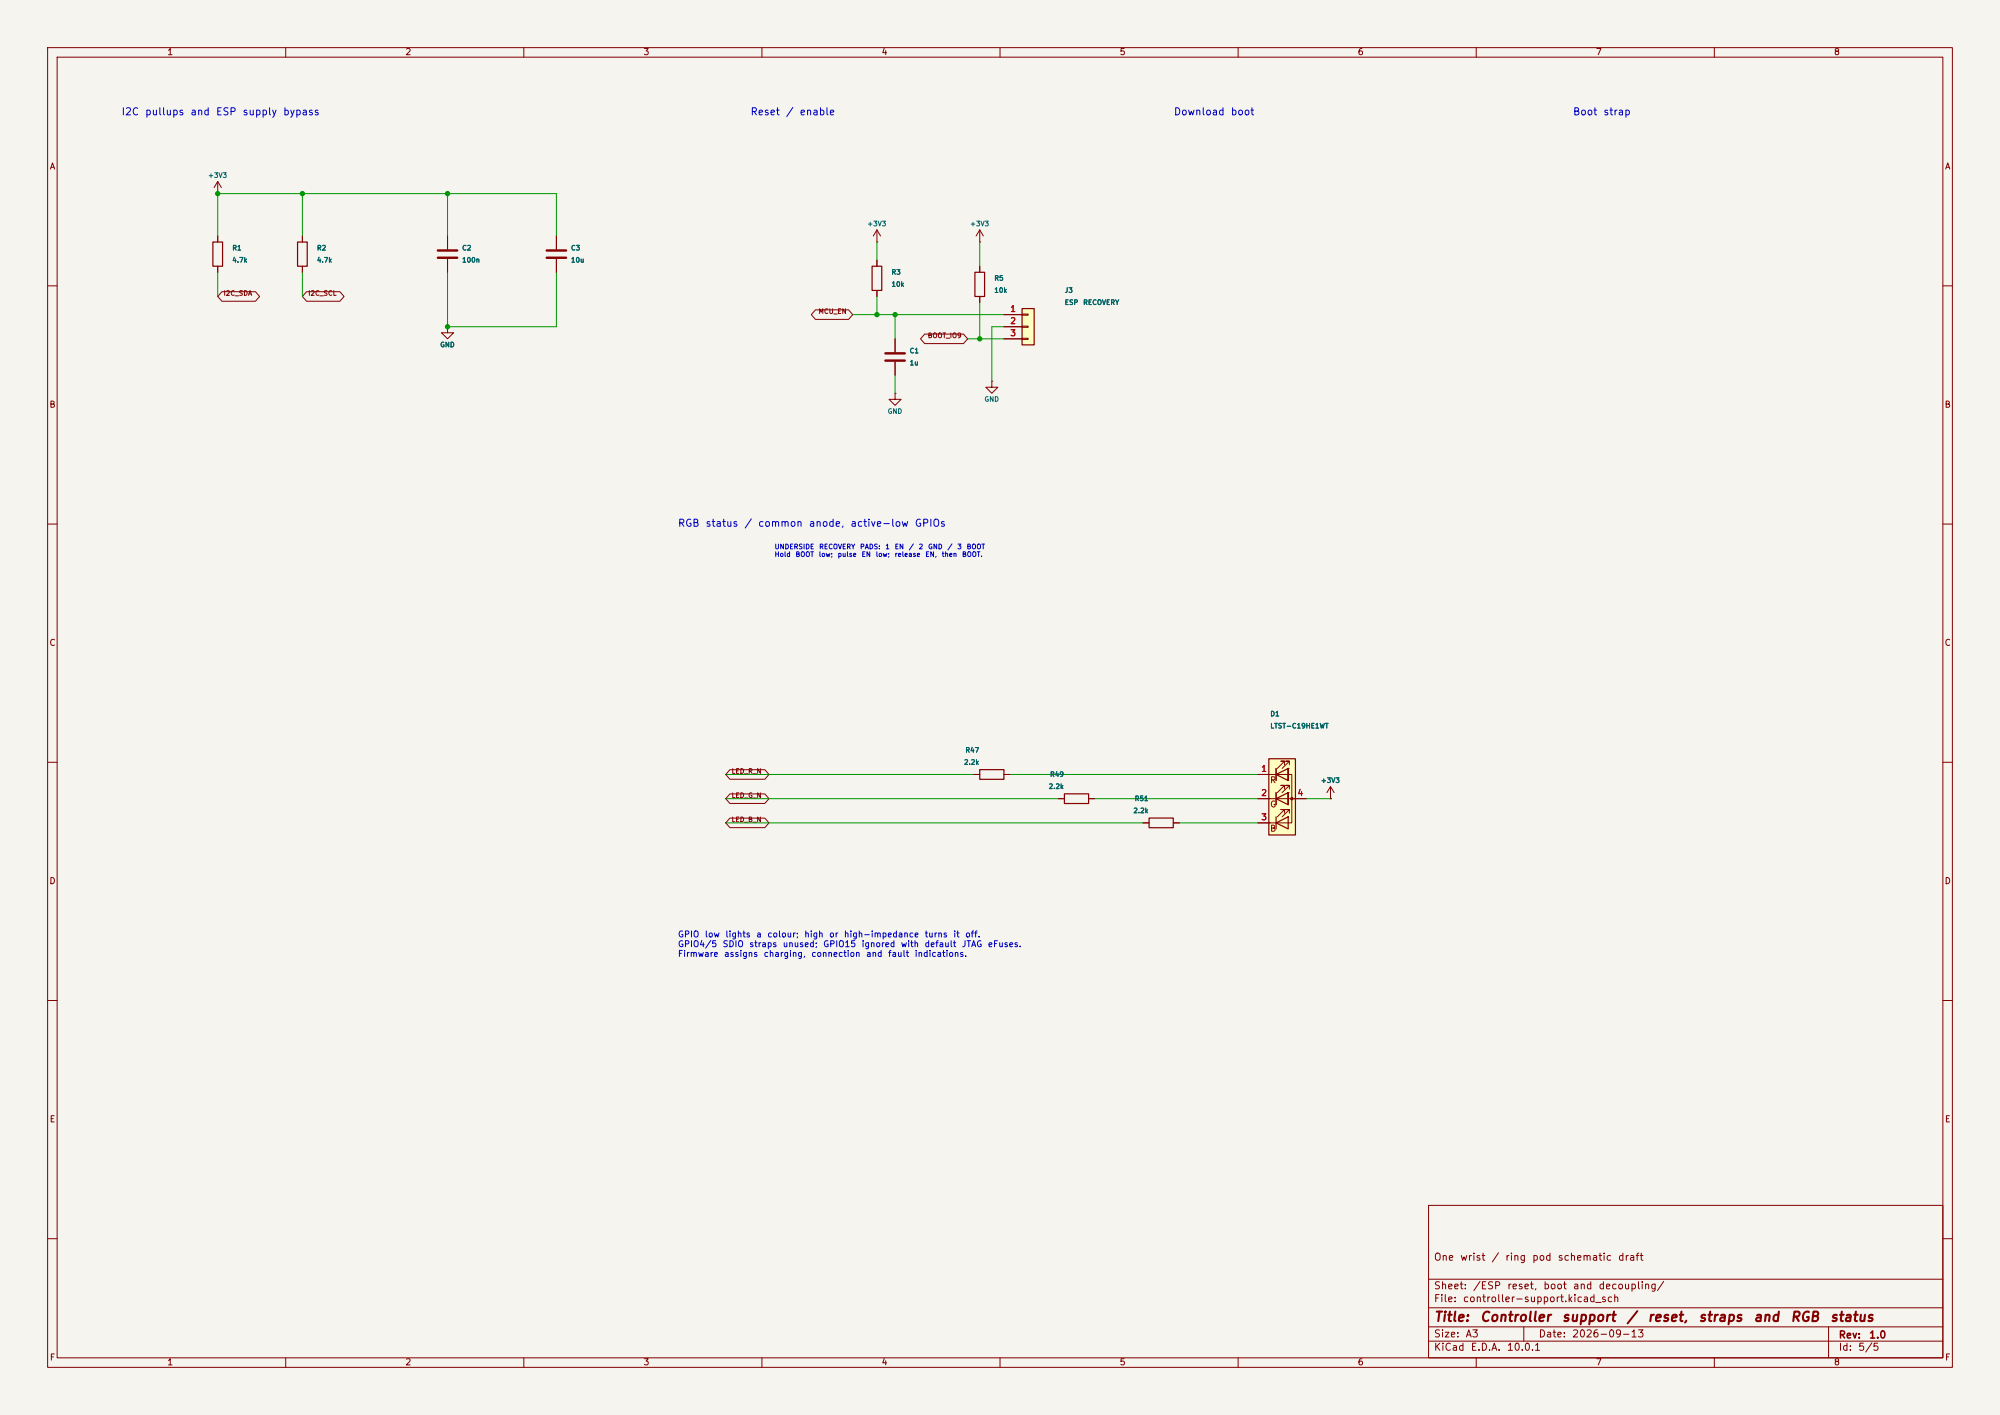
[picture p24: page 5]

UNDERSIDE RECOVERY PADS: 1 EN / 2 GND / 3 BOOT Hold BOOT low; pulse EN low; release EN, then BOOT. GPIO low lights a colour; high or high-impedance turns it off. GPIO4/5 SDIO straps unused; GPIO15 ignored with default JTAG eFuses. Firmware assigns charging, connection and fault indications. RGB status / common anode, active-low GPIOs

One wrist / ring pod schematic draft

Sheet: /ESP reset, boot and decoupling/
File: controller-support.kicad_sch
Title: Controller support / reset, straps and RGB status

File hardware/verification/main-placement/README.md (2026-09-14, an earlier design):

Exploratory placement only; never applied to the active board. User took ownership of placement. This candidate predates five-wire reset removal and J100 deletion; do not copy it over hardware/main/main.kicad_pcb.

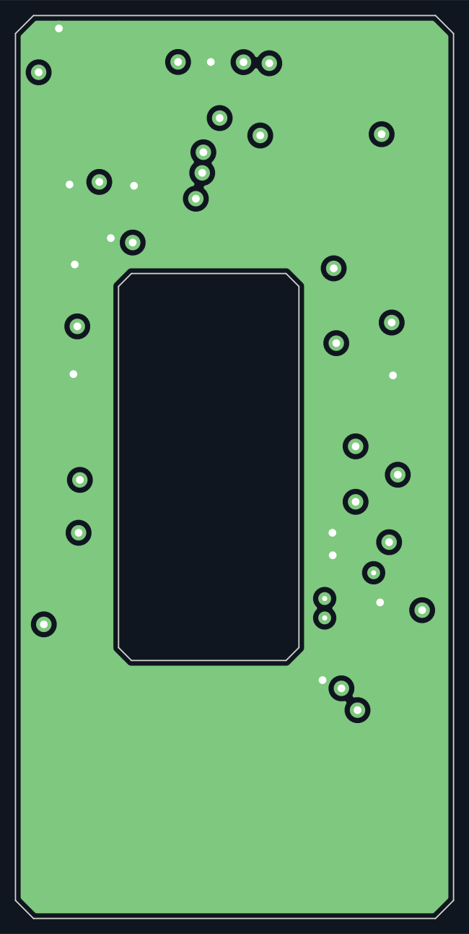
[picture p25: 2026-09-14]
hardware/verification/routing-v09/ground.png

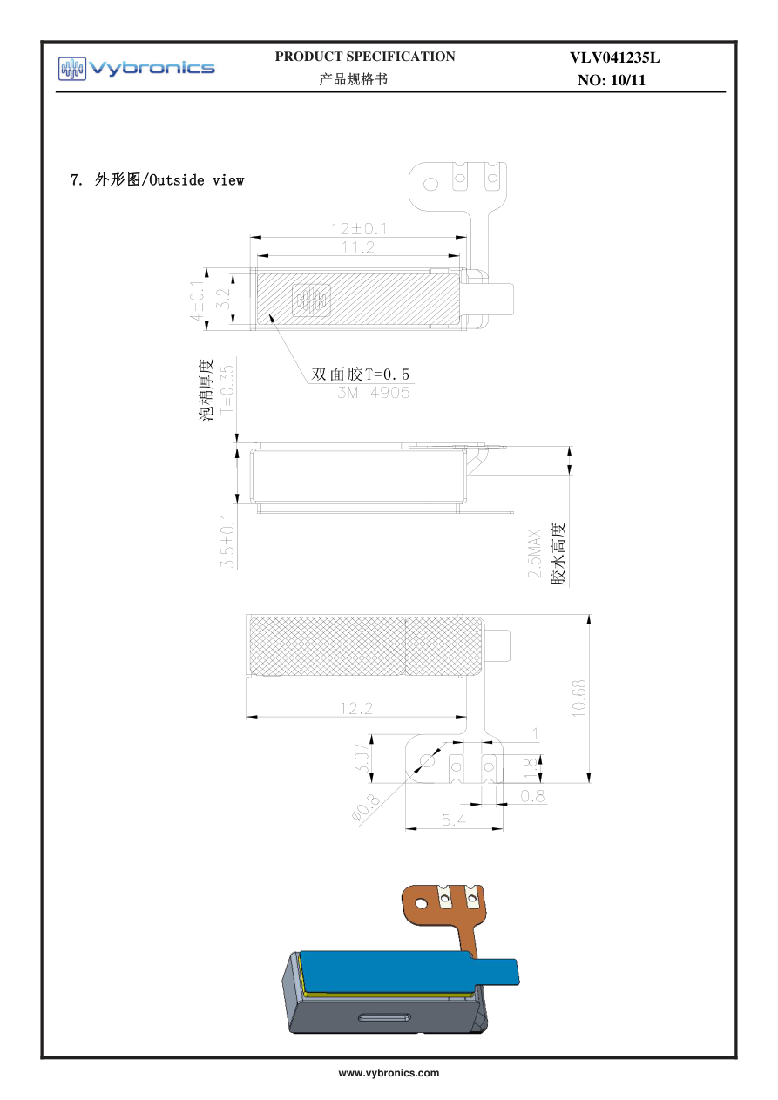
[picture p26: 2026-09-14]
hardware/verification/placement-reference/VLV041235L10.png

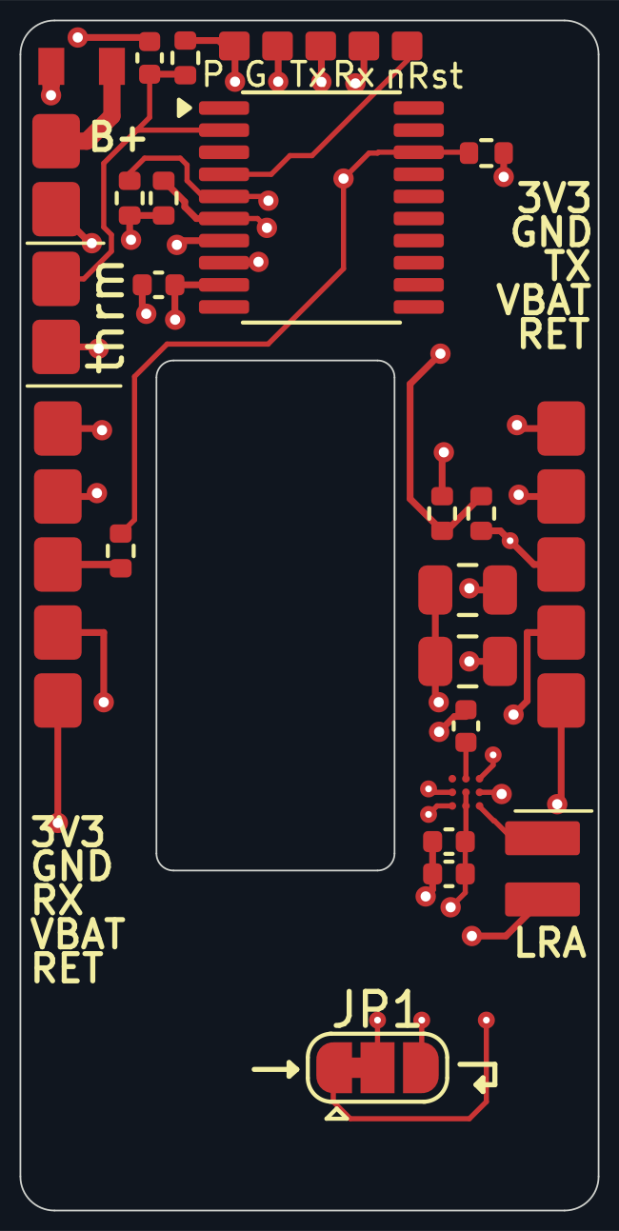
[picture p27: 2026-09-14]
hardware/verification/project-split/front.png

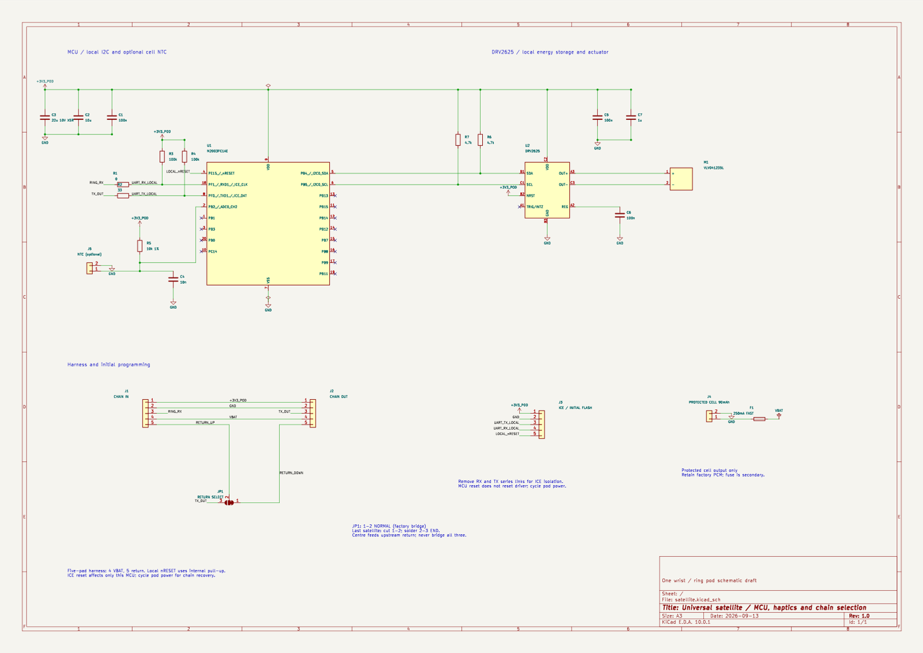
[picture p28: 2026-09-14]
hardware/verification/five-pad/satellite.png

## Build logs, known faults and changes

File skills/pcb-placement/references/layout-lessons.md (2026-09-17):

# Layout lessons and editing mechanics

These are decision criteria, not universal numerical limits. Obtain device-specific requirements from current manufacturer documentation and board-specific limits from the actual stackup and fabrication rules.

## Electrical groups

### Build local subgroups before the board-wide arrangement

The user's preferred process is to group components with the parts they functionally support in the schematic and arrange those in tight subgroups before arranging the groups on the board. Use the schematic to understand ownership; this does not itself authorize redrawing it.

1. Identify the associated IC/function and actual pins for each passive: bypass, feedback, termination, pull-up, strap, filter, current sense, or bias. Group by electrical function, not reference-number order or visual proximity in the existing PCB.
2. Arrange and rotate the subgroup around those pins, respecting critical supply/return loops and routing channels. Aim for at least one useful same-layer termination per passive where practical.
3. Arrange the subgroups around fixed mechanical/RF anchors and their interface connections. Preserve useful internal arrangements while moving/rotating a group; refine individual parts where group interfaces require it.
4. Inspect passives with immediate via exits on both pads. Trace each end to its functional destination and consider a rotation, a local move, or a subgroup orientation change before accepting two layer changes. Do not move the via into the solder pad as a substitute for better placement.
5. Recheck local routing and surrounding congestion, then compare length/via counts and DRC. A small global score increase can be acceptable when local loops, same-layer connections or routability improve.

This two-via observation is a review heuristic, not an automatic failure. A ground-plane via beside a bypass capacitor is often useful. Via count alone cannot justify lengthening a return path or violating electrical constraints. Distinguish two short plane connections from avoidable fan-out caused by a passive placed away from both of its destinations. Do not invent a universal millimetre threshold for "immediate"; inspect the local geometry and state any threshold used by a future analyzer.

The bundled length evaluator does **not** yet classify functional subgroups or detect passives with via exits at both ends. Perform that review from schematic/board connectivity and routes; do not claim the metric report checks it.

### Preferred four-layer arrangement

| Layer | Preferred role |
| --- | --- |
| F.Cu | Components, short local connections and signal routing |
| In1.Cu | Continuous, unbroken ground reference plane |
| In2.Cu | Power distribution partitioned into regions for the required rails |
| B.Cu | Signal/local routing and components where the assembly permits |

Keep general signal traces on the two outer layers. Do not cut signal channels through the ground plane to rescue a crowded placement. "Unbroken" means preserve a continuous useful return reference, allowing necessary holes/antipads and documented RF keepouts; inspect those features for accidental slots or narrow necks. Avoid blanket ground removal beneath ordinary signal paths.

Rail regions on the power layer must remain electrically isolated where required and have adequate current-carrying paths. Bottom signals can reference this adjacent power layer, so a power-plane split can disrupt their return path even with an unbroken ground plane elsewhere. Review crossings, actual layer spacing, reference changes and suitable return paths rather than assuming the preferred layer names guarantee signal integrity. Critical signals may need relocation to the top layer. Retain the user's preference unless a verified requirement warrants a explained exception; it is not permission to silently redesign another project's stackup.

- Place primary bypass capacitors for a short supply-and-return path to the actual IC pins. Distance to a component centre is not sufficient. A close capacitor with a long ground detour is not good decoupling. Secondary bulk capacitance has different placement priority.
- Arrange regulator input capacitor, power pins, inductor and output capacitor around the manufacturer's current paths. Minimize high-di/dt loop area; avoid using aggregate airwire length as a substitute. Keep feedback/sense paths away from switching copper and join control/power grounds as specified for that regulator.
- Order USB protection and passives according to the actual circuit and device guidance. Place protection near the connector; keep paired routes continuous and avoid stubs or unnecessary layer transitions. Do not assume a numerical trace width or spacing until the production stackup is known. Series-resistor location is device-specific.
- Place reset, strap and pull-up parts near their relevant pins when this shortens useful routing. Check boot requirements and service access; do not add hardware to eliminate a documented symbol-model ERC limitation without checking the actual device behavior.
- Maintain return-path continuity. A short trace crossing a reference-plane gap can be worse than a longer trace over a continuous reference. Plane assignments and solid-versus-thermal policies belong to the project, not to this general skill.
- Preserve antenna keepout geometry from the exact module drawing, including applicable copper layers, components, metal fasteners, batteries and enclosure material. A footprint/library mismatch on an RF module warrants inspection, not automatic replacement of the user's footprint.

## Mechanical and assembly constraints

- F.Cu/B.Cu are file layer names, not synonyms for outward/skin-facing. Inspect the physical stack and current layer assignments. A top-view drawing of B.Cu is not a bottom-side assembly view; label viewing conventions.
- Check courtyards together with full component height, screw heads, standoff bodies, tool access, wire bends, battery adhesive, actuator travel and enclosure contact strips. Opposite-side parts may overlap in XY but still collide through holes or the assembled stack.
- Mechanical drawing guides do not enforce copper/placement keepouts. Identify which constraints are actual DRC rules and which need a separate geometry check.
- PCB-as-shell construction makes exposed pads, button loads and supported edges part of placement. Put a low-profile top-push switch on the intended accessible face; do not infer finger usability from its electrical package height. A flexible cover must avoid preload and needs a physical feel/overtravel trial.
- Preserve accepted assembly methods and user capabilities. Do not substitute a larger package solely on assumptions about the user's soldering skill. Check actual process limits, solder-mask webs and via-in-pad policy.

## Footprints and 3D models

- Read the dimensional drawing for the exact suffix. Similar switch families can have different terminal cutouts, land patterns and stencil requirements. Body size is not land-pattern size.
- Check pin numbering, duplicate-number pads, mounting tabs, underside exposed metal and no-solder regions. A schematic/PCB net match cannot prove that the physical pin numbering is right.
- Paste area percentages are area ratios, not per-axis scale factors. If a symmetric reduction uses a ratio r per edge, retained area is (1 + 2r)^2. Record the stencil thickness separately.
- Prefer exact manufacturer or trusted-library STEP models. If unavailable and a simple visualization is useful, create a clearly labeled nominal envelope from verified dimensions. Do not portray terminal/internal details or tolerance fit as verified. Put shared models in a project-local directory with relocatable paths, and attach them to both library and placed footprints.
- Render the actual placed side and inspect seating plane, scale, actuator direction and alignment. B-side transforms should be handled by the footprint placement rather than an improvised mirrored STEP.

## KiCad automation lessons

- Prefer native APIs/CLI for geometry and validation, with a narrowly bounded source patch when a full save would rewrite unrelated user content. Parse S-expressions with a real parser or quote-aware balanced scan, not an unrestricted regex for nested structure.
- Keep library IDs, footprint UUIDs, schematic paths and pad nets through replacement. Do not assume Python exposes a writable `m_Uuid` property. Verify the installed API instead of guessing setter names.
- In KiCad 10's legacy Python API, add a loaded footprint to its board before calling `Flip`; an unattached footprint hung in this workflow. Use an explicit supported flip direction.
- Newly added metadata fields may default to visible silkscreen. Hide MPN/manufacturer/BOM notes, put them on fabrication layers, and handle B-side text mirroring. Otherwise metadata creates spurious silkscreen and edge violations.
- KiCad DRC reports a track object's position, which may be its start rather than the nearest unconnected endpoint. Do not measure that position blindly. The bundled evaluator resolves pad and track anchors, and errors on unsupported endpoints.
- Raw ratsnest objects in the installed legacy Python bindings may be opaque SWIG pointers. Do not claim an exact ratsnest extraction when using a reconstructed metric.
- On managed Windows, use writable `KICAD_DOCUMENTS_HOME` and `KICAD_CONFIG_HOME`. Registry warnings alone did not imply export failure here; use exit status, output existence and parsed content to decide success.
- Reopen externally edited files in a live KiCad editor before saving its stale copy. If there is evidence of unsaved user work, preserve/resolve it before mutation; a warning after overwriting does not protect that work.
- KiCad's legacy Python API is version-dependent and deprecated. The bundle is tested with KiCad 10; inspect or migrate APIs when the installed version changes. Historical migration scripts are not safe incremental editors.

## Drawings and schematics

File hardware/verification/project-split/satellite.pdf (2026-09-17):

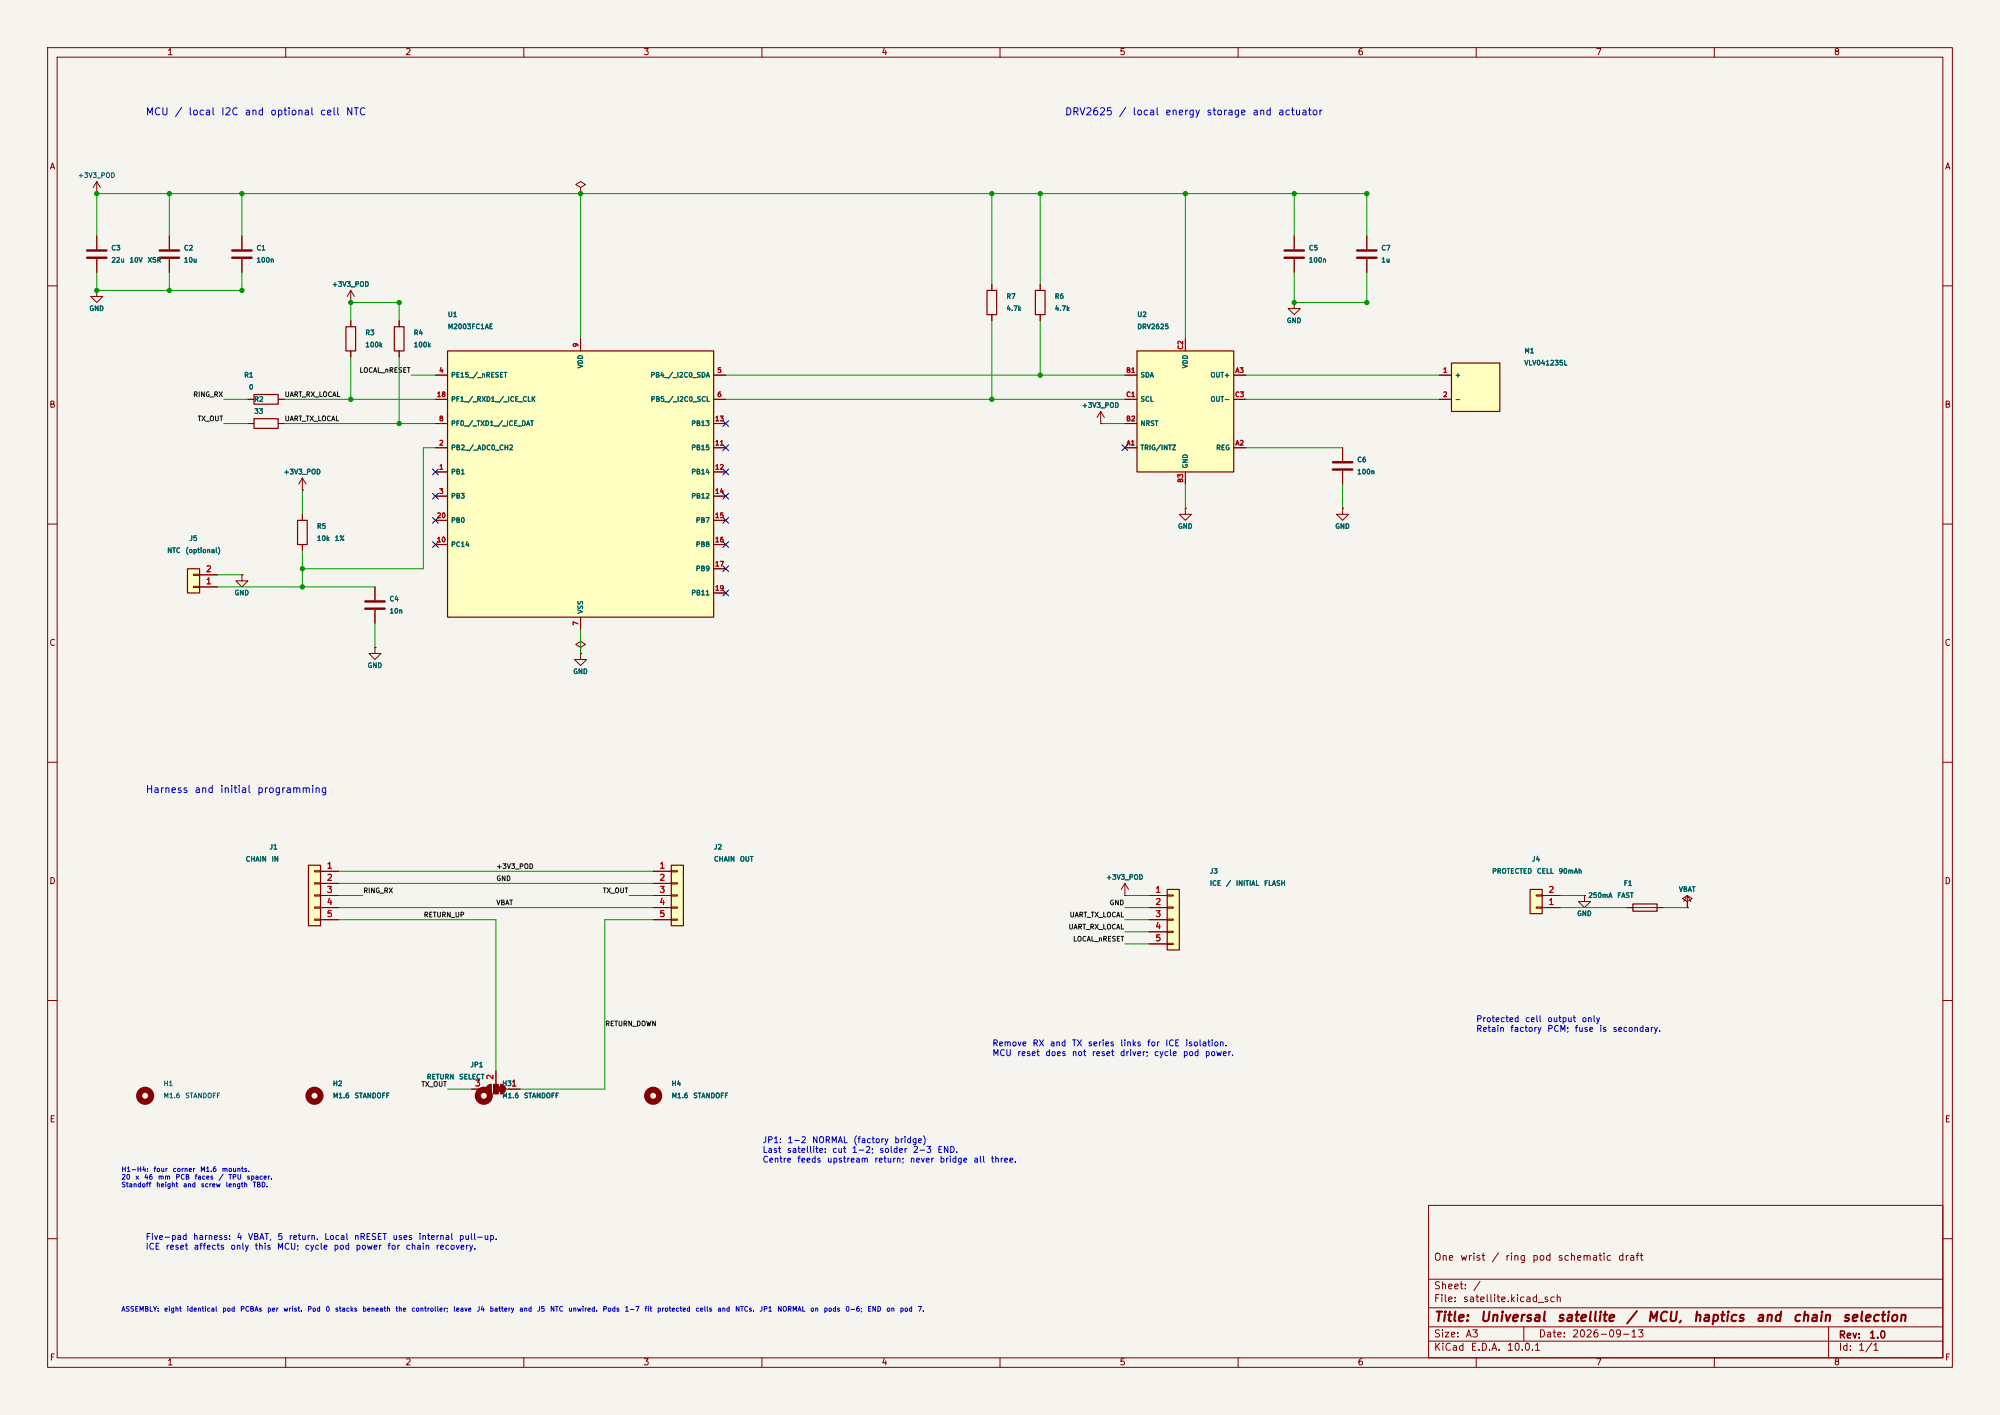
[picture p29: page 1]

MCU / local I2C and optional cell NTC

DRV2625 / local energy storage and actuator

LOCAL_nRESET Harness and initial programming

Protected cell output only Retain factory PCM; fuse is secondary. Remove RX and TX series links for ICE isolation. MCU reset does not reset driver; cycle pod power.

JP1: 1-2 NORMAL (factory bridge) Last satellite: cut 1-2; solder 2-3 END. Centre feeds upstream return; never bridge all three.

ICE reset affects only this MCU; cycle pod power for chain recovery. ASSEMBLY: eight identical pod PCBAs per wrist. Pod 0 stacks beneath the controller; leave J4 battery and J5 NTC unwired. Pods 1-7 fit protected cells and NTCs. JP1 NORMAL on pods 0-6; END on pod 7. H1-H4: four corner M1.6 mounts. 20 x 46 mm PCB faces / TPU spacer. Standoff height and screw length TBD.

Five-pad harness: 4 VBAT, 5 return. Local nRESET uses internal pull-up.

One wrist / ring pod schematic draft

Sheet: /
File: satellite.kicad_sch
Title: Universal satellite / MCU, haptics and chain selection

Size: A3 | Rev: 1.0 | F Date: 2026-09-13
KiCad E.D.A. 10.0.1 | Id: 1/1

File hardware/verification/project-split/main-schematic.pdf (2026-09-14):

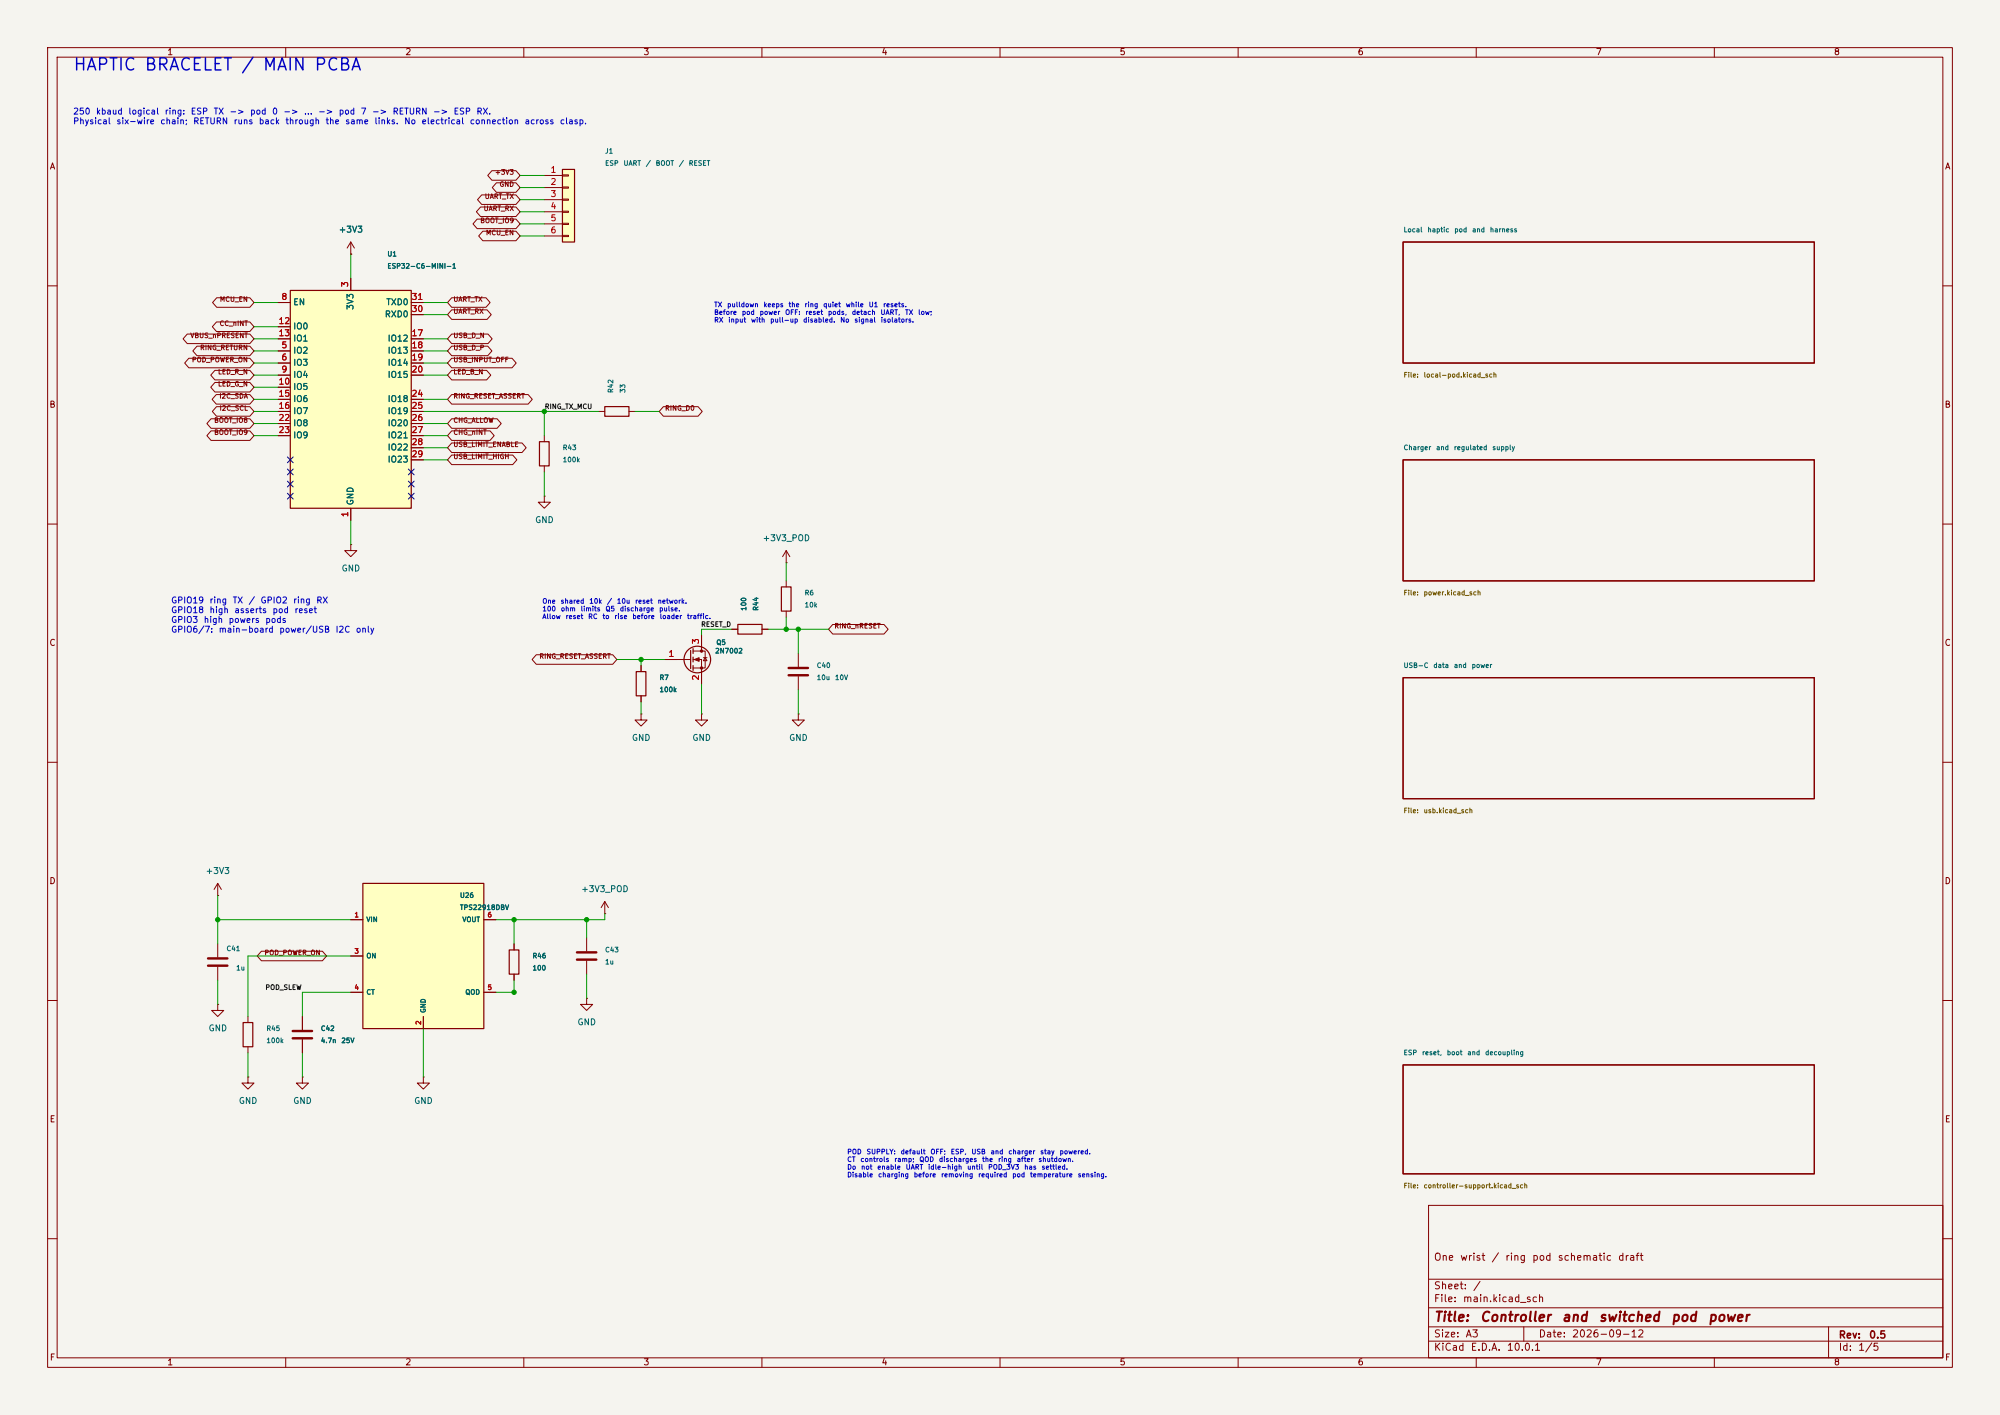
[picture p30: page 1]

ESP UART / BOOT / RESET 1

Local haptic pod and harness File: local-pod.kicad_sch

Charger and regulated supply File: power.kicad_sch

GPIO19 ring TX / GPIO2 ring RX GPIO18 high asserts pod reset GPIO3 high powers pods

USB-C data and power File: usb.kicad_sch

ESP reset, boot and decoupling

POD SUPPLY: default OFF; ESP, USB and charger stay powered. CT controls ramp; QOD discharges the ring after shutdown. Do not enable UART idle-high until POD_3V3 has settled. Disable charging before removing required pod temperature sensing.

One wrist / ring pod schematic draft

Sheet: /
File: main.kicad_sch
Title: Controller and switched pod power

Size: A3 | Rev: 0.5 | F Date: 2026-09-12
KiCad E.D.A. 10.0.1 | Id: 1/5

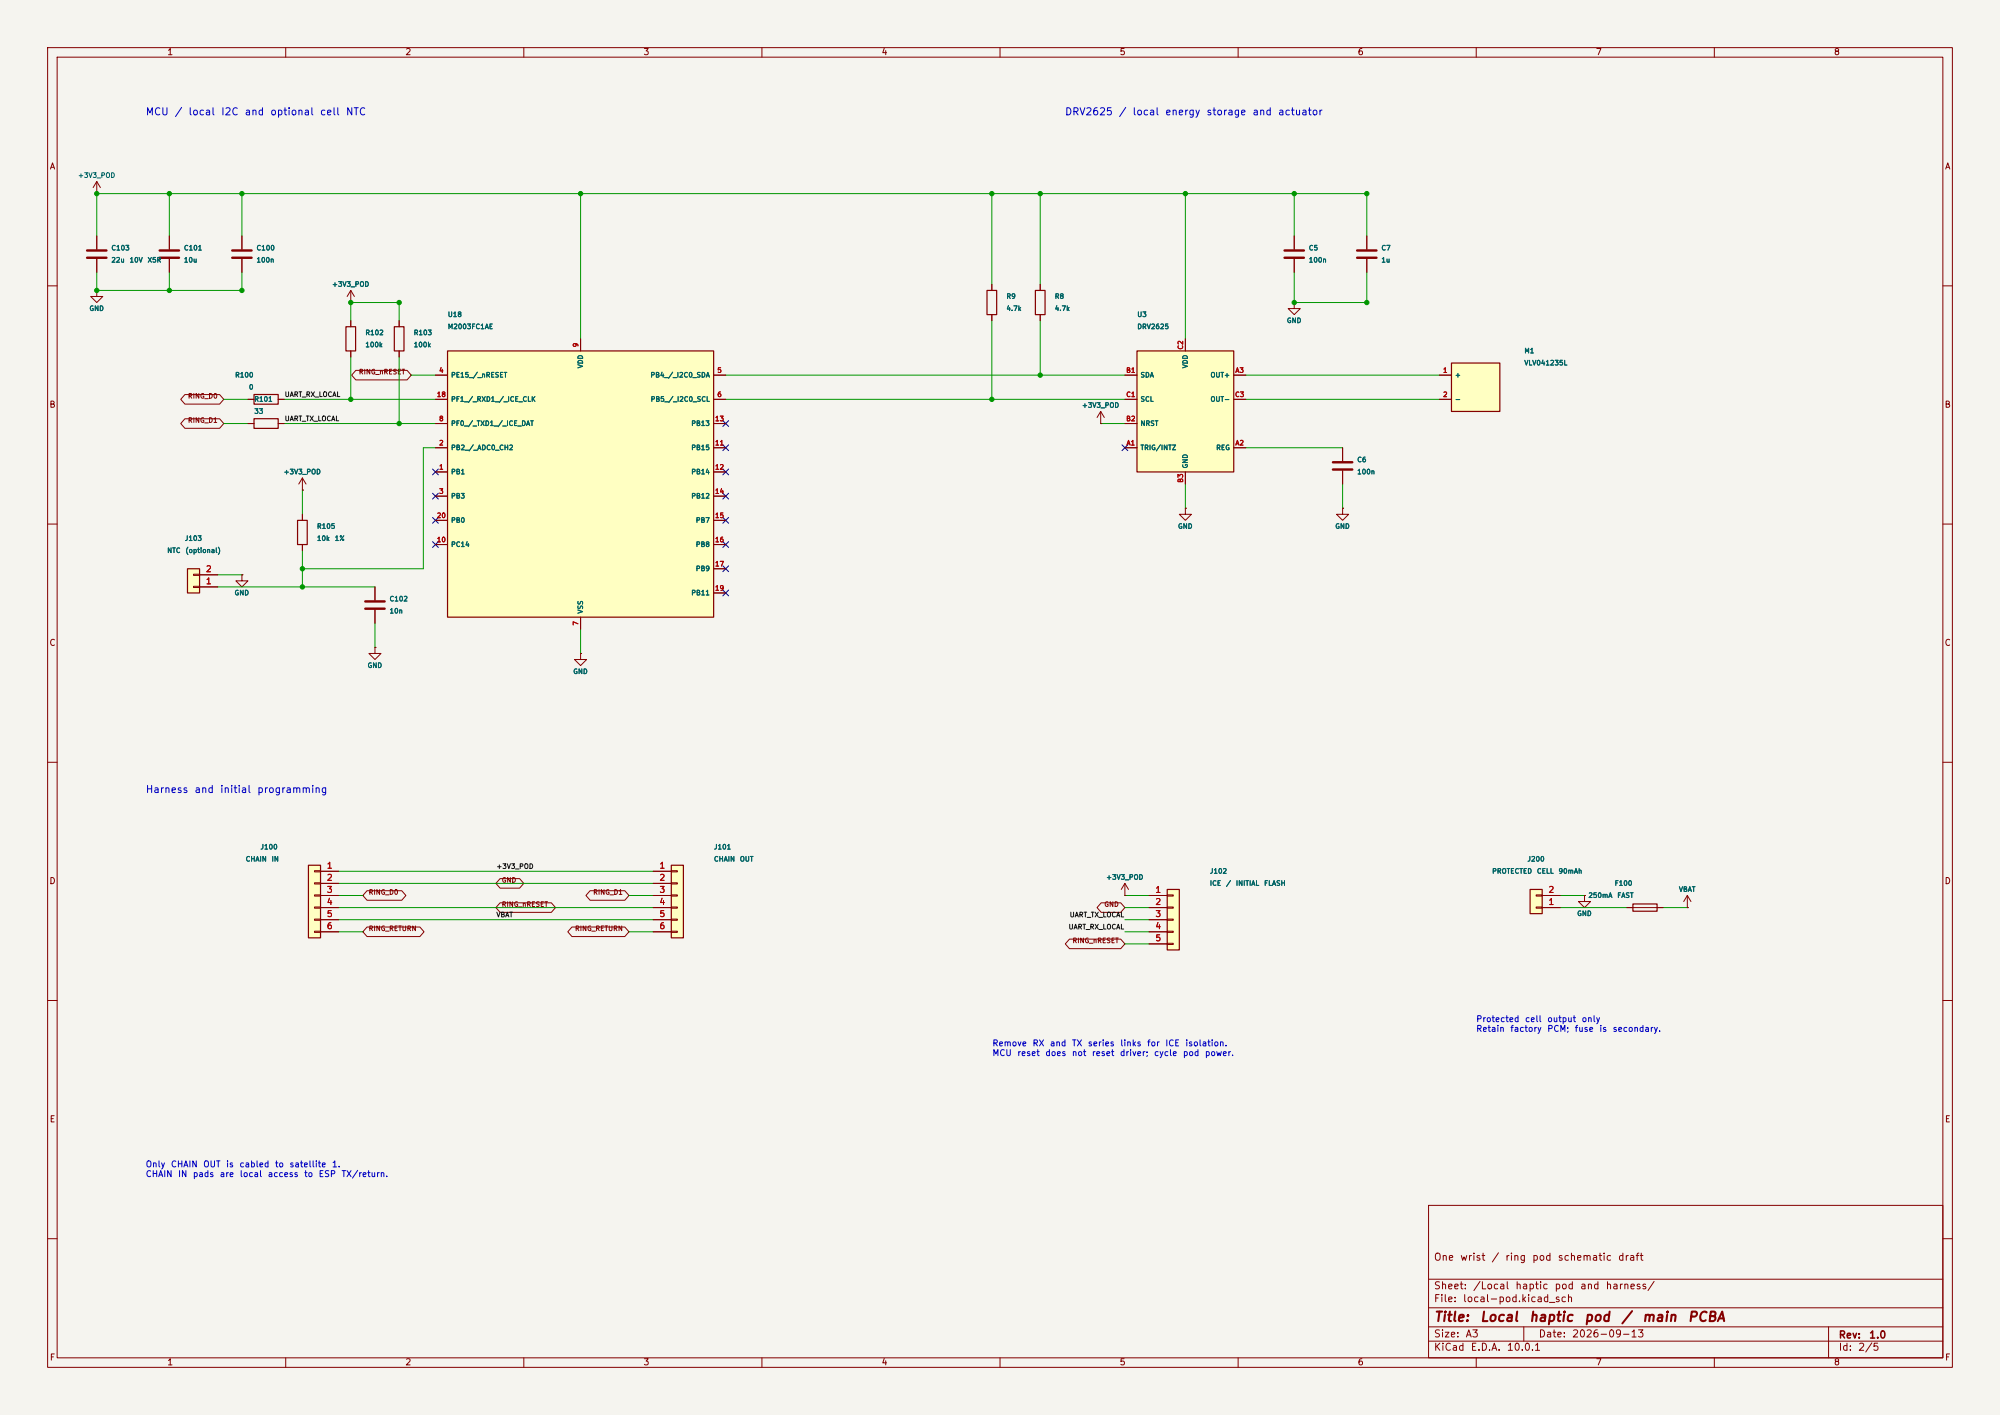
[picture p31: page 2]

One wrist / ring pod schematic draft

Sheet: /Local haptic pod and harness/
File: local-pod.kicad_sch
Title: Local haptic pod / main PCBA

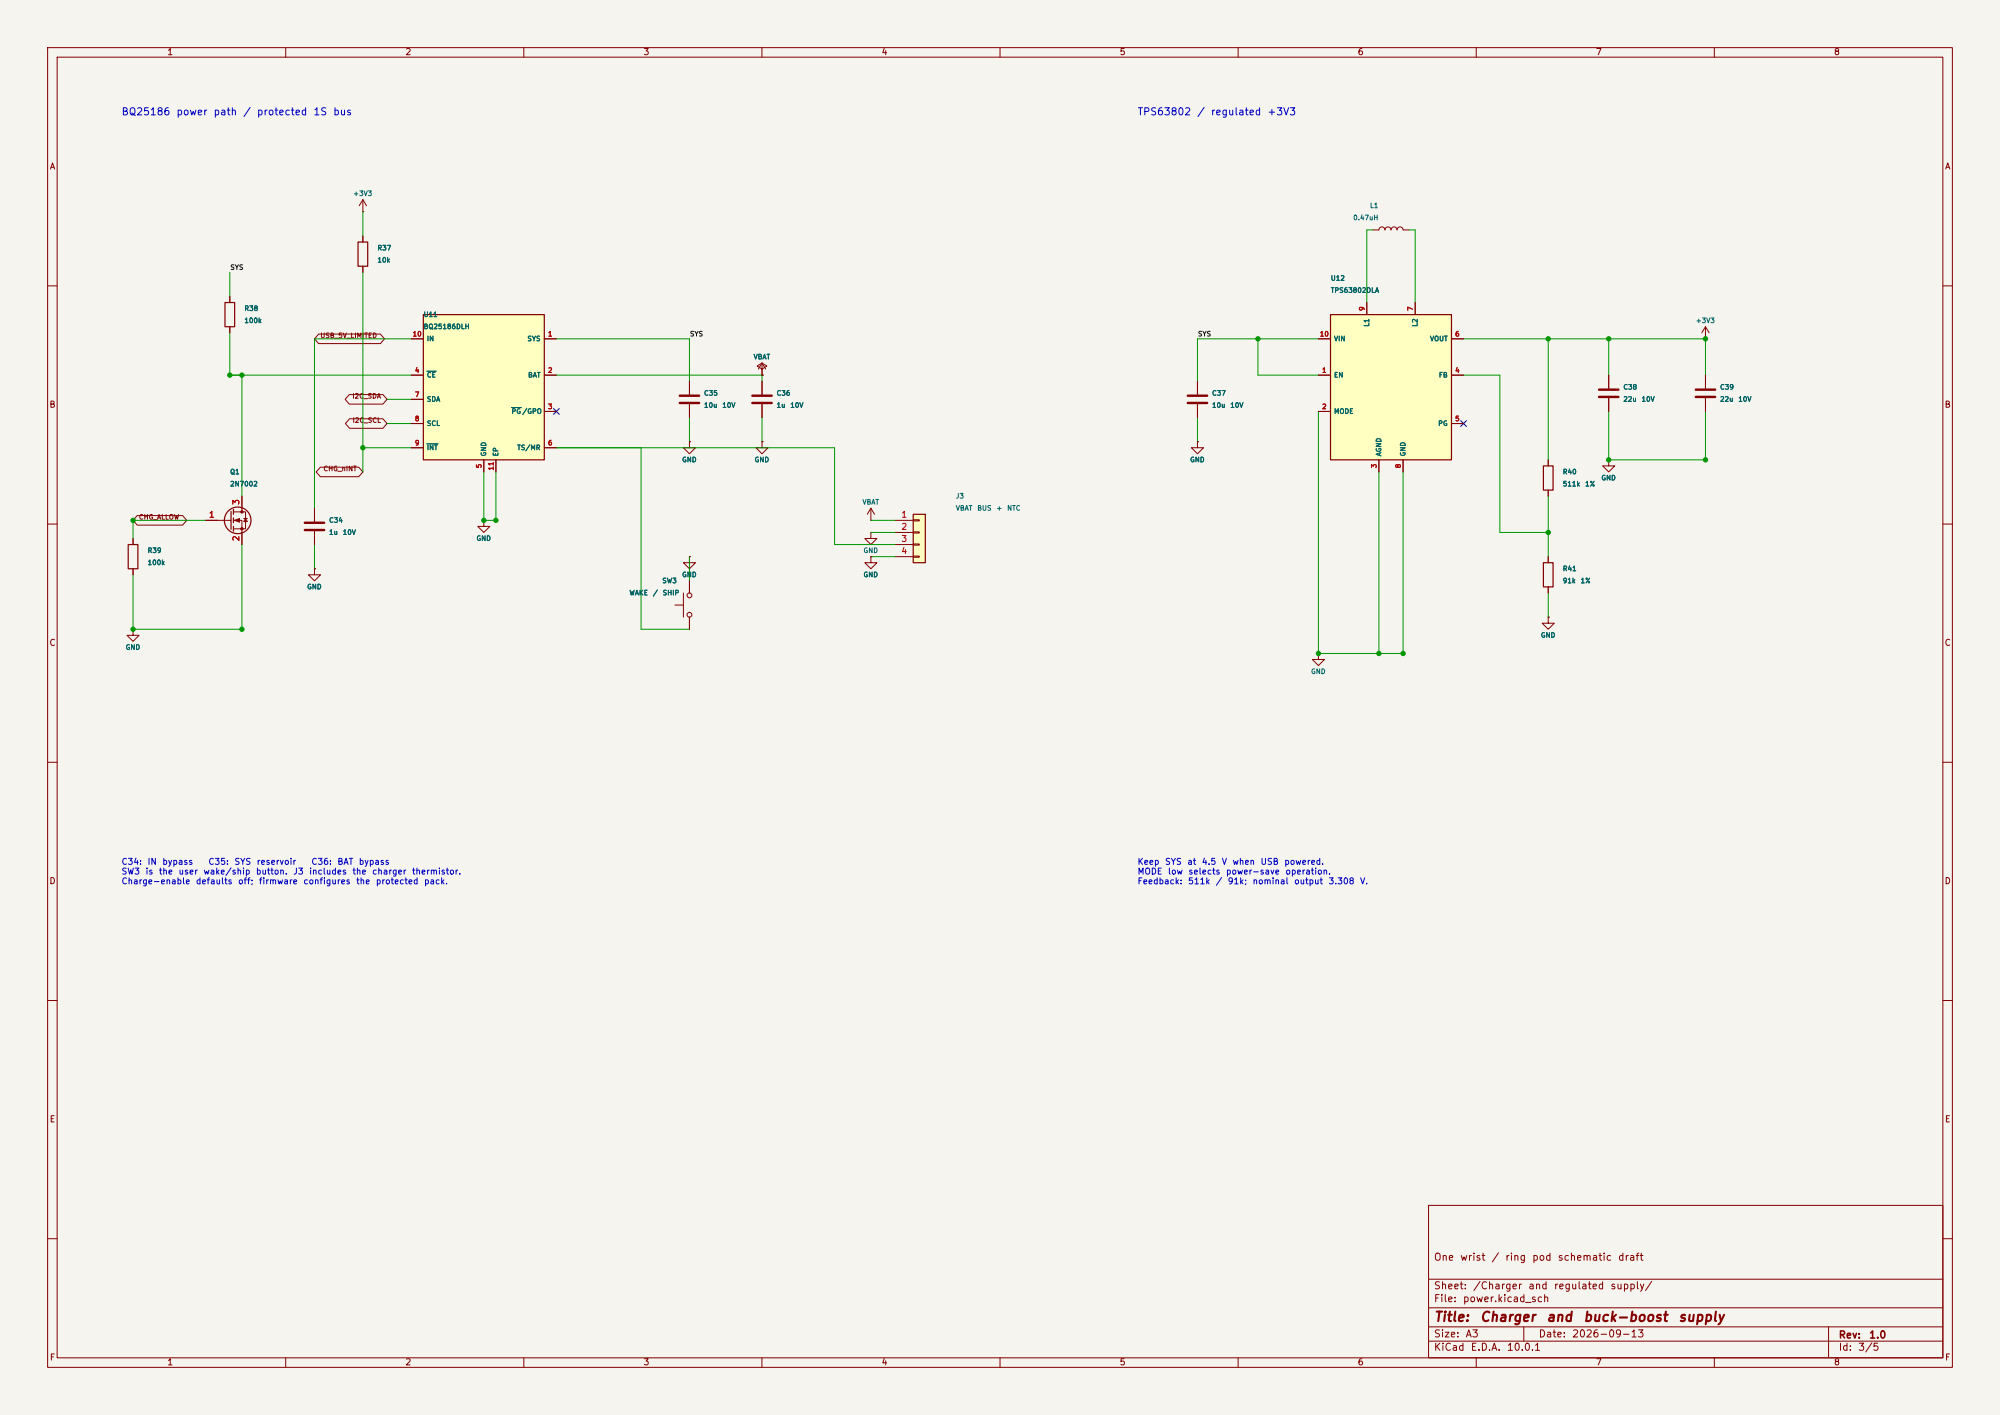
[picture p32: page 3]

One wrist / ring pod schematic draft

Sheet: /Charger and regulated supply/
File: power.kicad_sch
Title: Charger and buck-boost supply

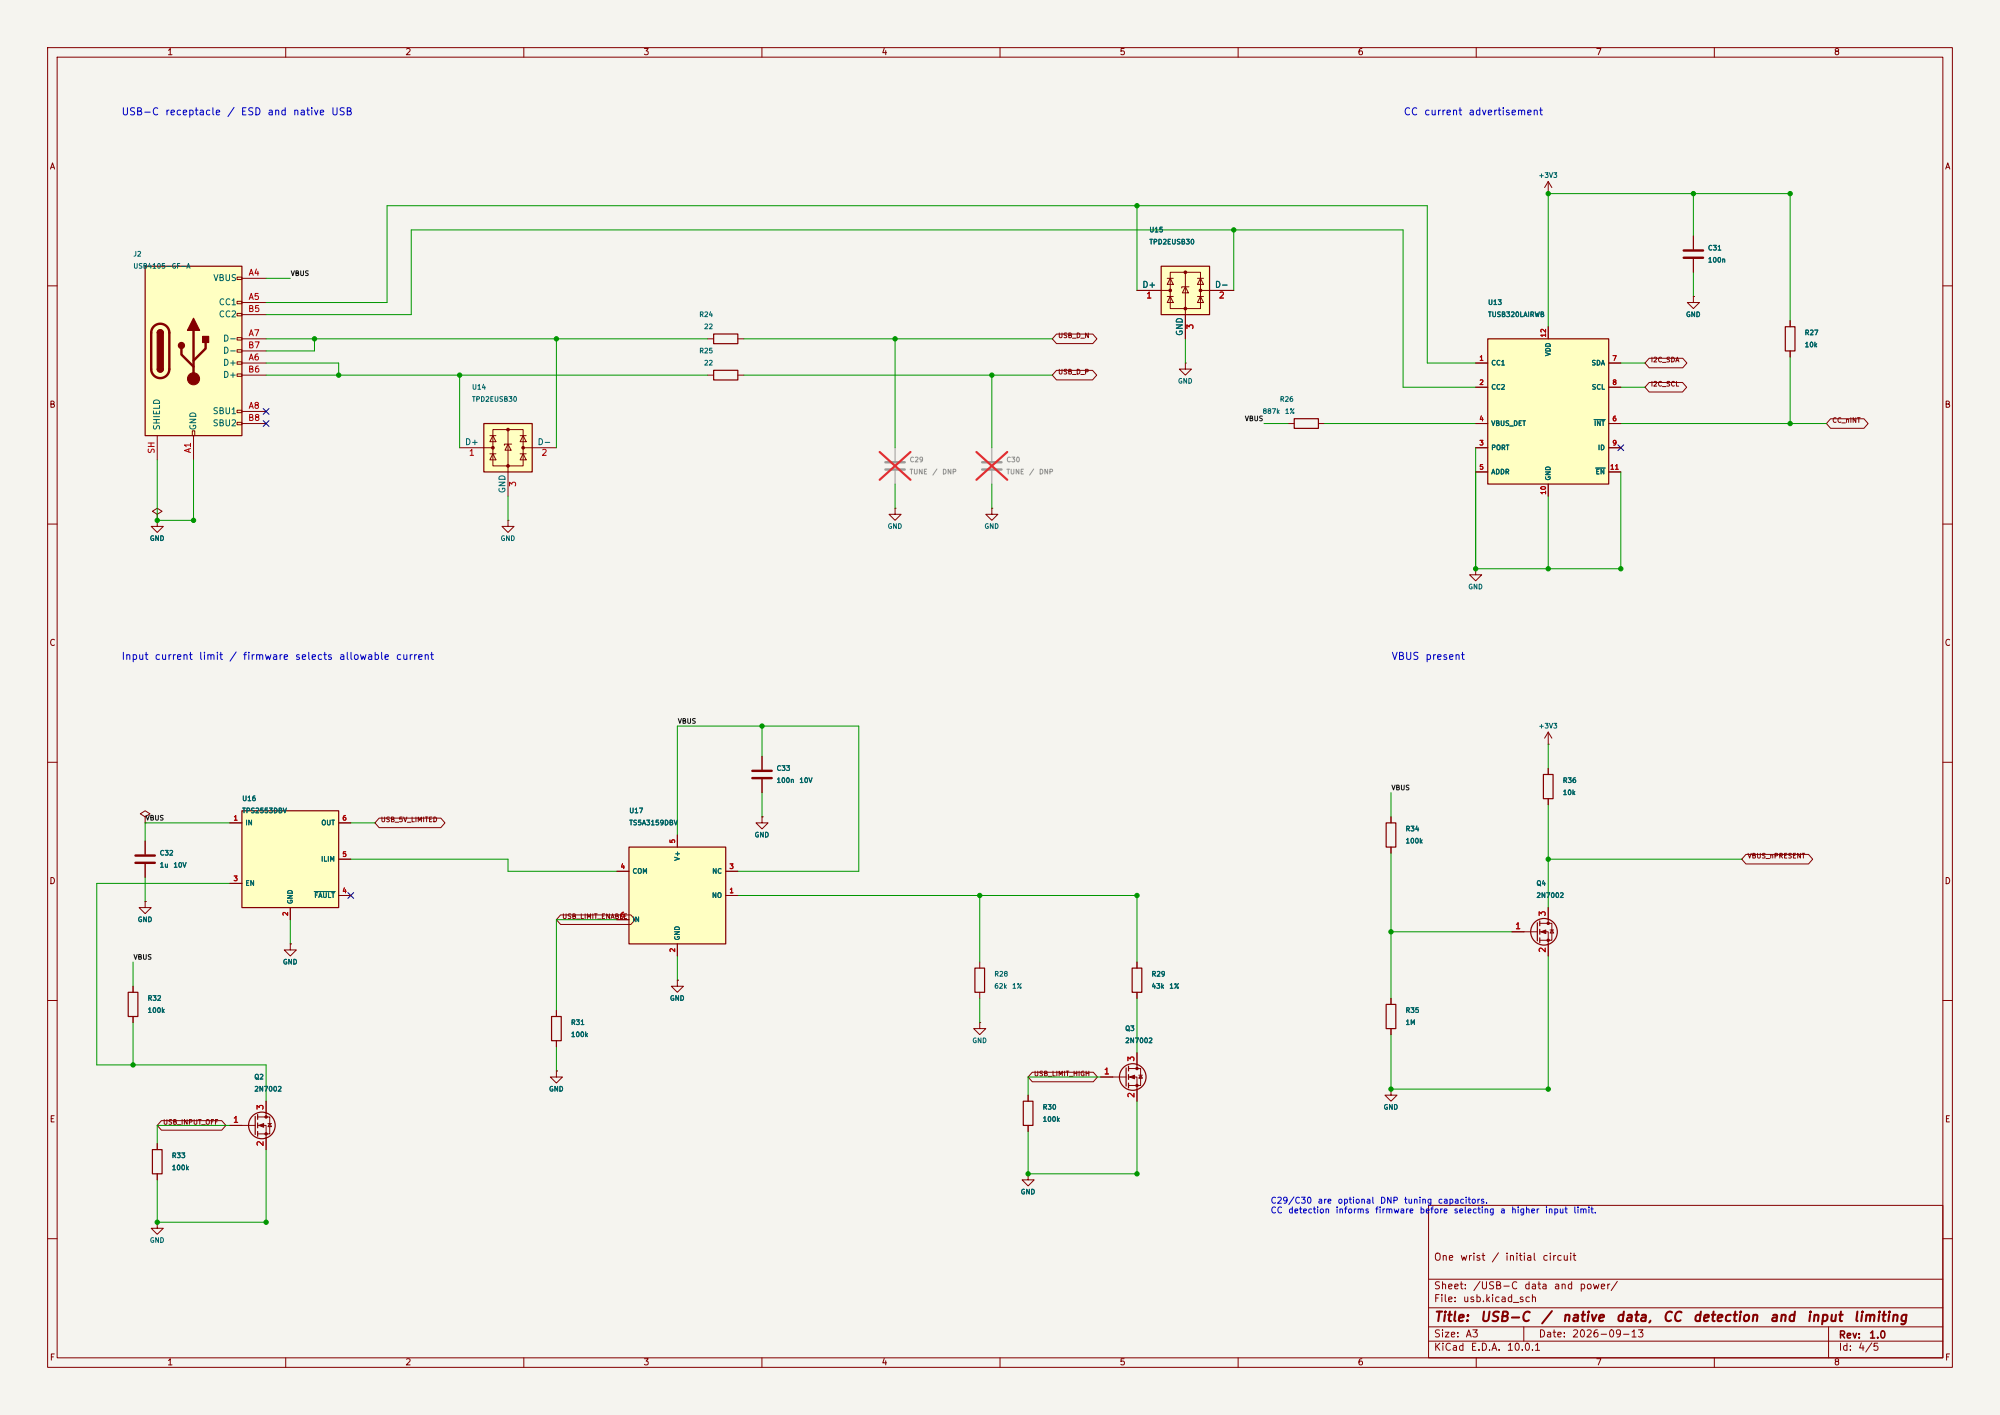
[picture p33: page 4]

C29/C30 are optional DNP tuning capacitors. CC detection informs firmware before selecting a higher input limit.

One wrist / initial circuit

Sheet: /USB-C data and power/
File: usb.kicad_sch
Title: USB-C / native data, CC detection and input limiting

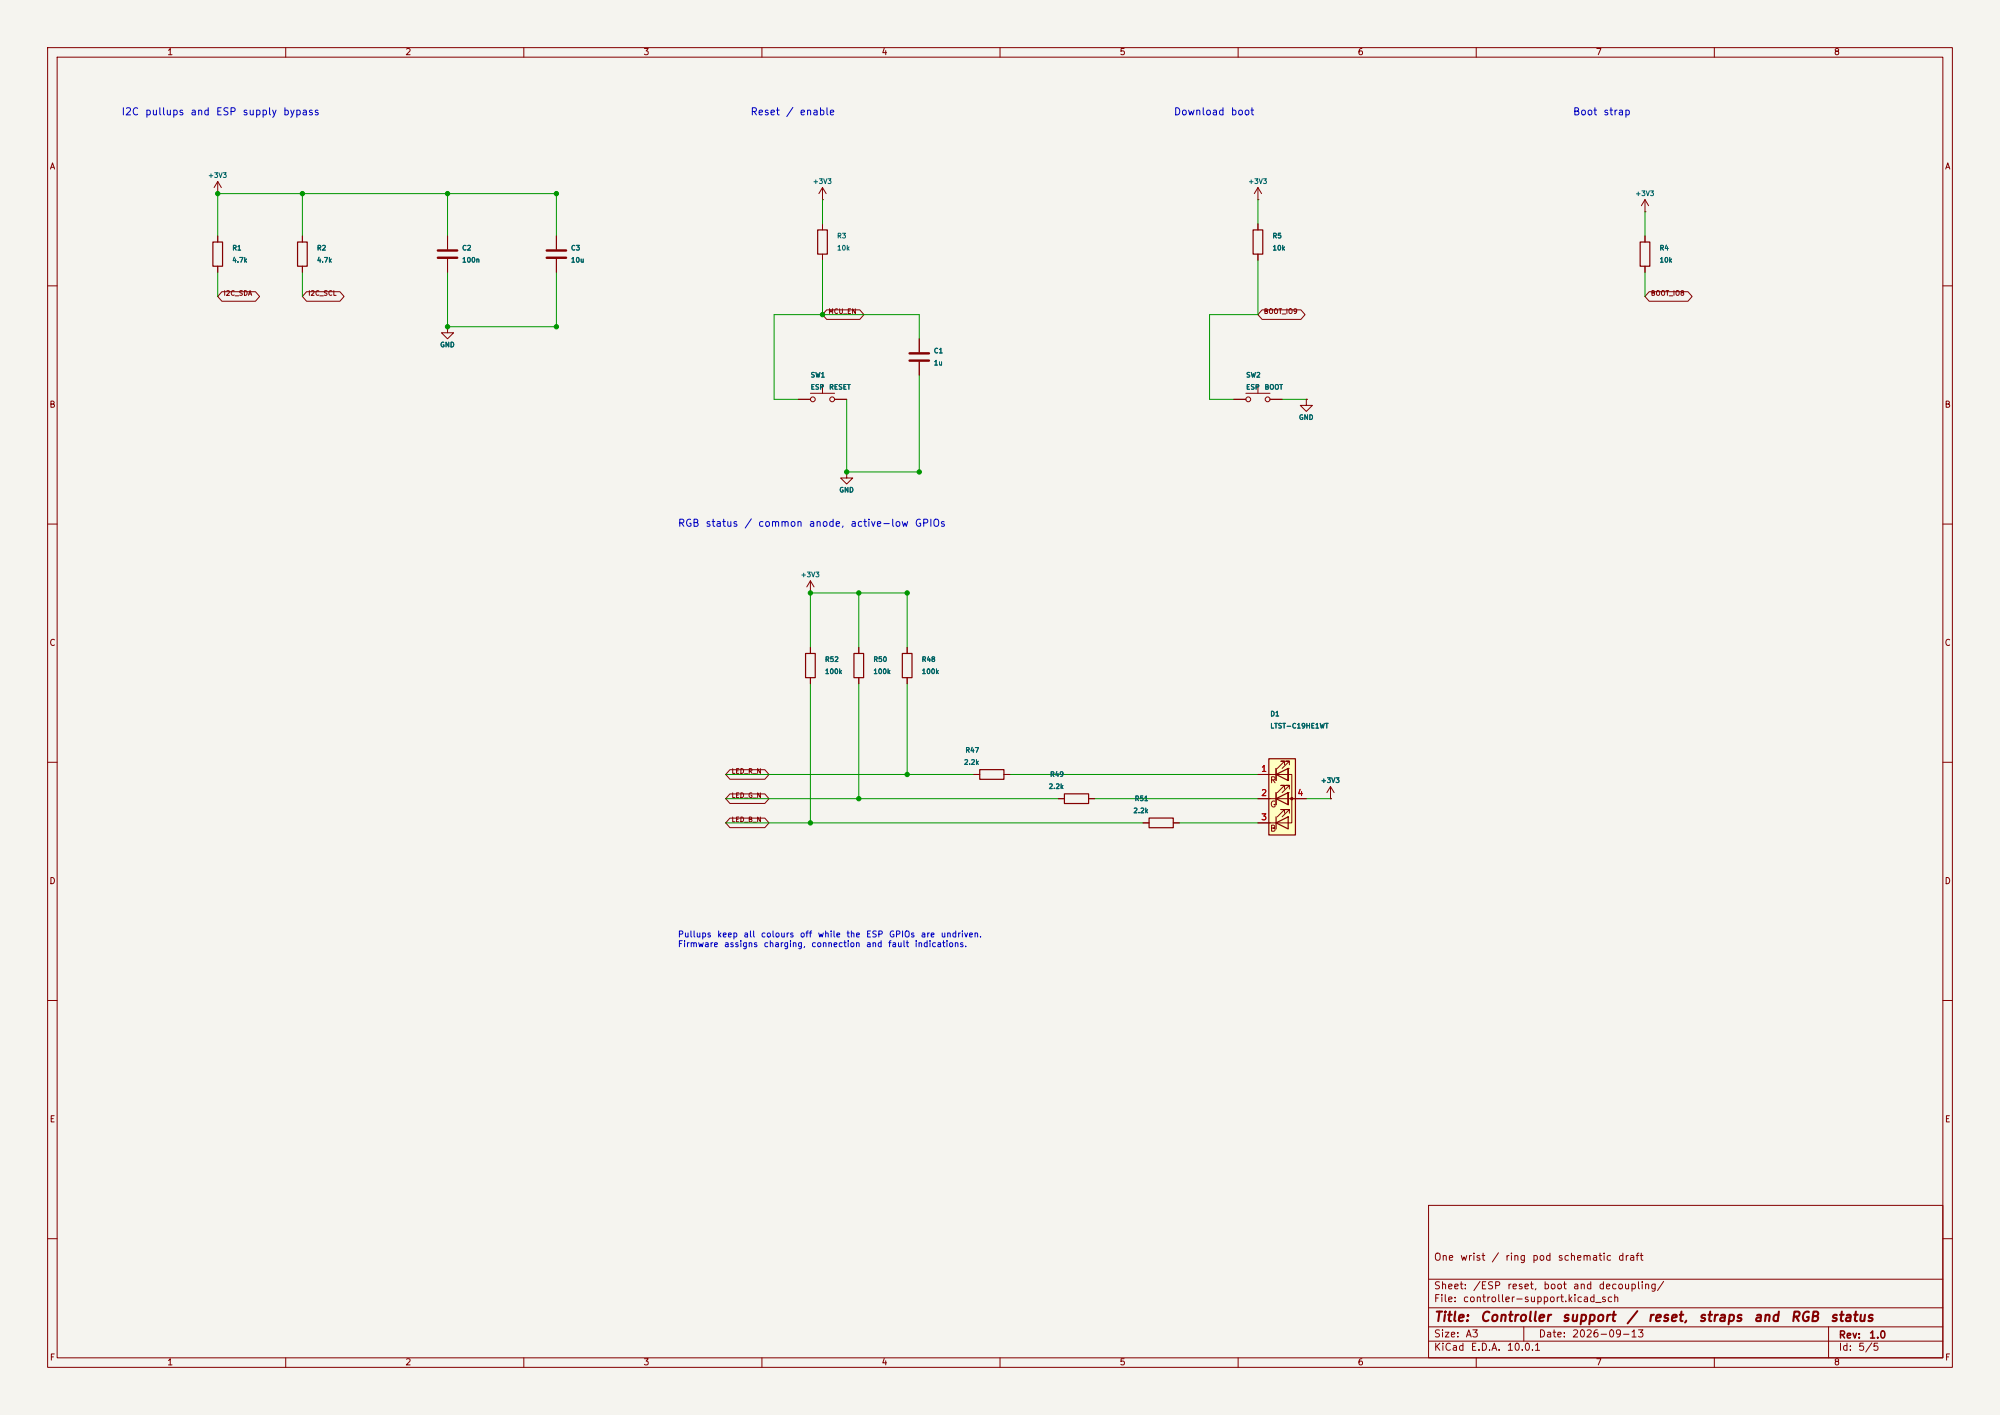
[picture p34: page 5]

I2C pullups and ESP supply bypass

RGB status / common anode, active-low GPIOs

Pullups keep all colours off while the ESP GPIOs are undriven. Firmware assigns charging, connection and fault indications.

One wrist / ring pod schematic draft

Sheet: /ESP reset, boot and decoupling/
File: controller-support.kicad_sch
Title: Controller support / reset, straps and RGB status

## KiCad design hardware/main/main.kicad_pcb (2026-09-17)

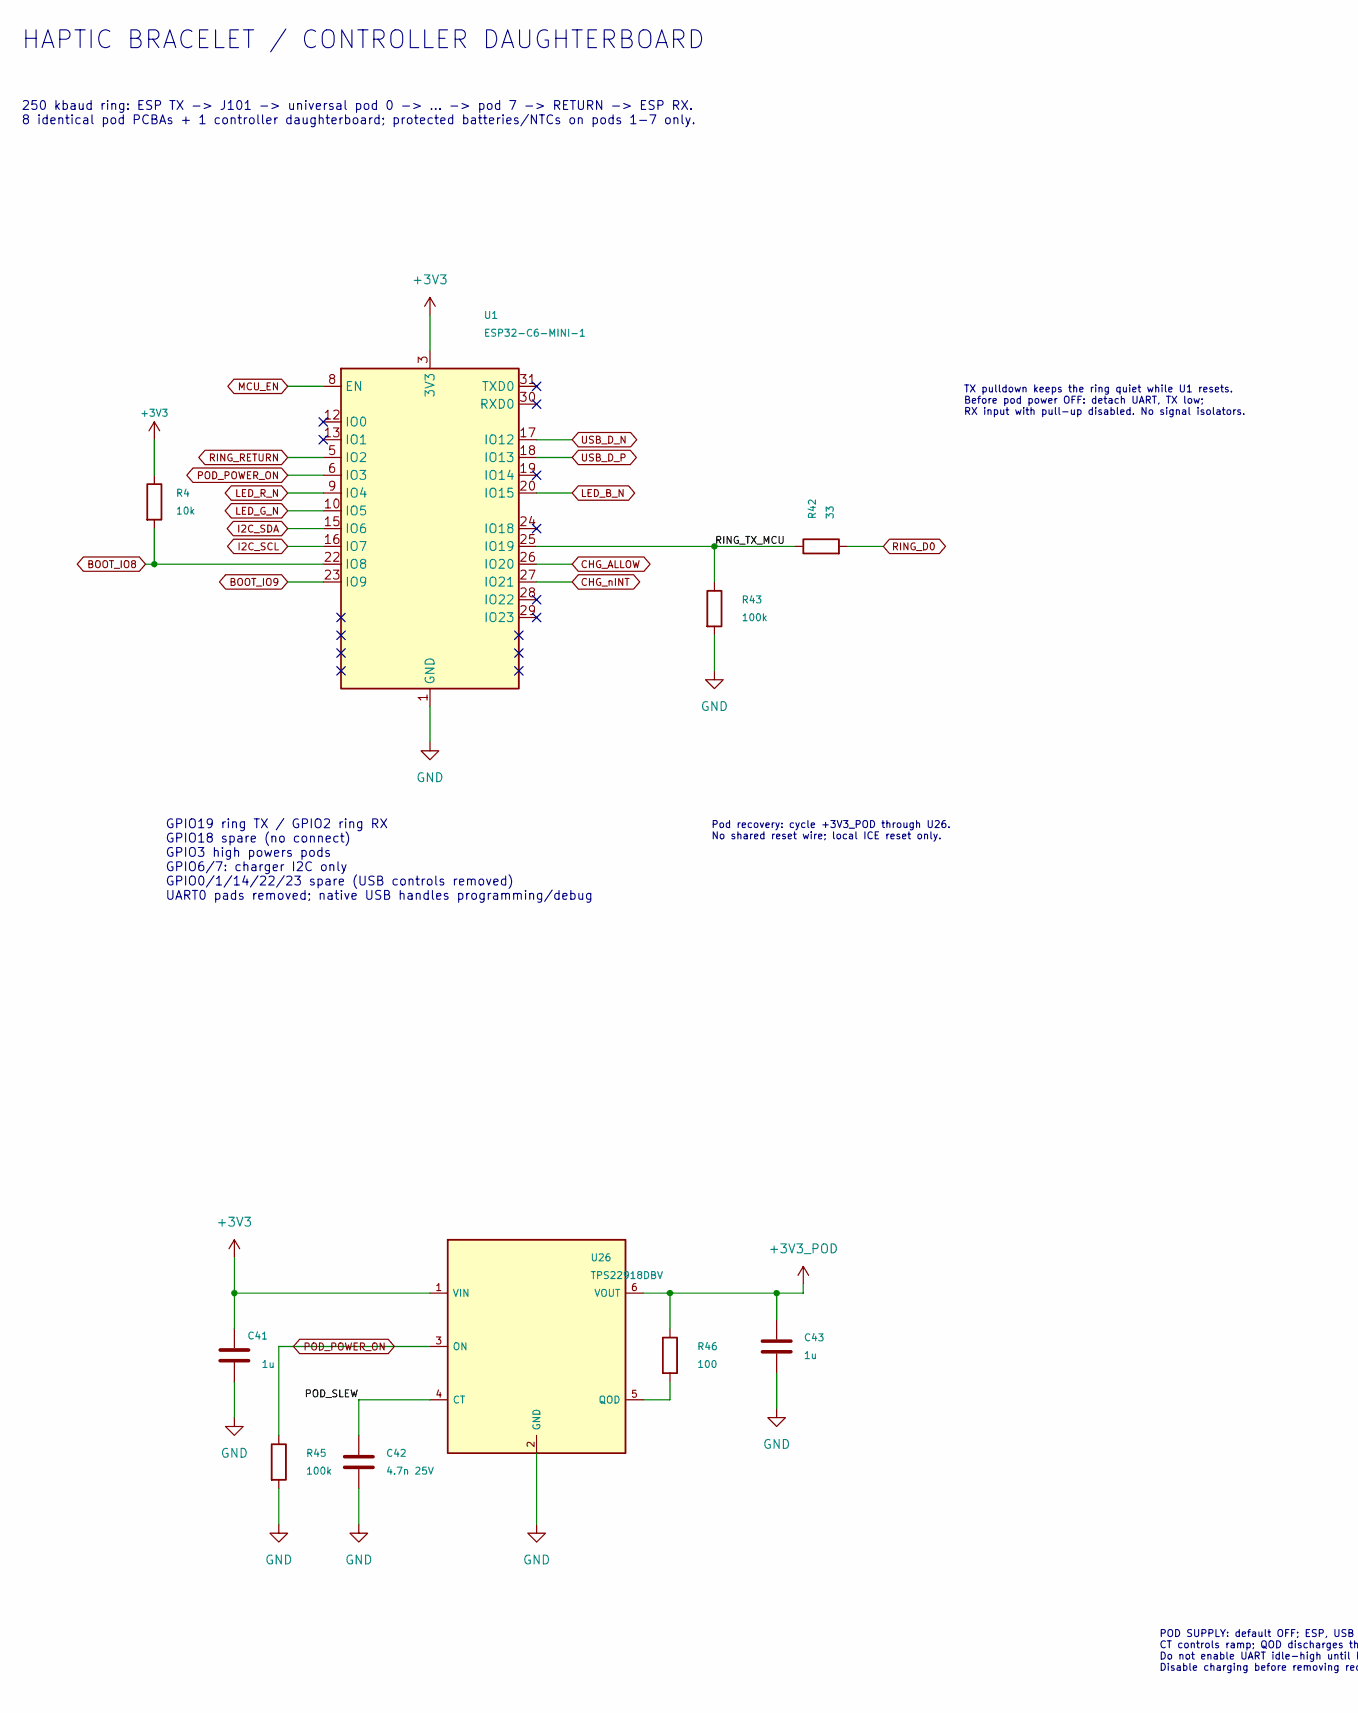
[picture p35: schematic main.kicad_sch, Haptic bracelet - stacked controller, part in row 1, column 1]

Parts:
C41, C43: 1u; C_0402_1005Metric
C42: 4.7n 25V; C_0402_1005Metric
R4: 10k; R_0402_1005Metric
R42: 33; R_0402_1005Metric
R43, R45: 100k; R_0402_1005Metric
R46: 100; R_0402_1005Metric
U1: ESP32-C6-MINI-1
U26: TPS22918DBV; SOT-23-6; MPN TPS22918DBVR

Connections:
+3V3: C41.1, R4.1, U1.3 (3V3), U26.1 (VIN); also elsewhere on the board
+3V3_POD: C43.1, R46.1, U26.6 (VOUT); also elsewhere on the board
/POD_SLEW: C42.1, U26.4 (CT)
/RING_TX_MCU: R42.1, R43.1, U1.25 (IO19)
BOOT_IO8: R4.2, U1.22 (IO8)
BOOT_IO9: U1.23 (IO9); also elsewhere on the board
CHG_ALLOW: U1.26 (IO20); also elsewhere on the board
CHG_nINT: U1.27 (IO21); also elsewhere on the board
GND: C41.2, C42.2, C43.2, R43.2, R45.2, U1.1 (GND), U1.2 (GND), U1.11 (GND), U1.14 (GND), U1.36 (GND), U1.37 (GND), U1.38 (GND), U1.39 (GND), U1.40 (GND), U1.41 (GND), U1.42 (GND), U1.43 (GND), U1.44 (GND), U1.45 (GND), U1.46 (GND), U1.47 (GND), U1.48 (GND), U1.49 (GND), U1.50 (GND), U1.51 (GND), U1.52 (GND), U1.53 (GND), U26.2 (GND); also elsewhere on the board
I2C_SCL: U1.16 (IO7); also elsewhere on the board
I2C_SDA: U1.15 (IO6); also elsewhere on the board
LED_B_N: U1.20 (IO15); also elsewhere on the board
LED_G_N: U1.10 (IO5); also elsewhere on the board
LED_R_N: U1.9 (IO4); also elsewhere on the board
MCU_EN: U1.8 (EN); also elsewhere on the board
unnamed: R46.2, U26.5 (QOD)
POD_POWER_ON: R45.1, U1.6 (IO3), U26.3 (ON)
RING_D0: R42.2; also elsewhere on the board
RING_RETURN: U1.5 (IO2); also elsewhere on the board
USB_D_N: U1.17 (IO12); also elsewhere on the board
USB_D_P: U1.18 (IO13); also elsewhere on the board

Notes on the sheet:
Pod recovery: cycle +3V3_POD through U26. No shared reset wire; local ICE reset only.
250 kbaud ring: ESP TX -> J101 -> universal pod 0 -> ... -> pod 7 -> RETURN -> ESP RX. 8 identical pod PCBAs + 1 controller daughterboard; protected batteries/NTCs on pods 1-7 only.
TX pulldown keeps the ring quiet while U1 resets. Before pod power OFF: detach UART, TX low; RX input with pull-up disabled. No signal isolators.
GPIO19 ring TX / GPIO2 ring RX GPIO18 spare (no connect) GPIO3 high powers pods GPIO6/7: charger I2C only GPIO0/1/14/22/23 spare (USB controls removed) UART0 pads removed; native USB handles programming/debug
POD SUPPLY: default OFF; ESP, USB and charger stay powered. CT controls ramp; QOD discharges the ring after shutdown. Do not enable UART idle-high until POD_3V3 has settled. Disable charging before removing required pod temperature sensing.
HAPTIC BRACELET / CONTROLLER DAUGHTERBOARD

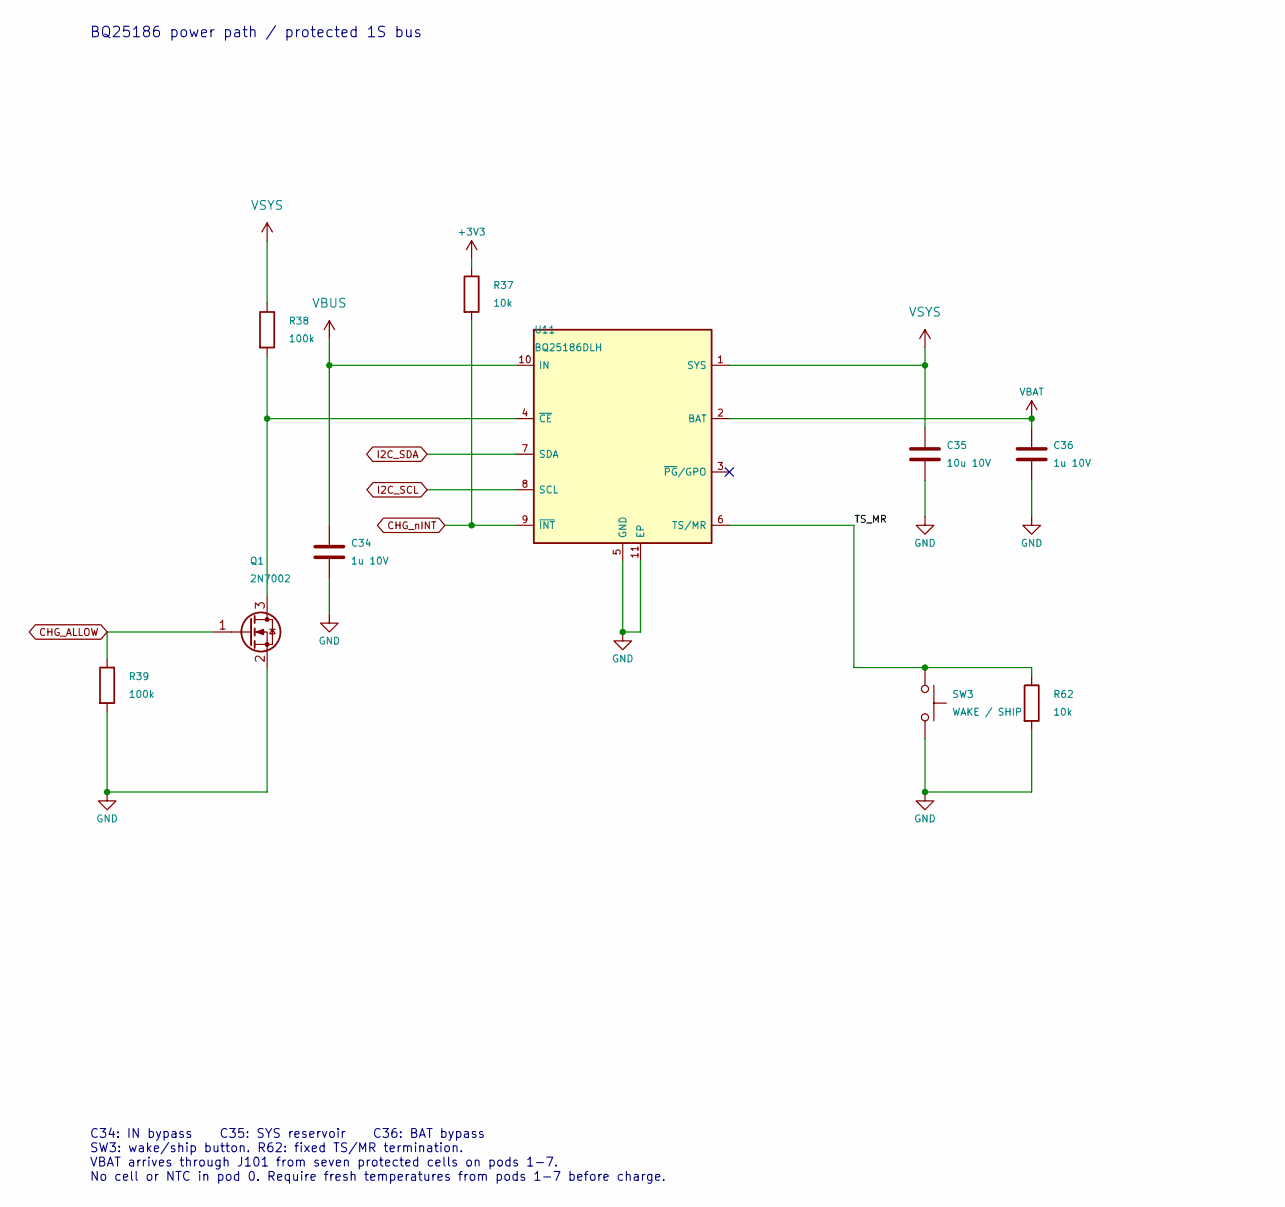
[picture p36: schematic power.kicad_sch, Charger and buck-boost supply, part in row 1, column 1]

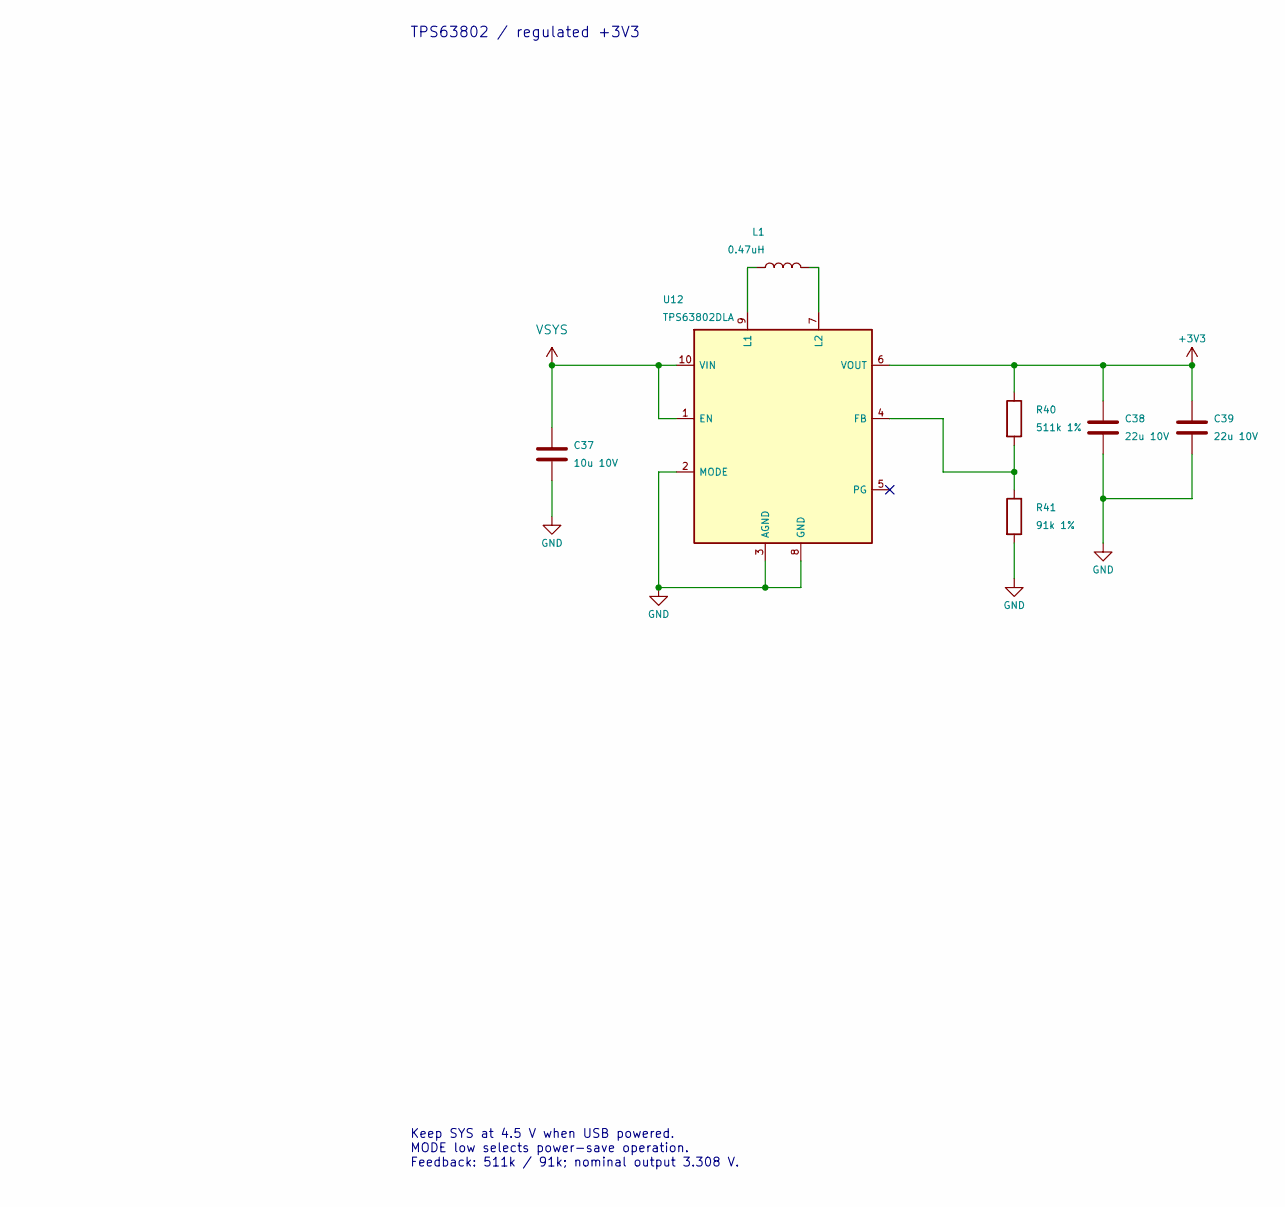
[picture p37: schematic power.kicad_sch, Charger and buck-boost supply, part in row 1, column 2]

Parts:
C34, C36: 1u 10V; C_0603_1608Metric
C35, C37: 10u 10V; C_0805_2012Metric
C38, C39: 22u 10V; C_0805_2012Metric
L1: 0.47uH; L_Murata_DFE201612E; MPN DFE201612E-R47M=P2
Q1: 2N7002; SOT-323_SC-70
R37, R62: 10k; R_0402_1005Metric
R38, R39: 100k; R_0402_1005Metric
R40: 511k 1%; R_0402_1005Metric
R41: 91k 1%; R_0402_1005Metric
SW3: WAKE / SHIP; SW_SPST_Panasonic_EVPAW_3x2mm_H0.6mm; MPN EVPAWBD4A
U11: BQ25186DLH; Texas_DLH0010A_WSON-10-1EP_2.2x2mm_P0.4mm_EP0.9x1.5mm; MPN BQ25186DLHR
U12: TPS63802DLA; TPS63802_DLA0010A; MPN TPS63802DLAR

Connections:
+3V3: C38.1, C39.1, R37.1, R40.1, U12.6 (VOUT); also elsewhere on the board
/Charger and regulated supply/TS_MR: R62.1, SW3.1, U11.6 (TS/MR)
CHG_ALLOW: Q1.1 (G), R39.1; also elsewhere on the board
CHG_nINT: R37.2, U11.9 (~INT); also elsewhere on the board
GND: C34.2, C35.2, C36.2, C37.2, C38.2, C39.2, Q1.2 (S), R39.2, R41.2, R62.2, SW3.2, U11.5 (GND), U11.11 (EP), U12.2 (MODE), U12.3 (AGND), U12.8 (GND); also elsewhere on the board
I2C_SCL: U11.8 (SCL); also elsewhere on the board
I2C_SDA: U11.7 (SDA); also elsewhere on the board
unnamed: Q1.3 (D), R38.2, U11.4 (~CE)
unnamed: R40.2, R41.1, U12.4 (FB)
unnamed: L1.1, U12.9 (L1)
unnamed: L1.2, U12.7 (L2)
VBAT: C36.1, U11.2 (BAT); also elsewhere on the board
VBUS: C34.1, U11.10 (IN); also elsewhere on the board
VSYS: C35.1, C37.1, R38.1, U11.1 (SYS), U12.1 (EN), U12.10 (VIN)

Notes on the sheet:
TPS63802 / regulated +3V3
Keep SYS at 4.5 V when USB powered. MODE low selects power-save operation. Feedback: 511k / 91k; nominal output 3.308 V.
C34: IN bypass C35: SYS reservoir C36: BAT bypass SW3: wake/ship button. R62: fixed TS/MR termination. VBAT arrives through J101 from seven protected cells on pods 1-7. No cell or NTC in pod 0. Require fresh temperatures from pods 1-7 before charge.
BQ25186 power path / protected 1S bus

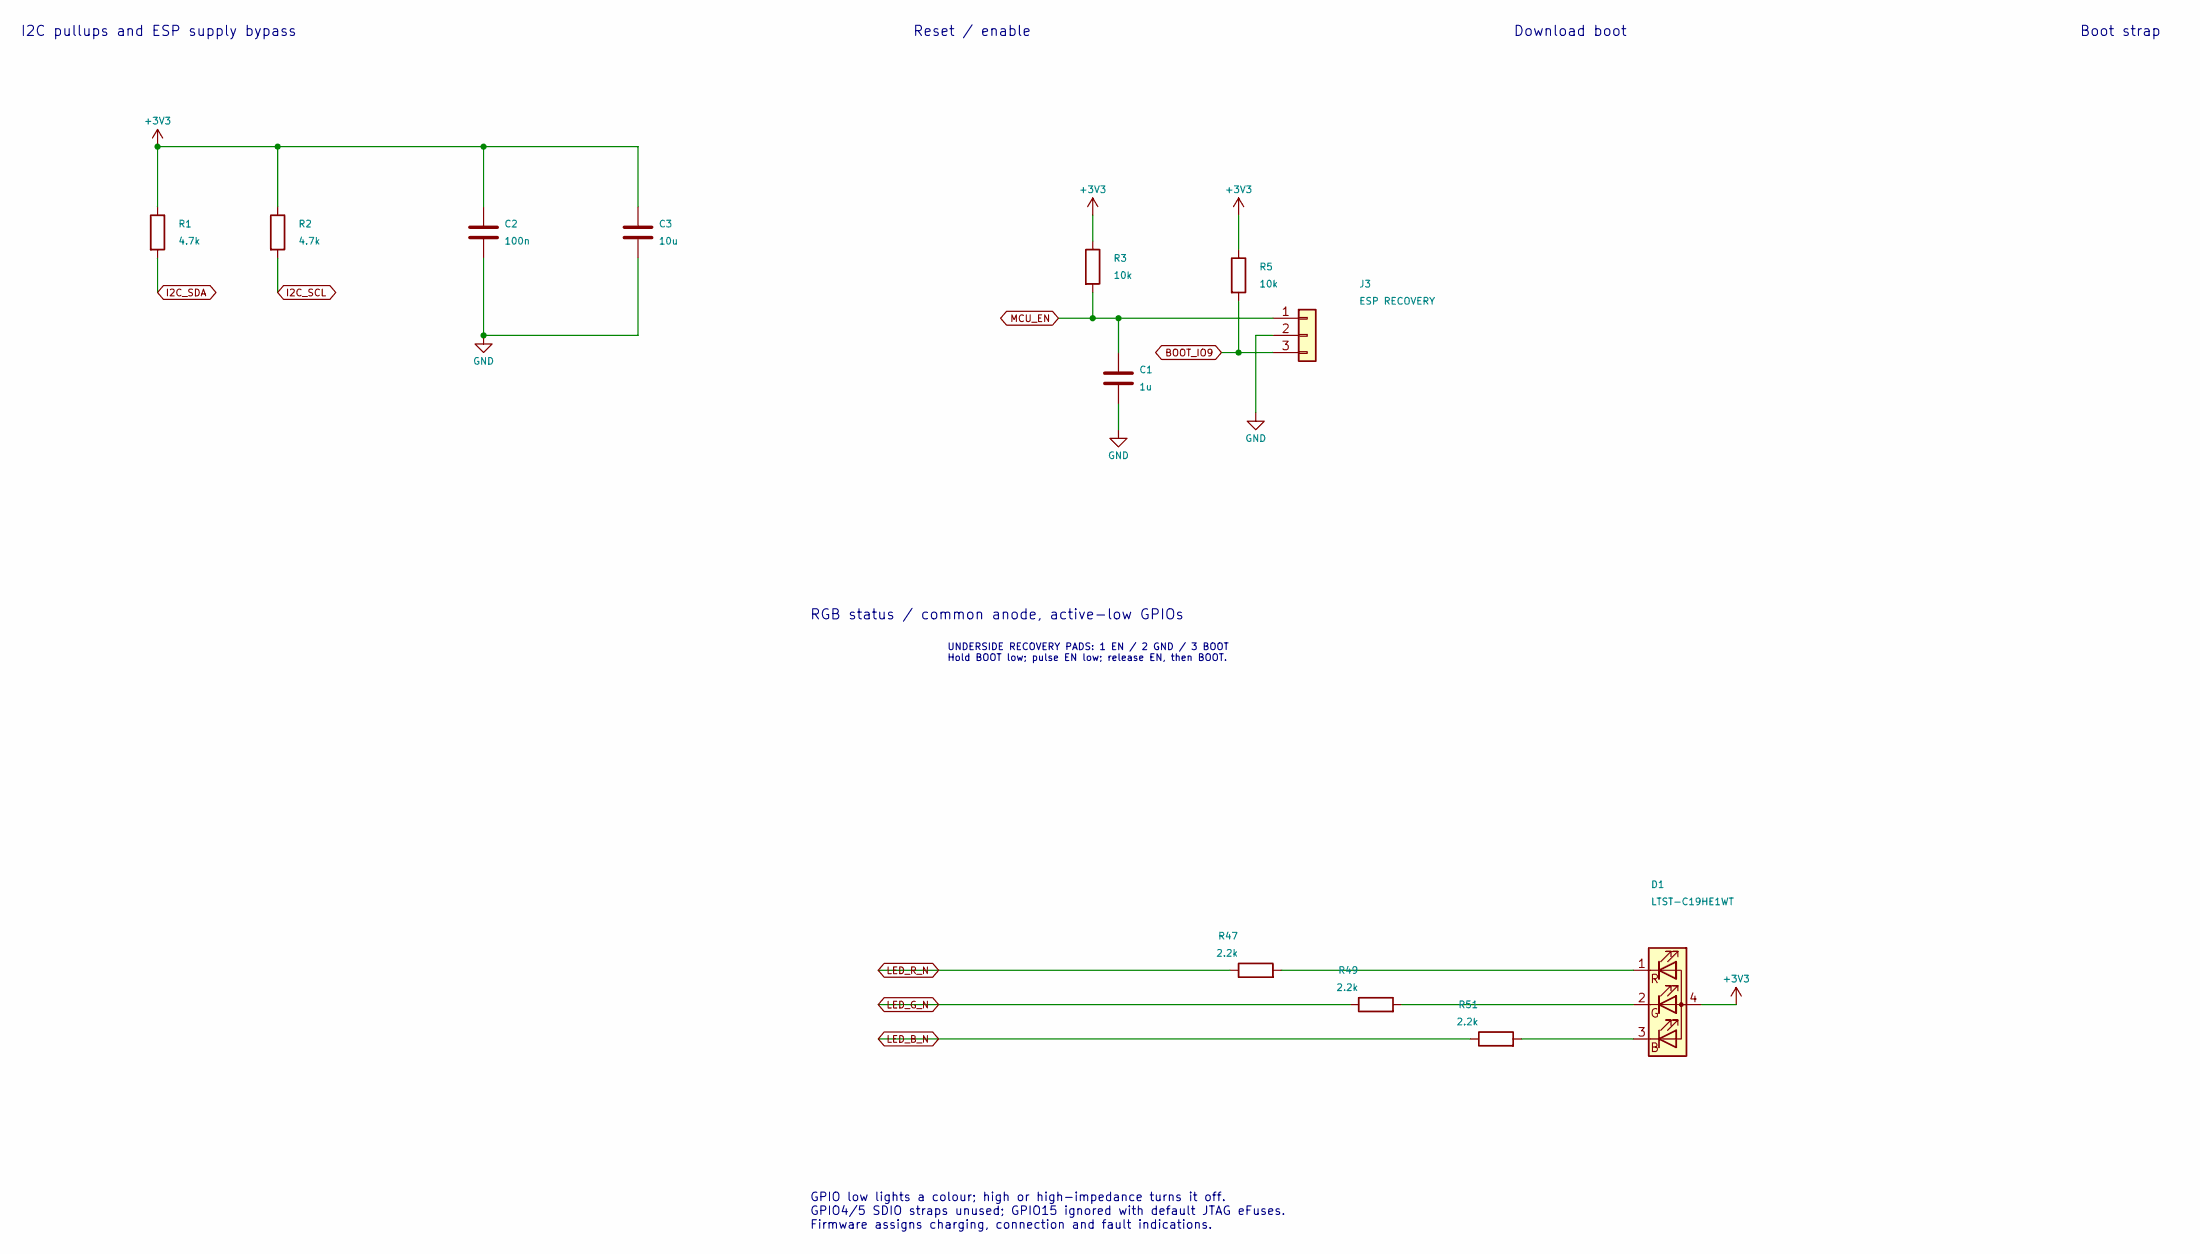
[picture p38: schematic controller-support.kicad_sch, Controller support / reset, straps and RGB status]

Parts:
C1: 1u; C_0402_1005Metric
C2: 100n; C_0402_1005Metric
C3: 10u; C_0805_2012Metric
D1: LTST-C19HE1WT; LED_LiteOn_LTST-C19HE1WT; MPN LTST-C19HE1WT
J3: ESP RECOVERY; ESP_Recovery_3Pads_P1.5mm
R1, R2: 4.7k; R_0402_1005Metric
R3, R5: 10k; R_0402_1005Metric
R47, R49, R51: 2.2k; R_0402_1005Metric

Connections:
+3V3: C2.1, C3.1, D1.4 (A), R1.1, R2.1, R3.1, R5.1; also elsewhere on the board
BOOT_IO9: J3.3, R5.2; also elsewhere on the board
GND: C1.2, C2.2, C3.2, J3.2; also elsewhere on the board
I2C_SCL: R2.2; also elsewhere on the board
I2C_SDA: R1.2; also elsewhere on the board
LED_B_N: R51.1; also elsewhere on the board
LED_G_N: R49.1; also elsewhere on the board
LED_R_N: R47.1; also elsewhere on the board
MCU_EN: C1.1, J3.1, R3.2; also elsewhere on the board
unnamed: D1.3 (BK), R51.2
unnamed: D1.2 (GK), R49.2
unnamed: D1.1 (RK), R47.2

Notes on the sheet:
RGB status / common anode, active-low GPIOs
I2C pullups and ESP supply bypass
Boot strap
UNDERSIDE RECOVERY PADS: 1 EN / 2 GND / 3 BOOT Hold BOOT low; pulse EN low; release EN, then BOOT.
GPIO low lights a colour; high or high-impedance turns it off. GPIO4/5 SDIO straps unused; GPIO15 ignored with default JTAG eFuses. Firmware assigns charging, connection and fault indications.
Reset / enable
Download boot

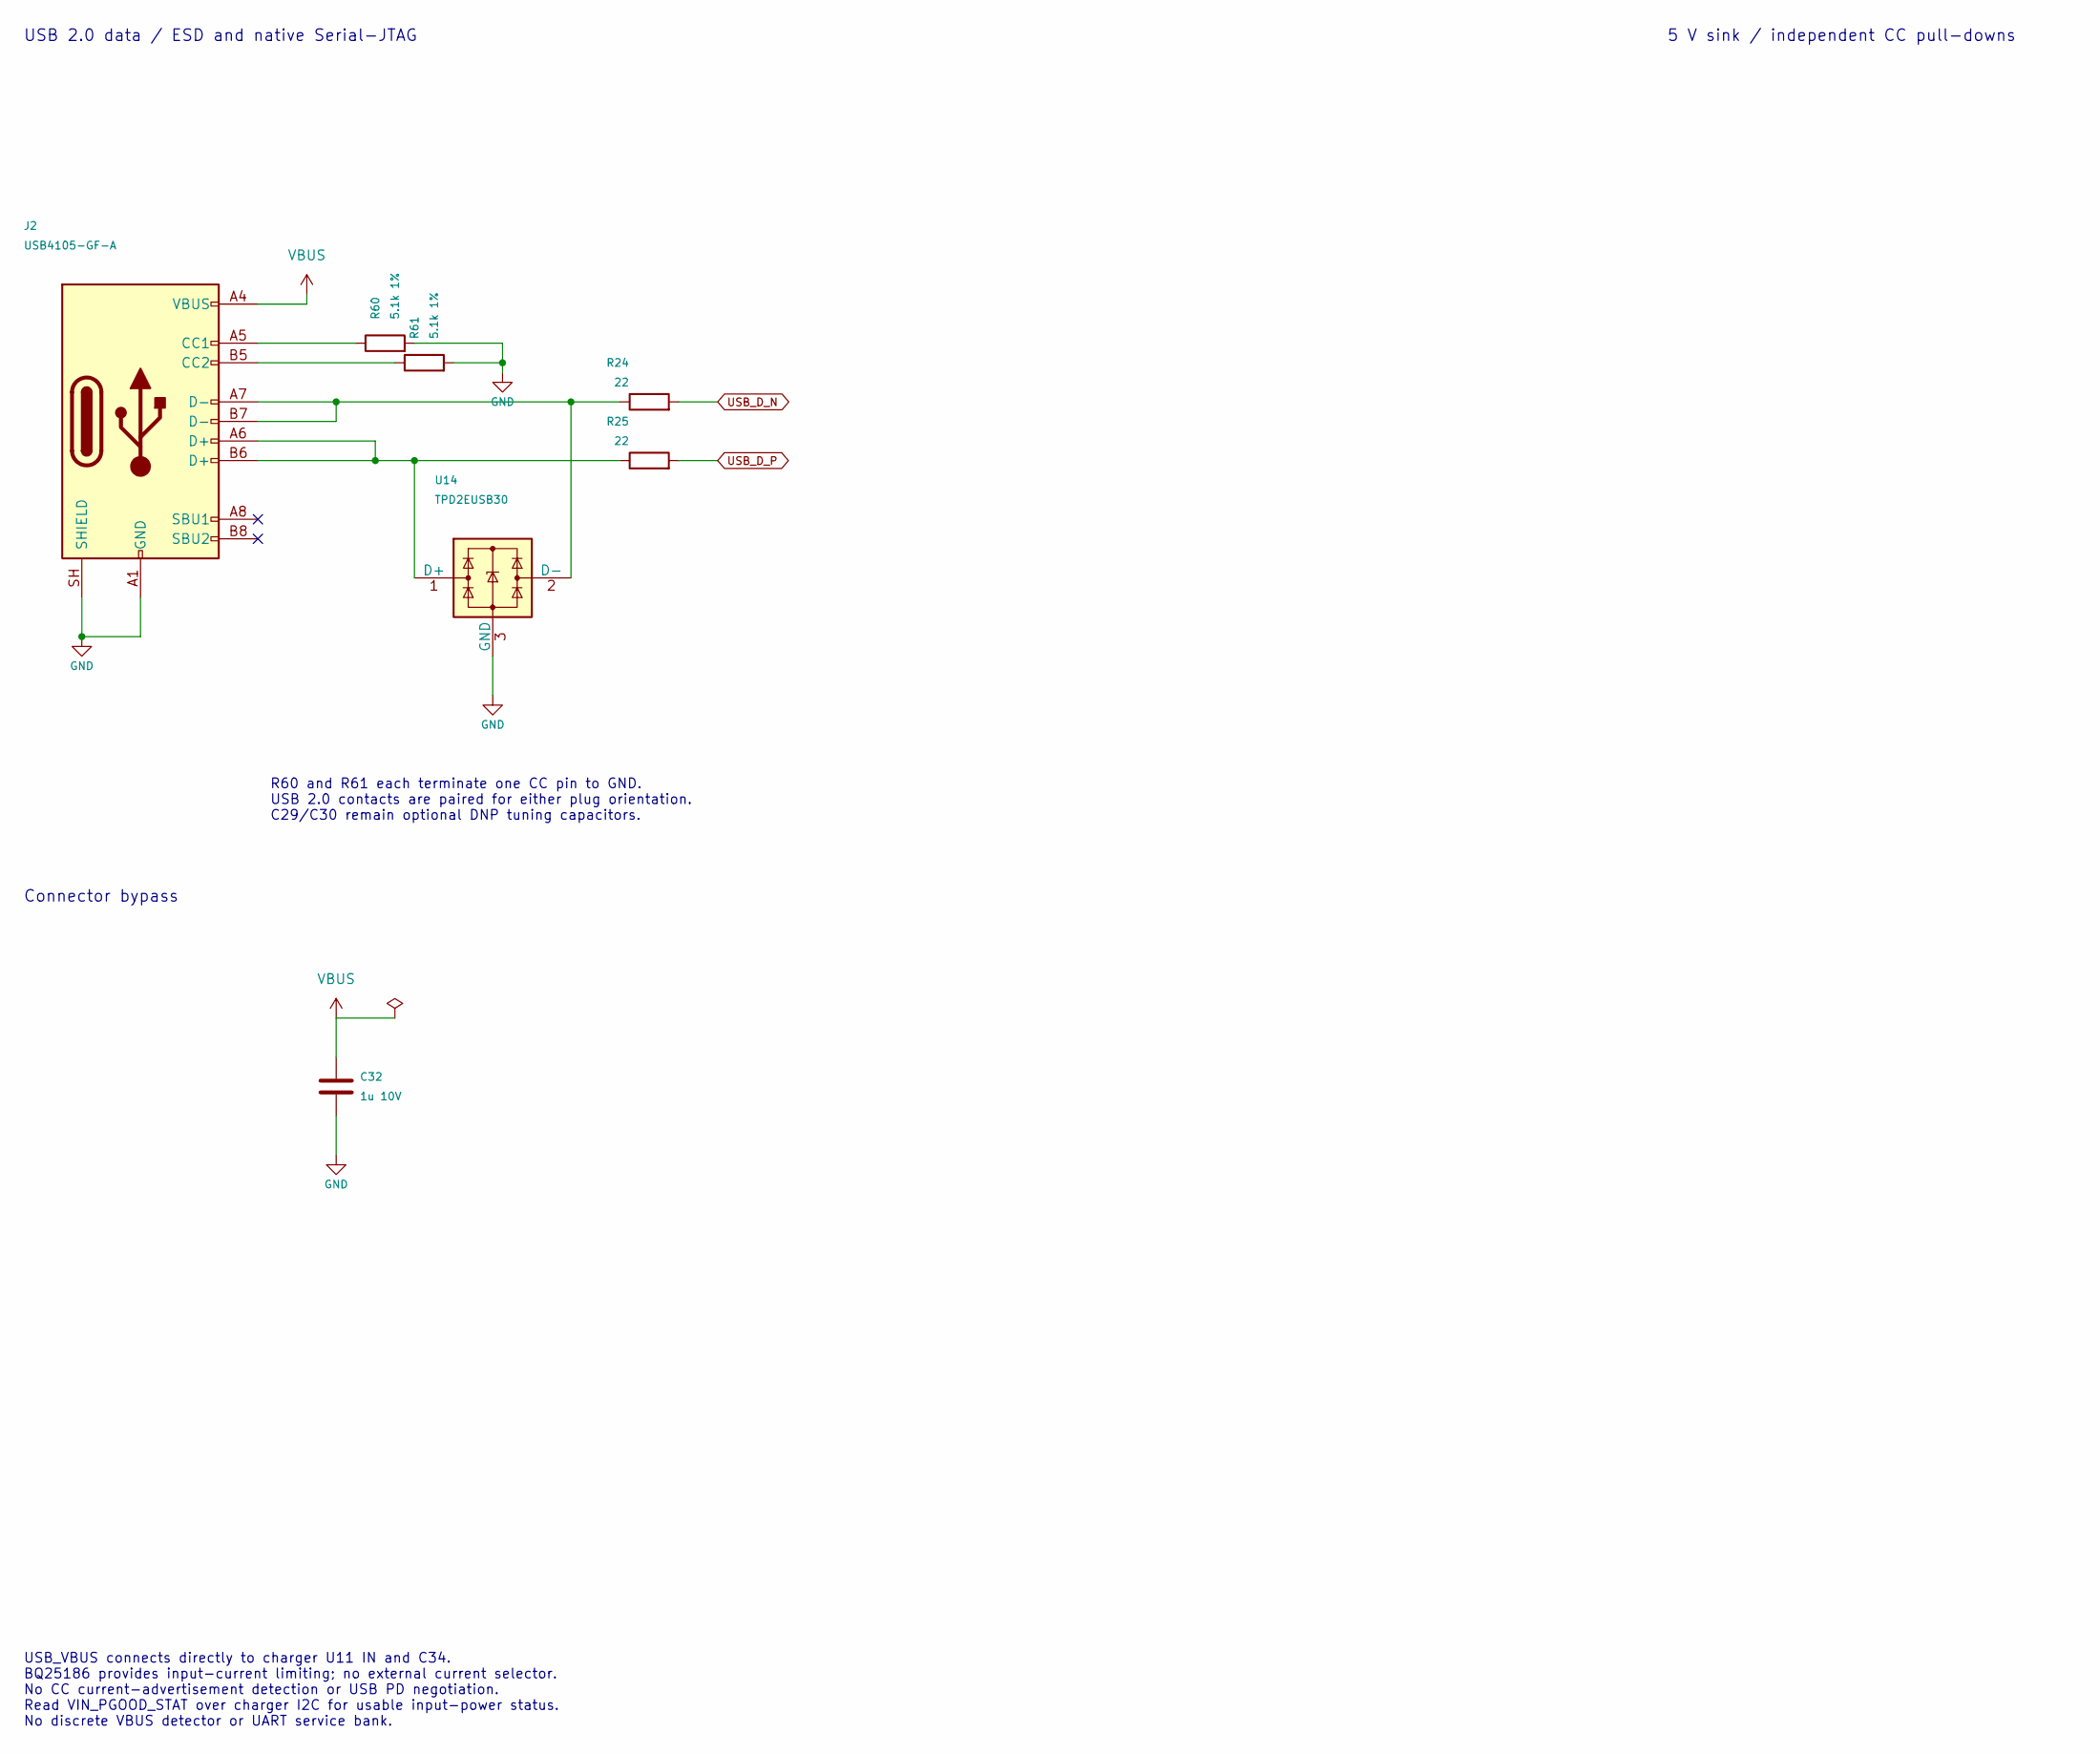
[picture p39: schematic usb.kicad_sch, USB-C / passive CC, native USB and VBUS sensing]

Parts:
C32: 1u 10V; C_0603_1608Metric
J2: USB4105-GF-A; USB_C_Receptacle_GCT_USB4105-xx-A_16P_TopMnt_Horizontal; MPN USB4105-GF-A
R24, R25: 22; R_0402_1005Metric
R60, R61: 5.1k 1%; R_0402_1005Metric
U14: TPD2EUSB30; Texas_DRT-3; MPN TPD2EUSB30DRTR

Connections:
GND: C32.2, J2.A1 (GND), J2.A12 (GND), J2.B1 (GND), J2.B12 (GND), J2.SH (SHIELD), R60.2, R61.2, U14.3 (GND); also elsewhere on the board
unnamed 19: J2.A5 (CC1), R60.1; also elsewhere on the board
unnamed 20: J2.B5 (CC2), R61.1; also elsewhere on the board
unnamed: J2.A6 (D+), J2.B6 (D+), R25.1, U14.1 (D+)
unnamed: J2.A7 (D-), J2.B7 (D-), R24.1, U14.2 (D-)
USB_D_N: R24.2; also elsewhere on the board
USB_D_P: R25.2; also elsewhere on the board
VBUS: C32.1, J2.A4 (VBUS), J2.A9 (VBUS), J2.B4 (VBUS), J2.B9 (VBUS); also elsewhere on the board

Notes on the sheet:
5 V sink / independent CC pull-downs
USB 2.0 data / ESD and native Serial-JTAG
R60 and R61 each terminate one CC pin to GND. USB 2.0 contacts are paired for either plug orientation. C29/C30 remain optional DNP tuning capacitors.
Connector bypass
USB_VBUS connects directly to charger U11 IN and C34. BQ25186 provides input-current limiting; no external current selector. No CC current-advertisement detection or USB PD negotiation. Read VIN_PGOOD_STAT over charger I2C for usable input-power status. No discrete VBUS detector or UART service ban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

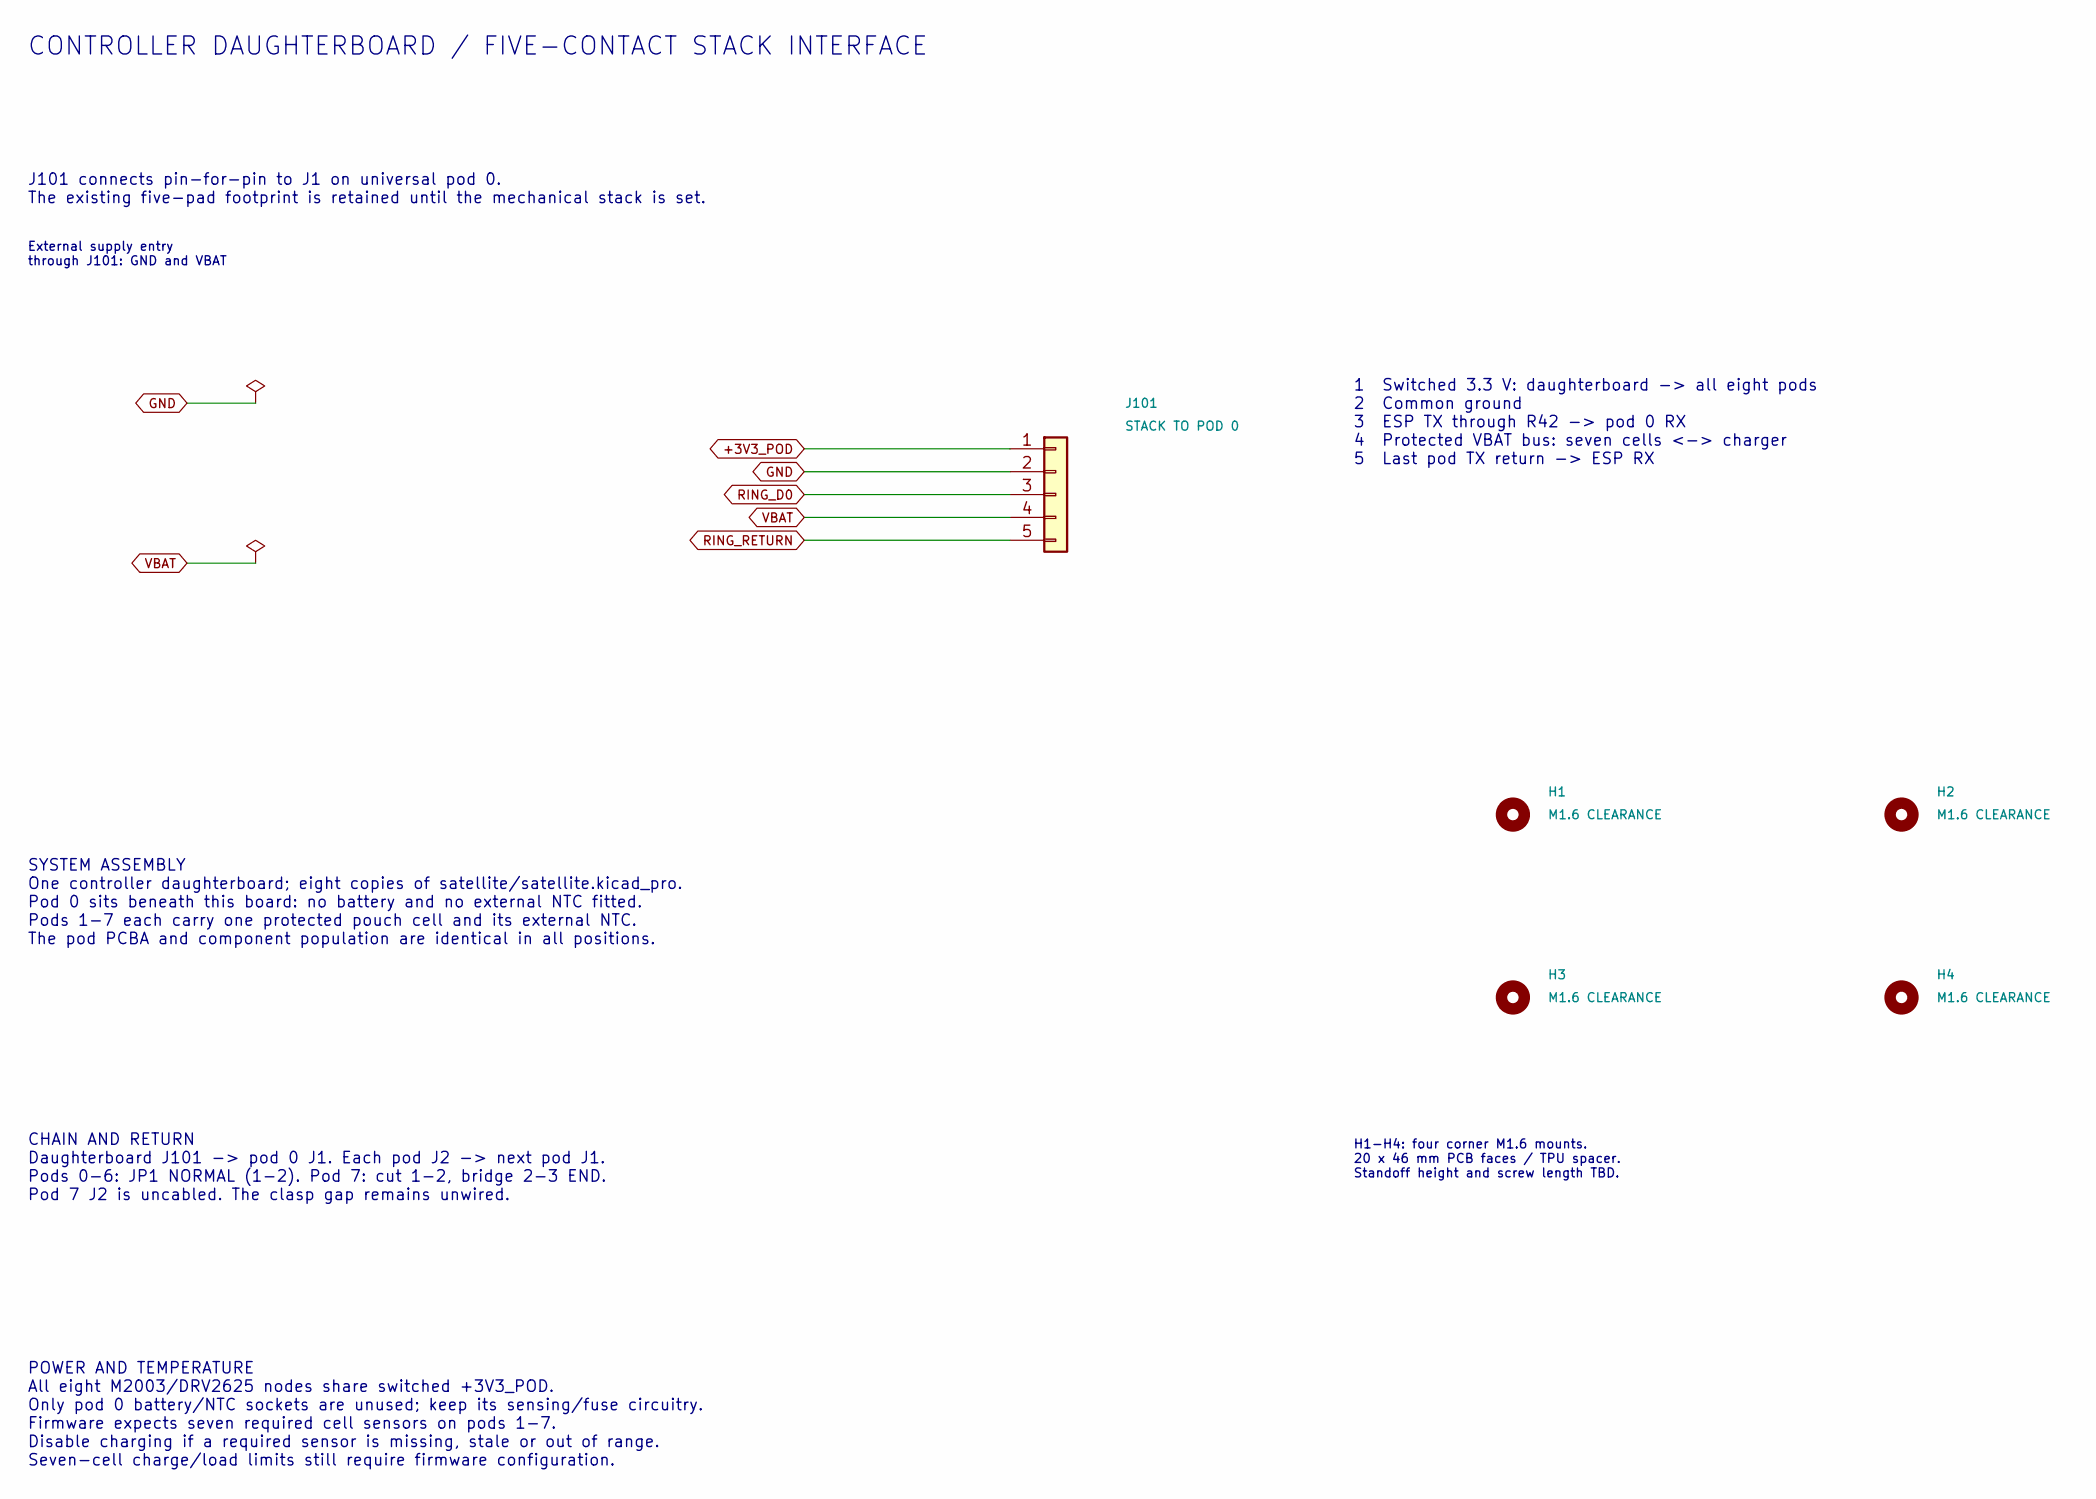
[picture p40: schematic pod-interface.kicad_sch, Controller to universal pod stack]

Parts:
H1, H2, H3, H4: M1.6 CLEARANCE; Screw_Clearance_M1p6_1p8mm_Stack
J101: STACK TO POD 0; WirePads_5_P2mm

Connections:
+3V3_POD: J101.1; also elsewhere on the board
GND: J101.2; also elsewhere on the board
RING_D0: J101.3; also elsewhere on the board
RING_RETURN: J101.5; also elsewhere on the board
VBAT: J101.4; also elsewhere on the board

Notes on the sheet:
H1-H4: four corner M1.6 mounts. 20 x 46 mm PCB faces / TPU spacer. Standoff height and screw length TBD.
External supply entry through J101: GND and VBAT
1 Switched 3.3 V: daughterboard -> all eight pods 2 Common ground 3 ESP TX through R42 -> pod 0 RX 4 Protected VBAT bus: seven cells <-> charger 5 Last pod TX return -> ESP RX
CONTROLLER DAUGHTERBOARD / FIVE-CONTACT STACK INTERFACE
CHAIN AND RETURN Daughterboard J101 -> pod 0 J1. Each pod J2 -> next pod J1. Pods 0-6: JP1 NORMAL (1-2). Pod 7: cut 1-2, bridge 2-3 END. Pod 7 J2 is uncabled. The clasp gap remains unwired.
SYSTEM ASSEMBLY One controller daughterboard; eight copies of satellite/satellite.kicad_pro. Pod 0 sits beneath this board: no battery and no external NTC fitted. Pods 1-7 each carry one protected pouch cell and its external NTC. The pod PCBA and component population are identical in all positions.
J101 connects pin-for-pin to J1 on universal pod 0. The existing five-pad footprint is retained until the mechanical stack is set.
POWER AND TEMPERATURE All eight M2003/DRV2625 nodes share switched +3V3_POD. Only pod 0 battery/NTC sockets are unused; keep its sensing/fuse circuitry. Firmware expects seven required cell sensors on pods 1-7. Disable charging if a required sensor is missing, stale or out of range. Seven-cell char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

Board: 4 copper layers, 52 parts (3 on the bottom side), 36 nets, no tracks yet.

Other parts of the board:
U15: TPD2EUSB30; Texas_DRT-3

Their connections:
GND: U15.3 (GND); also elsewhere on the board
unnamed 19: U15.1 (D+); also elsewhere on the board
unnamed 20: U15.2 (D-); also elsewhere on the board

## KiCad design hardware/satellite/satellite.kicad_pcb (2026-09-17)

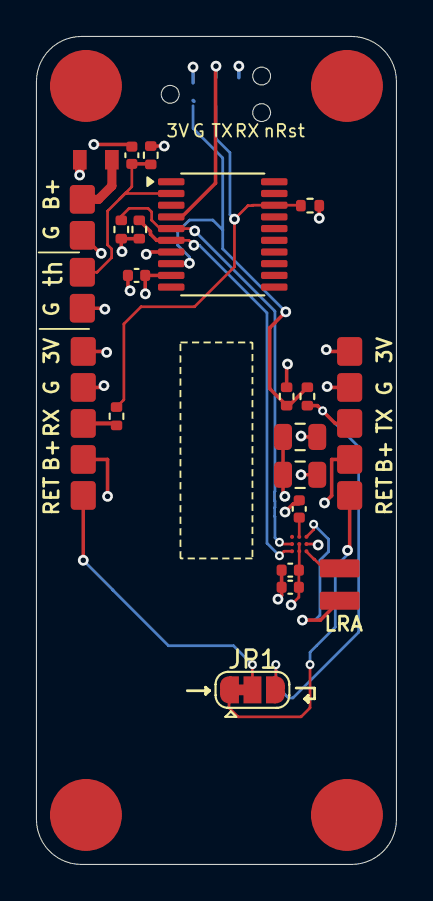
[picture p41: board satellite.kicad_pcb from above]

Board: 4 copper layers, 20.0 x 46.0 mm, 28 parts (1 on the bottom side), 17 nets.

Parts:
C1, C5, C6: 100n; C_0402_1005Metric
C2: 10u; C_0805_2012Metric
C3: 22u 10V X5R; C_0805_2012Metric
C4: 10n; C_0402_1005Metric
C7: 1u; C_0402_1005Metric
F1: 250mA FAST; Fuse_Littelfuse_467_0603
H1, H2, H3, H4: M1.6 STANDOFF; SMT_Standoff_M1p6_D3p3_ClosedBase_HeightTBD
J1: CHAIN IN; WirePads_5_P2mm
J2: CHAIN OUT; WirePads_5_P2mm
J4: PROTECTED CELL 90mAh; WirePads_2_P2mm
J5: NTC (optional); WirePads_2_P2mm
J6: Conn_ARM_SWD_TagConnect_TC2030-NL; Tag-Connect_TC2030-IDC-NL_2x03_P1.27mm_Vertical
JP1: RETURN SELECT; SolderJumper-3_P1.3mm_Bridged12_RoundedPad1.0x1.5mm
M1: VLV041235L; Vybronics_VLV041235L_FPC_Contact_Draft
R1: 0; R_0402_1005Metric
R2: 33; R_0402_1005Metric
R3, R4: 100k; R_0402_1005Metric
R5: 10k 1%; R_0402_1005Metric
R6, R7: 4.7k; R_0402_1005Metric
U1: M2003FC1AE; TSSOP-20_4.4x6.5mm_P0.65mm
U2: DRV2625; DRV2625_YFF_9_0.4mm

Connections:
+3V3_POD: C1.1, C2.1, C3.1, C5.1, C7.1, J1.1, J2.1, J6.1 (VCC), R3.1, R4.1, R5.1, R6.1, R7.1, U1.9 (VDD), U2.B2 (NRST), U2.C2 (VDD)
/LOCAL_nRESET: J6.3 (~RESET), U1.4 (PE15_/_nRESET)
/RETURN_DOWN: J2.5, JP1.1 (A)
/RETURN_UP: J1.5, JP1.2 (C)
/RING_RX: J1.3, R1.1
/TX_OUT: J2.3, JP1.3 (B), R2.2
/UART_RX_LOCAL: J6.4 (SWCLK), R1.2, R3.2, U1.18 (PF1_/_RXD1_/_ICE_CLK)
/UART_TX_LOCAL: J6.2 (SWDIO), R2.1, R4.2, U1.8 (PF0_/_TXD1_/_ICE_DAT)
GND: C1.2, C2.2, C3.2, C4.2, C5.2, C6.2, C7.2, J1.2, J2.2, J4.2, J5.2, J6.5 (GND), U1.7 (VSS), U2.B3 (GND)
unnamed: F1.1, J4.1
unnamed: C4.1, J5.1, R5.2, U1.2 (PB2_/_ADC0_CH2)
unnamed: M1.1 (+), U2.A3 (OUT+)
unnamed: M1.2 (-), U2.C3 (OUT-)
unnamed: R6.2, U1.5 (PB4_/_I2C0_SDA), U2.B1 (SDA)
unnamed: R7.2, U1.6 (PB5_/_I2C0_SCL), U2.C1 (SCL)
unnamed: C6.1, U2.A2 (REG)
VBAT: F1.2, J1.4, J2.4

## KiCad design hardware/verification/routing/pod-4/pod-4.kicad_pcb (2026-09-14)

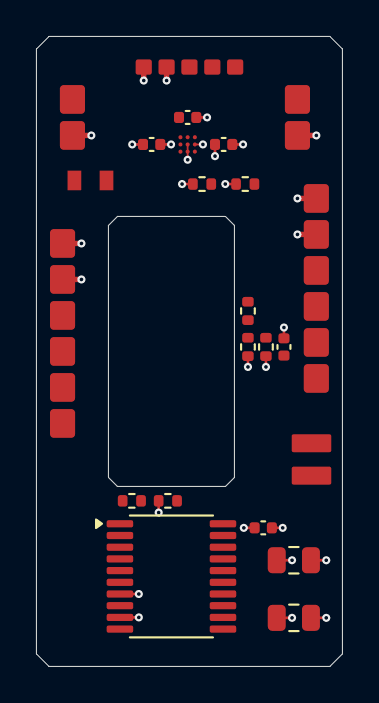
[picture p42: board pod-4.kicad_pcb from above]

Board: 4 copper layers, 17.0 x 35.0 mm, 23 parts (0 on the bottom side), 16 nets.

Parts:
C17, C18, C140: 100n; C_0402_1005Metric
C19: 1u; C_0402_1005Metric
C141: 10u; C_0805_2012Metric
C142: 10n; C_0402_1005Metric
C143: 22u 10V X5R; C_0805_2012Metric
F104: 250mA FAST; Fuse_Littelfuse_467_0603
J116: CHAIN IN; WirePads_6_P2mm
J117: CHAIN OUT; WirePads_6_P2mm
J118: ICE / INITIAL FLASH; WirePads_5_P1.27mm
J119: NTC (optional); WirePads_2_P2mm
J204: PROTECTED CELL 90mAh; WirePads_2_P2mm
M5: VLV041235L; Vybronics_VLV041235L_FPC_Contact_Draft
R16, R17: 4.7k; R_0402_1005Metric
R140: 0; R_0402_1005Metric
R141: 33; R_0402_1005Metric
R142, R143: 100k; R_0402_1005Metric
R145: 10k 1%; R_0402_1005Metric
U7: DRV2625; DRV2625_YFF_9_0.4mm
U22: M2003FC1AE; TSSOP-20_4.4x6.5mm_P0.65mm

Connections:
/Eight ring pods/Pod 4 / U22/CELL_POS: F104.1, J204.1
/Eight ring pods/Pod 4 / U22/CELL_TEMP: C142.1, J119.1, R145.2, U22.2
/Eight ring pods/Pod 4 / U22/DRV_REG: C18.1, U7.A2
/Eight ring pods/Pod 4 / U22/LOCAL_SCL: R17.2, U7.C1, U22.6
/Eight ring pods/Pod 4 / U22/LOCAL_SDA: R16.2, U7.B1, U22.5
/Eight ring pods/Pod 4 / U22/LRA_N: M5.2, U7.C3
/Eight ring pods/Pod 4 / U22/LRA_P: M5.1, U7.A3
/Eight ring pods/Pod 4 / U22/UART_RX_LOCAL: J118.4, R140.2, R142.2, U22.18
/Eight ring pods/Pod 4 / U22/UART_TX_LOCAL: J118.3, R141.1, R143.2, U22.8
GND: C17.2, C18.2, C19.2, C140.2, C141.2, C142.2, C143.2, J116.2, J117.2, J118.2, J119.2, J204.2, U7.B3, U22.7
POD_3V3: C17.1, C19.1, C140.1, C141.1, C143.1, J116.1, J117.1, J118.1, R16.1, R17.1, R142.1, R143.1, R145.1, U7.B2, U7.C2, U22.9
RING_D4: J116.3, R140.1
RING_D5: J117.3, R141.2
RING_RETURN: J116.6, J117.6
RING_nRESET: J116.4, J117.4, J118.5, U22.4
VBAT: F104.2, J116.5, J117.5

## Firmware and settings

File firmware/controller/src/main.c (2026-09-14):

#include <stdbool.h>
#include <stdint.h>
#include <string.h>

#include "driver/gpio.h"
#include "esp_check.h"
#include "esp_log.h"
#include "freertos/FreeRTOS.h"
#include "freertos/task.h"

#include "backpack_rx.h"
#include "board.h"
#include "bringup_console.h"
#include "hb_attitude_map.h"
#include "ring_master.h"

#define CONTROL_PERIOD_MS 20u
#define ATTITUDE_STALE_MS 250u

static const char *TAG = "bracelet";

static void set_led(bool red, bool green, bool blue)
{
    /* Common-anode LED: GPIO low turns a channel on. */
    gpio_set_level(HB_PIN_LED_RED, red ? 0 : 1);
    gpio_set_level(HB_PIN_LED_GREEN, green ? 0 : 1);
    gpio_set_level(HB_PIN_LED_BLUE, blue ? 0 : 1);
}

static void safe_main_io_init(void)
{
    const gpio_config_t output_config = {
        .pin_bit_mask = (1ULL << HB_PIN_CHG_ALLOW) |
                        (1ULL << HB_PIN_LED_RED) |
                        (1ULL << HB_PIN_LED_GREEN) |
                        (1ULL << HB_PIN_LED_BLUE),
        .mode = GPIO_MODE_OUTPUT,
        .pull_up_en = GPIO_PULLUP_DISABLE,
        .pull_down_en = GPIO_PULLDOWN_DISABLE,
        .intr_type = GPIO_INTR_DISABLE
    };
    ESP_ERROR_CHECK(gpio_config(&output_config));
    gpio_set_level(HB_PIN_CHG_ALLOW, 0); /* Charging is not enabled in v0.1. */
    set_led(false, false, false);
}

void app_main(void)
{
    bool ring_online;
    bool output_active = false;
    uint8_t sequence = 0u;

    safe_main_io_init();
    set_led(false, false, true);
    ring_online = hb_ring_master_start();
    if (hb_backpack_rx_init() != ESP_OK)
        ESP_LOGE(TAG, "Backpack initialization failed");
    if (hb_bringup_console_start() != ESP_OK)
        ESP_LOGE(TAG, "USB bring-up console initialization failed");

    if (!ring_online) {
        set_led(true, false, false);
        ESP_LOGE(TAG, "safe fault: pod rail disabled");
    } else {
        set_led(false, false, true);
    }

    for (;;) {
        hb_attitude_t attitude;
        uint32_t age_ms = UINT32_MAX;
        bool fresh;

        if (hb_bringup_console_manual_active()) {
            if (output_active) {
                (void)hb_ring_master_all_stop();
                output_active = false;
            }
            set_led(false, false, true);
            vTaskDelay(pdMS_TO_TICKS(CONTROL_PERIOD_MS));
            continue;
        }

        fresh = hb_ring_master_flight_ready() &&
                      hb_backpack_latest(&attitude, &age_ms) &&
                      age_ms <= ATTITUDE_STALE_MS;

        if (fresh) {
            uint8_t amplitudes[HB_RING_POD_COUNT];
            hb_attitude_to_amplitudes(&hb_attitude_map_bringup, &attitude,
                                      amplitudes);
            if (!hb_ring_master_send_haptics(sequence++, amplitudes)) {
                ESP_LOGE(TAG, "ring echo lost; powering pods down");
                hb_ring_master_shutdown();
                output_active = false;
                set_led(true, false, false);
            } else {
                output_active = true;
                set_led(false, true, false);
            }
        } else if (output_active) {
            (void)hb_ring_master_all_stop();
            output_active = false;
            set_led(false, false, true);
        }
        vTaskDelay(pdMS_TO_TICKS(CONTROL_PERIOD_MS));
    }
}

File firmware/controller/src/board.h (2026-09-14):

#ifndef HB_BOARD_H
#define HB_BOARD_H

#define HB_PIN_RING_TX          19
#define HB_PIN_RING_RX          2
#define HB_PIN_POD_POWER_ON     3
#define HB_PIN_CHG_ALLOW        20
#define HB_PIN_CHG_NINT         21
#define HB_PIN_I2C_SDA          6
#define HB_PIN_I2C_SCL          7
#define HB_PIN_LED_RED          4
#define HB_PIN_LED_GREEN        5
#define HB_PIN_LED_BLUE         15

#define HB_RING_UART_BAUD       250000
#define HB_POD_STARTUP_SETTLE_MS 30
#define HB_LDROM_WINDOW_MS      1100

#endif

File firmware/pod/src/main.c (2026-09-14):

#include <stdint.h>

#include "M2003.h"
#include "app_uart.h"
#include "boot_control.h"
#include "drv2625.h"
#include "ring_protocol.h"
#include "wdt.h"

#define CORE_CLOCK_HZ 24000000u
#define UART_BAUD 250000u

volatile uint32_t hb_millis;
static volatile uint8_t main_alive;

void Uart0DefaultMPF(void) { }

void SysTick_Handler(void)
{
    ++hb_millis;
    if (main_alive) {
        main_alive = 0u;
        WDT_RESET_COUNTER();
    }
}

void HardFault_Handler(void)
{
    NVIC_SystemReset();
    for (;;) { }
}

void NMI_Handler(void)
{
    NVIC_SystemReset();
    for (;;) { }
}

static void hardware_init(void)
{
    CLK->PWRCTL |= CLK_PWRCTL_HIRCEN_Msk | CLK_PWRCTL_LIRCEN_Msk;
    while ((CLK->STATUS & (CLK_STATUS_HIRCSTB_Msk | CLK_STATUS_LIRCSTB_Msk)) !=
           (CLK_STATUS_HIRCSTB_Msk | CLK_STATUS_LIRCSTB_Msk)) { }
    CLK->CLKSEL0 = (CLK->CLKSEL0 & ~CLK_CLKSEL0_HCLKSEL_Msk) |
                   CLK_CLKSEL0_HCLKSEL_HIRC;
    CLK->CLKDIV0 = (CLK->CLKDIV0 & ~CLK_CLKDIV0_HCLKDIV_Msk) |
                   CLK_CLKDIV0_HCLK(1);
    CLK->AHBCLK |= CLK_AHBCLK_GPBCKEN_Msk | CLK_AHBCLK_GPFCKEN_Msk;
    SystemCoreClock = CORE_CLOCK_HZ;
    SysTick_Config(CORE_CLOCK_HZ / 1000u);
    NVIC_SetPriority(SysTick_IRQn, 2u);

    CLK->CLKSEL1 = (CLK->CLKSEL1 & ~CLK_CLKSEL1_WDTSEL_Msk) |
                   CLK_CLKSEL1_WDTSEL_LIRC;
    CLK->APBCLK0 |= CLK_APBCLK0_WDTCKEN_Msk;
    WDT_Open(WDT_TIMEOUT_2POW14, WDT_RESET_DELAY_18CLK, TRUE, FALSE);
}

static void delay_ms(uint32_t duration)
{
    uint32_t start = hb_millis;
    while ((uint32_t)(hb_millis - start) < duration) main_alive = 1u;
}

int main(void)
{
    uint32_t previous_ms;
    hardware_init();
    uart_init(UART_BAUD);
    ring_protocol_init();
    delay_ms(2u); /* DRV2625 requires NRST high for at least 1 ms. */
    drv2625_init(hb_millis);
    previous_ms = hb_millis;

    for (;;) {
        uint32_t now = hb_millis;
        main_alive = 1u;
        ring_protocol_poll();
        if (now != previous_ms) {
            uint32_t elapsed = now - previous_ms;
            previous_ms = now;
            ring_protocol_tick(elapsed, now);
            drv2625_poll(now);
        }
        if (boot_control_pending()) boot_control_enter();
    }
}

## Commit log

2026-09-14 Initial ELRS haptic bracelet hardware and firmware
    [LRA-body-4x12x3p5.stl, bridge.dsn, candidate.kicad_pcb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]
2026-09-17 PCB housing
    [closure-coupon-rigid.stl, closure-coupon-tpu.stl, closure-transition-coupon.3mf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]
